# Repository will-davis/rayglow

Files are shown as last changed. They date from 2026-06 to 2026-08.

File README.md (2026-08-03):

# RayGLow

Audio-reactive GLSL visuals on a custom RGB LED wall. Music plays on a desktop; a small
daemon there reduces it to per-frame audio *features* and unicasts them over UDP to a
Raspberry Pi 5, which renders Shadertoy-dialect GLSL on its GPU, packs each frame, and
ships it over a **4-lane parallel bus** to an **RP2350b** microcontroller whose PIO+DMA
engine drives the HUB75 panels with zero-CPU, jitter-free timing. Write a shader, paste
it in, watch it move to the music.

https://github.com/user-attachments/assets/fb1bfaf4-e451-43c7-8cc3-830d7c186d91

```
desktop (optional)                 Raspberry Pi 5                         RP2350b PiZero + HAT
┌────────────────────────┐         ┌────────────────────────────┐         ┌───────────────────────┐
│ music ▶ sink monitor   │  UDP    │ feed.receiver (latest-win) │  4-lane │ phase6: PIO+DMA RX    │
│ sender.py: FFT ▶ bands │ ──────▶ │ render: GLSL ▶ pack        │   bus   │ zero-CPU scan-out     │
│ + flywheels/beat/key   │  :5005  │ (to_chains ▶ hub75.pack)   │ ──────▶ │ ▶ HUB75 ▶ 384×128 wall│
│ ▶ 2996-B v3 @ ~60 Hz   │ ~180KB/s│ headless EGL + GLES3       │ 192 KB  │ (2 chains × 12 panels)│
└────────────────────────┘         └────────────────────────────┘         └───────────────────────┘
        point $RAYGLOW_HOST ──────────────▶ your Pi
```

The three stages live in **one repo**. The desktop and Pi halves are Python: the desktop
runs `sender/`, the Pi runs the `rayglow` package installed editable (`pip install -e`)
from a copy of this repo — get it there however you like (`git pull`, or a continuous
file sync such as mutagen/sshfs for live shader editing). The RP2350b half is Rust
firmware (`firmware/`) flashed onto the board, plus a custom level-shifting HAT
(`hardware/`).
First-time setup is in [Deploy](#deploy); full credits and licensing are in
[ATTRIBUTION.md](ATTRIBUTION.md) (RayGLow is **MIT** — see [LICENSE](LICENSE)).

The desktop sender is **optional**: `rayglow.fake_sender` synthesizes the same packet
struct, so the Pi can drive the wall with no music source at all.

## Why features, not streamed audio

Streaming PCM means reconstructing a continuous signal on the far end: ring buffers,
clock-drift resampling, jitter buffers. Features are **stateless per frame** — a lost or
late packet just means the Pi renders with the previous values, and at 60 Hz one held
frame is invisible. The Pi does zero audio work, the wire carries ~0.25 MB/s, and UDP
gets used the way UDP wants to be used.

## Why offload scan-out to the RP2350b

Bit-banging HUB75 from a Linux SoC fights the scheduler — it needs a dedicated RT core
and still jitters (the Pi 5's RP1 southbridge made it worse). The RP2350b runs the refresh
loop entirely in **3 PIO state machines + 4 self-chaining DMA channels**, with the CPU
never touching the pixel path. The Pi renders at whatever rate it likes and ships 192 KB
frames over the link — already gamma-corrected on the Pi (the GPU resolve pass bakes
the firmware `lut.rs` CIE curve into each frame; `--readback legacy` instead applies
the packer's bit-exact LUT replica to a LINEAR readback); the RP2350b holds a
rock-steady, flicker-free refresh.

## Why a parallel bus, not SPI

The link was originally 1-lane SPI, and SPI still works as the proven fallback
(`--transport spi`). But a frame takes ~13 ms at 40 MHz SPI even at the v1 wall's 64 KB —
~39 ms at the v2 wall's 192 KB — long enough to sit squarely
on the critical path. A **4-lane source-synchronous parallel bus**, clocked out by the
Pi 5's RP1 PIO block, drops that to ~2 ms (clkdiv 3; ~1.3 ms at clkdiv 2). Only the wire
changes: the byte stream is identical to the SPI path (same `hub75.py` packer output,
same READY handshake), so the firmware and packer don't change. (4 lanes, not 8: the RP2350b scan-out engine owns
GP0–18, leaving GP19–27 for the link.) See
[`rayglow/render/piobridge/README.md`](rayglow/render/piobridge/README.md).

## Hardware

RayGLow custom HAT

A **Waveshare RP2350-PiZero** on a custom HAT that level-shifts (3.3 V → 5 V via
`SN74AHCT245`) and breaks out two HUB75 chains + the Pi↔RP2350b link. Design files, the
KiCad project, and fab Gerbers are in [`hardware/`](hardware/).

## Repo layout

| path | what |
|---|---|
| `sender/` | **desktop half** — the feature daemon (`sender.py`), its own uv project (numpy + sounddevice). [sender/README.md](sender/README.md) has the protocol + feature detail. |
| `rayglow/feed/` | the audio-feature feed: packet `receiver`, `FeatureState`, and the rig `config` (geometry/network/gamma). Shared, dependency-free. |
| `rayglow/render/` | **the live renderer** — headless EGL + GLES3, multipass pipeline, iChannel textures (`audio`, `milk`, noise, images), hot reload, a TCP **control plane** (`control.py`: push/switch shaders + media controls), the GPU resolve pass + zero-copy dma-heap readback (`output.py`, `dmabuf.py`), the frame packer (`hub75.py`) + link backends (`spi_out.py`, `pio_out.py` / `piobridge/`), and `presets/*.glsl`. |
| `rayglow/fake_sender.py` | music-free test harness; emits the same packet struct with synthesized features. |
| `rayglow/link.py` | **remote render wire contract** — frame fragments out, flip credits back (UDP, latest-wins, credit-paced; see [REMOTE-RENDER-PLAN.md](REMOTE-RENDER-PLAN.md)). Shared by `render/net_out.py` (`--output net`) and `framesink`. |
| `rayglow/framesink.py` | the Pi when rendering happens elsewhere: reassemble frames → `drm_out` page flip → credit per vblank. A socket and a memcpy — no GL stack. |
| `rayglow.example.toml` | per-machine CLI defaults (`rayglow/userconf.py`): pin each machine's flags (`output`, `net-host`, `window`, …) in `~/.config/rayglow/config.toml` so production launches are just `python -m rayglow.render <shader>` / `python -m rayglow.framesink`. CLI flags always override. |
| `rayglow/spi_test.py` | static test pattern (no GL) — isolates the link/firmware/cabling from the renderer. Per-panel ID markers confirm the serpentine fold; runs over either transport. |
| `firmware/` | **RP2350b Rust firmware** — zero-CPU PIO+DMA HUB75 scan-out, brought up in verifiable phases. [firmware/README.md](firmware/README.md). |
| `hardware/` | **custom HAT** — KiCad project, Gerbers, and the locked net/pinout spec. [hardware/README.md](hardware/README.md). |
| `tools/` | `verify.py` — proves the Python packer (`render/hub75.py`) is byte-identical to the firmware via a Rust golden frame. `fold_check.py` — proves the serpentine fold + the geometry/SRAM contract from the desk. `link_check.py` — locks the remote-render frame link (fragments/credits/pacing) over loopback. `dmabuf_probe.py` — the readback benchmark. |
| `ROADMAP.md` | queued workstreams — the living handoff doc between working sessions. |
| `docs/design-history/` | the original project record (MilkDrop reverse-engineering, the RP2350 plan, the build-history brain-dump). Superseded by the docs above where they disagree. |

## Quickstart

**Desktop (sender, optional):**
```fish
cd sender
set -x RAYGLOW_HOST 192.168.0.50   # your Pi's IP (or pass --host); see LOCAL-SETUP.example.md
uv run sender.py                   # capture default sink's monitor -> the Pi
uv run sender.py --list-sources    # enumerate pulse sources
uv run sender.py --debug           # + raw pre-normalization band energies
```

**Pi (renderer)** — see [Deploy](#deploy) for first-time setup:
```fish
# headless, no root, no hardware: render -> animated GIF (works on a desktop GPU too)
python -m rayglow.render rayglow/render/presets/milk-verbose.glsl --dry-run 120 --no-listen

# on the Pi, driving the panels (root for GPIO):
sudo ~/venv/bin/python -m rayglow.render rayglow/render/presets/milk-verbose.glsl
```
`milk-verbose.glsl` is the live-feed reference card — every audio feature drawn as a
labeled bar. Run the sender on the desktop at the same time to see it react.

## Deploy

**Renderer (Raspberry Pi 5).** The Pi runs the same git checkout, installed editable into
a uv venv:

```fish
# on the Pi, first time:
git clone <your-fork-url> ~/rayglow
cd ~/rayglow
uv venv ~/venv
uv pip install --python ~/venv/bin/python -e '.[pi]'   # core + Pi link deps
# thereafter: update the checkout (git pull, or let your file sync — e.g. a
# mutagen session pushing from the dev machine — keep it current)
```

`.[pi]` pulls the Pi-only deps (`spidev`, `gpiozero`, `lgpio`); EGL/GLES come from system
libraries, not pip. Editable install (not `PYTHONPATH`) because `sudo` scrubs the
environment but respects the installed package; hardware mode keeps root for GPIO and to
re-read shader files on hot reload, so the clone must live somewhere root can read (e.g.
under `~`).

- **Parallel link (default, `--transport pio`):** build `piobridge/libpioshim.so`
  against the RP1 `piolib` first — see
  [`rayglow/render/piobridge/README.md`](rayglow/render/piobridge/README.md).
- **SPI fallback (`--transport spi`):** enable SPI and make sure
  `/sys/module/spidev/parameters/bufsiz >= 196608` so the v2 wall's 192 KB frame goes in
  one transfer (the default 4096 is far too small; size it to `hub75.FRAME_BYTES`).

Per-machine addresses/paths: see [`LOCAL-SETUP.example.md`](LOCAL-SETUP.example.md).

**Firmware (RP2350b).** Flash the board once: `phase6-parallel --features two-chain`
for the 4-lane bus (production) or `phase5-spi` for the SPI fallback. Toolchain
bootstrap and `cargo run`/`probe-rs` instructions are in
[`firmware/README.md`](firmware/README.md).

## Status

Working end-to-end: the desktop sender feeds the renderer, which packs frames the
firmware accepts byte-for-byte (`tools/verify.py` is green). The renderer hot-reloads
`.glsl` files live (edit, save, watch the panel recompile); for the fast dev loop a TCP
control plane (`tools/rayglow_ctl.py push`, or the `tools/nvim-rayglow.lua` save-hook)
ships edits straight to the running renderer in <100ms — skipping the file-sync lag —
and adds media controls (next/prev/play/pause/loop) plus live per-shader supersample
scale (`// rayglow: scale=N` directive or `rayglow-ctl scale`). The Phase 6 4-lane parallel
bus is the production transport (hardware-verified on the custom HAT driving the 256×64 v1
wall; the 384×128 v2 wall is in bring-up — host + firmware ship, cabling/SI pending, see
ROADMAP §5); the Phase 5 SPI link remains the proven fallback. A microphone input path
exists (`sender/esp32-mic/` + `sender/espnow-dongle/`). Next: pulling config into a
user-editable yaml so the project runs on someone else's wall/network by editing one
file.

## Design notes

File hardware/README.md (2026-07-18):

# RayGLow hardware — RP2350-HUB75 HAT

The custom PCB that sits between the **Waveshare RP2350-PiZero** dev board and the
LED wall. It is deliberately minimal: it does **3.3 V → 5 V level-shifting** of all
HUB75 logic (via `SN74AHCT245` buffers), presents the **two HUB75 connectors**
(chains A & B = one 256×64 tile), breaks out the spare GPIO + power on J4 — which
now carries the Pi 5 ↔ RP2350 **4-lane parallel link** (DATA0–3/DCLK/READY, see
[`../rayglow/render/piobridge/README.md`](../rayglow/render/piobridge/README.md);
designed pre-fab as an SPI/sync breakout, same pins) — and carries a dedicated 5 V
rail for the buffers. It does **not**
power the panels (their 5 V goes straight to the panel lugs) and contains no MCU
support circuitry — the dev board owns crystal/flash/USB/core power.

See the repo-root [`README.md`](../README.md) for where this sits in the pipeline,
and [`../firmware/`](../firmware/) for the firmware that drives the panels through
this HAT.

## Doc map

| File | What |
|---|---|
| [`NET-SPEC.md`](NET-SPEC.md) | **The locked electrical spec** — component list, '245 mappings, HUB75 pinout, power/grounding rules. The input to schematic generation. Lock before editing the schematic. |
| [`POWER-AND-GROUNDING.md`](POWER-AND-GROUNDING.md) | **Bench-measured** power/ground findings (PicoScope): star-ground rules, ratiometric buffer-VCC, ground-bounce diagnosis, wire-gauge math, the 3-channel-PSU reality, HV-distribution v2. Refines NET-SPEC's buffer-rail note. |
| [`PIZERO-HEADER-PINOUT.md`](PIZERO-HEADER-PINOUT.md) | Physical header pin → **actual** RP2350 GPIO map, read off the board schematic. Critical: the Waveshare board is **not** standard Pi BCM (it transposes a few GPIO pairs). |
| [`NETLIST-REVIEW.md`](NETLIST-REVIEW.md) | QA notes on the generated netlist. |
| [`KICAD-AGENT-TOOLING.md`](KICAD-AGENT-TOOLING.md) | How the schematic was generated with SKiDL + which parts are human-in-the-loop (routing). |
| [`../docs/design-history/PROJECT-PLAN.md`](../docs/design-history/PROJECT-PLAN.md) | §6 (pin map) and §9 (HAT scope) — the original design intent. |

## Layout & fab

```
hardware/
├── NET-SPEC.md / PIZERO-HEADER-PINOUT.md / NETLIST-REVIEW.md   # design docs
├── POWER-AND-GROUNDING.md           # bench-measured power/ground findings
├── gen_hat.py / gen_hat_sklib.py    # SKiDL schematic generators (uv project)
├── pyproject.toml / uv.lock         # SKiDL + KiCad-symbol deps for the above
├── rp2350-hub75-hat.net             # generated netlist
├── rp2350-rgb-pcb/                  # the KiCad project (.kicad_pcb/.pro/.sch)
├── 3dprint/                         # enclosure STLs (base + cover)
└── fab/                             # plotted Gerbers + drill files (the fab deliverable)
```

The schematic is generated from `gen_hat.py` (run with `uv run gen_hat.py`); the
PCB layout (`rp2350-rgb-pcb/`) is hand-routed in KiCad. The `fab/` Gerbers are the
manufacturing output — send that folder (zipped) to a board house.

> Bench-gear note: the original plan's §14 instrumentation reality-check (e.g. the
> ≥100 MHz scope needed to validate 256-wide pixel-clock signal integrity) lives in
> [`../docs/design-history/PROJECT-PLAN.md`](../docs/design-history/PROJECT-PLAN.md).

## Wall v2 (in progress, ~80% assembled 2026-07-16)

This HAT drove the v1 256×64 wall (chains A & B, 4 panels each). The **v2 wall**
scales to **6 wide × 4 tall of P4-2121-64x32 tiles = 384×128 px** (1536×512 mm),
on a 2020 T-slot aluminium frame (2 horizontal + 4 vertical members) with
3D-printed panel connectors in [`3dprint/`](3dprint/) (`P4-*`, **WIP — not
committed until the PoC is built**; the tracked STLs there are the HAT enclosure).

**This same HAT and one RP2350b drive all 24 tiles** — no second board, no FPGA.
Each of the two HUB75 chains carries 12 panels serpentined across two panel rows
(J2 = the top half, J3 = the bottom half), which the Pi folds with
`render/hub75.to_chains`. The framebuffers land at 385 KB of the RP2350's 512 KB
SRAM (measured; 15 panels/chain is the ceiling), so the earlier "exceeds one
RP2350's envelope" concern was wrong — see [`../ROADMAP.md`](../ROADMAP.md) §5 for
the measurement and the refresh/brightness tradeoff. The open risk is **signal
integrity over a 12-deep chain** (only 4 was ever validated), settled on the bench.

Power moves to **2× 5 V/300 W/60 A** supplies split on the wall's horizontal
midline — the same boundary as the chain A/B split, so each rail's return current
stays inside its own chain's domain. See
[`POWER-AND-GROUNDING.md`](POWER-AND-GROUNDING.md) (§ "Wall v2").

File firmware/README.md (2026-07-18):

# RayGLow firmware (RP2350)

Zero-CPU HUB75 RGB-matrix scan-out engine for the **RP2350** (PIO + DMA),
driving 24× 64×32 panels (384×128) over two parallel chains of 12 — one chip for
the whole wall, at 385 KB of its 512 KB SRAM (the measured ceiling is 15
panels/chain = 30 panels; see [`../ROADMAP.md`](../ROADMAP.md) §5). This is the
downstream end of the RayGLow pipeline: the Pi 5 renders + packs frames and
ships them over the 4-lane parallel PIO bus (SPI as fallback — see the
repo-root [`README.md`](../README.md)); this firmware receives them and drives
the panels with deterministic, jitter-free timing. The crate (named
`rp2350-rgb-driver`, its original standalone-repo name) implements the design in
[`docs/design-history/PROJECT-PLAN.md`](../docs/design-history/PROJECT-PLAN.md)
one verifiable phase at a time.

## Status

| Phase | What | State | Bin |
|---|---|---|---|
| **0** | Bring-up: boot block, flash/boot path, blink + `defmt` RTT | ✅ hardware-verified | `phase0-blink` |
| **1** | Port kjagiello `hub75-pio-rs` to `rp235x-hal`, 1 chain × 1 panel | ✅ hardware-verified (RGB bars, gamma good) | `phase1-panel` |
| **3a** | Single-chain depth: 4 daisy-chained panels → 256×32 (SI test §11.7) | ✅ hardware-verified — SI clean at 37.5 MHz | `phase3-row` |
| **2** | Widen data path to 2 parallel chains (`out pins, 16`, `u16` cell) | engine done + init-verified — needs a 2nd panel on chain B | `phase2-dualchain` |
| **4** | Bulk frame repack + animation, double-buffered | ✅ hardware-verified — ~159 fps @ 64×64 (debug) | `phase4-anim` |
| 3 | Both chains × 4 deep → full 256×64 + coordinate mapper | superseded — the full wall runs via Phase 6 `--features two-chain` | — |
| **5** | Pi 5 → RP2350 SPI link (PIO SPI-slave RX + DMA into the inactive FB) | ✅ hardware-verified — now the **fallback** transport (`--transport spi`) | `phase5-spi` |
| **X** | **Single-chain** stop-gap: full 256×64 on ONE 8-panel serpentine chain via the spare Adafruit HAT (level-shifter only), SPI-fed. Uses the `u8` single-chain engine (`src/single.rs`, `Display1`) — 64 KB frames (not 128), `Display::flip` | retired with the custom HAT (kept for A/B rigs) | `phase-experimental` |
| **6** | **Pi 5 → RP2350 4-lane parallel link** (RP1-PIO TX → PIO1 RX + DMA into the inactive FB), single- or two-chain via the `two-chain` cargo feature | ✅ hardware-verified on the custom HAT — **the production transport** | `phase6-parallel` |
| QC | Custom-HAT board bring-up / pin-by-pin self-test | utility, not a milestone | `qc-test` |

> Note: `phase3-row` (single-chain 256×32) is run *before* the Phase 2 two-chain
> widening — a deliberate reorder to retire the signal-integrity risk early using
> the already-assembled panel row. The pixel clock is tunable via `DATA_CLK_DIV`
> in that binary.

> **Phase X (`phase-experimental`)** is a deliberate *deviation*, not a milestone:
> it lights the whole wall while the custom two-chain HAT is in fab, using the one
> Adafruit RGB Matrix HAT as a pure 3.3→5 V buffer and a single U-shaped chain of
> all eight panels (electrically 512×32, driven as **chain A only**; GP6–11 idle).
> It reuses the unchanged, verified engine at `W=512`. Cost: the `u16` cell makes
> the frame **128 KB** (half is the idle chain B) and refresh is ~½ the two-chain
> wall. The rpi5 must pack with the single-chain serpentine fold (bottom row
> 180°-rotated) — see the binary's header and `rayglow/render/hub75.py`.

## Layout

```
firmware/
├── Cargo.toml             # rp235x-hal 0.4, defmt, one [[bin]] per phase
├── rust-toolchain.toml    # pinned nightly + thumbv8m.main-none-eabihf target
├── memory.x               # RP2350 flash/RAM map + IMAGE_DEF boot-block sections
├── build.rs               # puts memory.x on the linker search path
├── .cargo/config.toml     # target, probe-rs runner, linker rustflags
├── src/
│   ├── lib.rs             # core HUB75 engine: DisplayMemory, PIO programs, DMA chain
│   ├── single.rs          # single-chain u8-cell engine (half-size frames)
│   ├── dma.rs             # low-level per-channel DMA register access (ported kjagiello)
│   └── lut.rs             # CIE/gamma LUT (ported kjagiello; matches render/hub75.py)
└── src/bin/
    ├── phase0_blink.rs    # bring-up: boot block + blink + RTT
    ├── phase1_panel.rs    # 1 chain × 1 panel (kjagiello port)
    ├── phase2_dualchain.rs# widen data path to 2 parallel chains
    ├── phase3_row.rs      # 1 chain × 4 panels = 256×32 (SI test)
    ├── phase4_anim.rs     # full 256×64 animated + bulk repack, double-buffered
    ├── phase5_spi.rs      # Pi 5 → RP2350 SPI link (fallback transport)
    ├── phase6_parallel.rs # Pi 5 → RP2350 4-lane parallel link (PRODUCTION; two-chain feature)
    ├── phase_experimental.rs # single-chain serpentine stop-gap (Adafruit-HAT era)
    └── qc_test.rs         # custom-HAT board bring-up self-test
```

## Toolchain bootstrap (one time)

If your system has Arch's pacman `rust` (stable, no `rustup`, no bare-metal
target), note that embedded RP2350 work needs `rustup` to manage a nightly
toolchain and the `thumbv8m.main-none-eabihf` (Cortex-M33) target.

```fish
# 1. Swap the system stable Rust for rustup (Arch-native; replaces `rust`).
sudo pacman -S rustup

# 2. rustup reads rust-toolchain.toml in this dir and installs the pinned
#    nightly + the thumbv8m target + components automatically on first cargo run.
#    (Force it now if you like:)
rustup show

# 3. probe-rs for flashing + RTT logging over the CMSIS-DAP debugprobe.
cargo install probe-rs-tools --locked

# Optional: UF2 / BOOTSEL path (no probe, no RTT logs)
# cargo install elf2uf2-rs --locked     # or build picotool from AUR
```

> Alternative if you'd rather not touch the pacman `rust` package: install
> rustup from <https://rustup.rs> (`rustup-init` into `~/.cargo`, no sudo). It
> shadows the system `rustc` via `~/.cargo/bin` on `PATH`. The pacman route is
> cleaner long-term (one toolchain manager, Arch-native).

## Build & flash

```fish
cd firmware

# Build only (host, no hardware needed):
cargo build --bin phase0-blink

# Flash + attach RTT logs (CMSIS-DAP debugprobe wired to the target's SWD):
cargo run --bin phase0-blink
```

`cargo run` invokes the configured runner `probe-rs run --chip RP235x`: it
flashes the ELF, resets, and streams `defmt` logs back to this terminal.

**Phase 0 is done when:** the LED blinks at 1 Hz and `blink N` lines stream over
RTT.

### Hardware notes

- **Board:** **Waveshare RP2350-PiZero (RP2350B, 16 MB flash)** — the project's
  main board. It has **no user-controllable LED** (only a hardwired power LED)
  and **no WS2812**. So Phase 0's heartbeat is the **`defmt` RTT counter**; for a
  *visible* blink, wire an external LED (+ ~330 Ω) from **GP25** to GND, or scope
  GP25. GP25 is free in the §6 pin map (HUB75 = GP0–18, chains C/D reserve
  GP19–21), so the wiring survives into later phases.
- **debugprobe:** a second Pico flashed with the CMSIS-DAP `debugprobe`
  firmware. Wire its SWD pins to the target's `SWCLK`/`SWDIO`/`GND`. probe-rs
  auto-detects it.
- **No probe?** Hold BOOTSEL, plug USB, and `picotool load -u -v -x -t elf
  target/thumbv8m.main-none-eabihf/debug/phase0-blink` (no RTT logs that way).

## RP2350-specific notes

- **Boot block, not boot2.** The RP2350 Boot ROM scans the first 4 KiB of flash
  for an `IMAGE_DEF` block (`#[link_section = ".start_block"]` in each binary,
  sections defined in `memory.x`). There is no RP2040-style `boot2`.
- **Target is `thumbv8m.main-none-eabihf`** (Cortex-M33), *not* the RP2040's
  `thumbv6m`.
- **GPIO erratum E9** (input pads latching high) is irrelevant to our outputs
  but will matter for the Phase 5 SPI link input pins — handle there.

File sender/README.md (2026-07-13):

# sender — RayGLow desktop feature daemon

The broadcast half of RayGLow. `sender.py` (one file) captures whatever the desktop is
playing, reduces it to a handful of per-frame audio features, and unicasts them over UDP
at ~60 Hz to the Pi, which renders them as GLSL and drives a 256×64 HUB75 wall (via an
RP2350 over a 4-lane parallel PIO bus). For the system-level picture and the renderer,
see the [top-level README](../README.md).

This is a standalone uv project: it shares no code with the `rayglow` package — only the
**packet contract** (mirrored in `rayglow/feed/receiver.py`). The daemon only ever
*runs* on the desktop, since it's capturing desktop audio.

Two hardware senders live alongside it, for feeding the wall from a room microphone
instead of the desktop's audio: [`esp32-mic/`](esp32-mic/) (ESP32 + I2S mic firmware
that computes the same features on-chip) and [`espnow-dongle/`](espnow-dongle/) (an
ESP-NOW → UDP bridge for the Pi). Each has its own README.

## Running

```fish
cd sender
uv run sender.py                  # monitor of default sink -> 192.168.0.50:5005
uv run sender.py --list-sources   # enumerate pulse sources
uv run sender.py --source NAME    # capture a specific source instead
uv run sender.py --debug          # adds raw pre-normalization band energies
uv run sender.py --host H --port N --fps N
```

Prints a 1 Hz status line (the 8 band values, vol, bpm/conf, bar phase, key, centroid,
pan; `--debug` adds the legacy bands and raw energies) and a startup banner with the
packet size + spectrum-axis constants (mirror those into `milk-spectrum.glsl` if the
axis ever changes). Python ≥3.13,
numpy + sounddevice; `pactl` must be on PATH. Capture mechanics: the ALSA "pulse"
PortAudio device is a PipeWire/Pulse client, and the `PULSE_SOURCE` environment variable
selects which source it records — which is why `sender.py` defers `import sounddevice`
until *after* setting it.

## The features

Everything rides on **AutoGain**, ported from MilkDrop (`plugin.cpp:8750`): each band is
divided by its own long-running average. So a band value of **1.0 means "typical for
this song right now"** — quiet passages dip toward ~0.5, hits spike to 2–4 — regardless
of genre, mastering level, or system volume. This is why one shader works for
everything. Each band also has an `_att` twin (temporally smoothed: slow swells instead
of per-frame punch).

### The v3 bands + flywheels (the primary feed)

8 log-spaced bands, `b0`–`b7`, edges **20 | 60 | 120 | 250 | 500 | 1000 | 2500 | 6000 |
16000 Hz** (`BAND_EDGES_V3`, one tunable table). The low four read the 4096-pt spectrum
FFT (11.7 Hz/bin — real low-end resolution; b0's floor is effectively ~23 Hz, its first
usable bin), the high four the snappy 576-window/1024-pt FFT (12 ms). **No equalize on
either** — the per-band AutoGain *is* the leveling. Per band:

| field | what it is |
|---|---|
| `band_imm[8]` | instant AutoGained level (clamped ≤ 16 against AGC blow-ups on quiet bands) |
| `band_env[8][3]` | the **flywheel envelopes** (`ENV_TIERS`): tier0 = symmetric ~125 ms lag (the classic env feel); tier1 = punchy, ~60 ms attack / ~500 ms decay; tier2 = heavy, ~150 ms attack / ~2 s decay. A kick slams a tier up and it sails down — "momentum" |
| `band_theta[8][3]` | "music time" phase accumulators, wrap at 200π: theta0 integrates imm, theta1 env1, theta2 env2 — iTime replacements whose rotation *accelerates* with the music instead of stepping |
| `band_onset[8]` | per-band half-wave-rectified flux, own AutoGain — one-sided attack spikes (the useful half of the retired d/dt) |
| `vol_imm, vol_env[3], vol_theta[3]` | the same treatment for overall level |

All envelope/theta integration happens **here**, on the sender's steady wall clock —
the Pi just uploads texels (pre-v3 it integrated against jittery packet arrival times).

### Legacy layer (unchanged MilkDrop port, still shipped)

| field | what it is |
|---|---|
| `bass`, `mid`, `treb` | MilkDrop's three bands: 576-sample window → Hann → 1024-pt FFT → 512 bins × log-equalize → three equal *linear* thirds of the bottom half ≈ 0–4 / 4–8 / 8–12 kHz at 48 kHz |
| `vol` | sum of the three, own AutoGain |
| `wave[512]` | mono waveform window, resampled 576 → 512, ±1.0 |
| `sub`, `sub_att` | **v1, not MilkDrop**: true sub-bass. MilkDrop's "bass" covers 0–4 kHz with a log-equalize that suppresses the lowest bins ~90× — a subwoofer is invisible in it. `sub` uses a separate 2048-sample FFT (23.4 Hz/bin), *no* equalize, bins 1–5 = 23–117 Hz, own AutoGain |

The MilkDrop chain is ported from the actual code, not its comments (`fft.cpp` comments
recommend octave bands; the code uses linear thirds — `sender.py` cites the source lines
inline). Deprecated-but-stable: these keep pre-v3 shaders exact via the milk texture's
legacy texel block.

### Spectrum / chroma / beat / stereo / key

From the same 4096-sample FFT (`SpectrumAnalyzer`, 11.7 Hz/bin, ~85 ms window):

| field | what it is |
|---|---|
| `spec[128]` | real spectrum, 30 Hz–16 kHz, dB-normalized 0..1 (v2 shipped 512 — the wall can't use that density). Hybrid **linear-then-log** axis: first 23 bins linear at one FFT bin each (→~300 Hz), the rest log to 16 kHz, so every bin carries real FFT data (no interpolated low-end holes). Axis constants printed in the startup banner. |
| `chroma[12]` | pitch-class energy C…B (fold FFT bins → 12 semitones, peak-normalized) — for color-by-key |
| `centroid, flux, flatness, rolloff, crest` | spectral descriptors: brightness, onset strength (auto-gained), tonal-vs-noisy, 85%-rolloff, peakiness |
| `bpm, beat_phase, bar_phase, beat_conf` | the **predictive beat tracker** (`beat.py` — clean-room DAFx-09, *not* MilkDrop): comb-filterbank tempo induction + cumulative-score alignment + a slew-limited PLL beat grid. `beat_phase` ramps 0→1 and hits 1.0 **on** the predicted beat (anticipatory, not reactive); `bar_phase` spans 4 beats. BEAT/DOWNBEAT pulses ride `flags`. Validate with `uv run beat.py` (offline click-track harness) |
| `width, pan` | stereo correlation (mono↔anti-phase) and L/R balance, time-domain from the right channel the band path ignores |
| `key_idx, key_conf` | musical key via Krumhansl-Schmuckler correlation on a ~3 s chroma EMA: 0–11 = C…B major, 12–23 = minor. A mood signal — gate on the confidence |

`flags` carries a 4-bit **source_domain** (0 = audio) plus the BEAT/DOWNBEAT bits, so
non-audio senders (SDR, telemetry) self-label.

## Packet — v3, little-endian, 2996 bytes

`PACKET_FMT = "<IHHIf7f2f8f24f24f8f7f512f128f12f5f4f2f2f"` in `sender.py`; mirrored
(with the size asserted) in `rayglow/feed/receiver.py` and `rayglow/fake_sender.py` —
`tools/feed_check.py` asserts all three stay identical and roundtrips every field.
**Any layout change must land on all ends and bump `version`.** The receiver dispatches
on `(version, exact byte length)` and accepts v0 (556 B), v1 (564 B, `sub = bass` for
v0), v2 (4236 B) and v3 — older senders report zeros/defaults for fields they don't
carry. At ~3 KB × 60 Hz ≈ 0.18 MB/s it's a single UDP datagram (well under the ~65 KB
datagram ceiling).

The header + legacy fields keep their v2 byte positions, so the receiver's common parse
path is version-agnostic; everything after `sub_att` is v3's own layout.

| offset | type | field |
|---|---|---|
| 0 | uint32 | magic = `0x4D494C4B` ("MILK") |
| 4 | uint16 | version = 3 |
| 6 | uint16 | flags — bits 0–3 source_domain, bit 4 BEAT, bit 5 DOWNBEAT |
| 8 | uint32 | seq — wraps at 2³²; receiver drops stale/reordered (RFC 1982-style compare) |
| 12 | float32 | t — sender monotonic seconds |
| 16 | float32[7] | bass, mid, treb, bass_att, mid_att, treb_att, vol (legacy) |
| 44 | float32[2] | sub, sub_att (legacy) |
| 52 | float32[8] | band_imm — b0…b7 |
| 84 | float32[24] | band_env — [band][tier], band-major |
| 180 | float32[24] | band_theta — [band][tier], band-major, mod 200π |
| 276 | float32[8] | band_onset |
| 308 | float32[7] | vol_imm, vol_env[3], vol_theta[3] |
| 336 | float32[512] | wave |
| 2384 | float32[128] | spec — hybrid lin/log spectrum, dB-norm 0..1 |
| 2896 | float32[12] | chroma — pitch classes C…B |
| 2944 | float32[5] | centroid, flux, flatness, rolloff, crest |
| 2964 | float32[4] | bpm, beat_phase, bar_phase, beat_conf |
| 2980 | float32[2] | width, pan |
| 2988 | float32[2] | key_idx, key_conf |
| **2996** | | **total** |

Receiver discipline (`rayglow/feed/receiver.py`): bind once, drain the socket
nonblocking every frame keeping only the highest seq, never block the render loop. No
packet for 0.5 s → `FeatureState` switches to a synthesized fallback (bands breathing
around 1.0, fake beat) so the panel never freezes or goes dark.

## How the features reach shaders

`rayglow.render` exposes the feed as `iChannel` textures, bound per-shader with comment
directives (`// iChannel0: milk`) or `--channelN` flags:

- **`milk`** — a 16×3 RGBA32F texture (float: the >1.0 spikes survive; read with
  `texelFetch`). **Row 0** cols 0–7 = b0…b7, col 8 = vol: `.x` imm, `.y/.z/.w` the three
  envelope tiers. **Row 1**, same cols: `.x/.y/.z` theta0/1/2, `.w` onset. **Row 2**
  globals: (0,2) tempo block, (1,2) beat/downbeat pulses + key, (2,2) descriptors,
  (3,2) crest + stereo, (4–6,2) chroma, (7,2) feed health (`pkt_age`/`live`/
  `source_domain`), and (9–11,2) the **legacy block** — the classic
  bass/mid/treb/vol/sub scalars, so pre-v3 shaders port 1:1. Full map:
  `rayglow/render/textures.py` (`MilkChannel`); reference cards that draw every float as
  a labeled bar — `milk-verbose.glsl` (bands/motion) and `milk-features.glsl` (globals).
- **`spectrum`** — a 128×1 RGBA32F texture: `.x` the real spectrum on the hybrid
  lin/log axis (30 Hz–16 kHz, full float range, no waveform round-trip); `.y`/`.z`
  smooth Catmull-Rom curves through the 8 band values (imm / env1) on the same axis —
  a ready-made "fit of the bands" for silky spectrum-shaped visuals. Sample like a 1-D
  LUT; reference card `milk-spectrum.glsl`. Zero on a v0/v1 sender.
- **`audio`** — the shadertoy.com-faithful 512×2 spectrum/waveform texture, so stock
  shaders work unmodified. The spectrum row is rebuilt Pi-side from `wave` (Web-Audio dB
  scaling, 0.8 smoothing) — faithful to the site, which means heavily compressed: bass
  pins near 1.0 whenever music plays. For dynamic band values use `milk`; for a real
  spectral shape use `spectrum`.

Division of labor: the **desktop** (this daemon) computes everything — FFTs, AutoGain,
envelopes, thetas, beat, key — on its steady clock; the **Pi** just packs texels.
(Pre-v3 the Pi derived d/dt/env/theta itself, inheriting packet-arrival jitter.)

### Porting pre-v3 shaders (old 13×1 texel → new 16×3)

| old | new |
|---|---|
| (0,0)/(1,0)/(2,0) bass/mid/treb `.x` imm | (9,2) `.x/.y/.z` (legacy, identical) — or bands (2,0)/(5,0)/(7,0) `.x` |
| (3,0) vol, (4,0) sub `.x` | (9,2)`.w`, (10,2)`.w` (legacy) |
| `.y` att (bass/mid/treb/sub) | (10,2)`.x/.y/.z`, (11,2)`.x` (legacy) |
| `.w` env (per band) | `.y` env0 of the nearest v3 band: b2/b5/b7/vol(8,0)/b0 |
| `.z` ddt | dropped — one-sided analog: row 1 `.w` onset of the nearest band |
| (5,0) thetas b/m/t/v, (6,0).x sub theta | (2,1)/(5,1)/(7,1)/(8,1)/(0,1) `.x` theta0 |
| (6,0) `.y` age `.z` live `.w` source | (7,2) `.x/.y/.z` |
| (7,0) descriptors | (2,2) |
| (8,0) crest/bpm/phase/conf | (3,2)`.x` + (0,2)`.x/.y/.w` |
| (9,0) beat/downbeat/width/pan | (1,2)`.x/.y` + (3,2)`.y/.z` |
| (10–12,0) chroma | (4–6,2) |

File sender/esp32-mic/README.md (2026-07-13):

# esp32-mic — microphone feature-sender

An ESP32 alternative to the desktop `../sender.py`. It listens through an INMP441
I2S MEMS microphone, runs a faithful C++ port of the MilkDrop band analysis, and
unicasts the **identical v1 UDP feature packet** (564 B) to the Pi renderer at
60 Hz. Because it's a standalone battery-/USB-powered box, the audio pickup can
live anywhere — decoupled from the Pi and the panel.

It shares **no code** with `sender.py` — only the packet contract
(`rayglow/feed/receiver.py`'s v1 layout), re-ported here.

> **Run one sender at a time per Pi.** This and `sender.py` share the same `seq`
> space; the receiver is latest-wins and they'd fight. The ESP *replaces* the
> desktop sender for a rig.

**Transports:** the send path is pluggable behind `src/transport.h`. The default
build (`s3zero`) uses WiFi/UDP (`net_udp.cpp`, keeps OTA). The production build
`s3zero-espnow` (`-D TRANSPORT_ESPNOW`, `net_espnow.cpp`) sends via **ESP-NOW** to
the `../espnow-dongle` receiver instead — lower jitter, no WiFi. Set `DONGLE_MAC`
+ `ESPNOW_CHANNEL` in `config.h`; flash over USB-C (no OTA in that build). See
`../espnow-dongle/README.md` for the full ESP-NOW link + Pi wiring.

## Hardware

**Board:** Waveshare ESP32-S3-Zero (ESP32-S3FH4R2, 4 MB flash / 2 MB PSRAM,
native USB-C). Also builds for an ESP32-WROOM-32 via the `esp32dev` env — the
I2S API is identical, only the pins differ. **Mic:** INMP441 I2S MEMS breakout.

INMP441 → S3-Zero wiring (pins set in `platformio.ini`, env `s3zero`):

| INMP441 | S3-Zero pad | notes |
|---|---|---|
| VDD | 3V3 | not 5V |
| GND | GND | |
| L/R | GND | selects the LEFT I2S slot |
| WS | IO6 | word select (LR clock) |
| SCK | IO5 | bit clock |
| SD | IO4 | serial data out → ESP `din` |

Pins IO4/5/6 are safe general GPIOs. Avoid **IO19/IO20** (native USB D−/D+),
**IO21** (onboard WS2812 RGB LED), and strapping pins **IO0/IO3/IO45/IO46**.

WROOM equivalents (env `esp32dev`): SD=IO32, SCK=IO14, WS=IO15.

## Toolchain

PlatformIO Core (CLI), installed via uv:

```fish
uv tool install platformio          # provides ~/.local/bin/pio
```

Serial access on Arch: install PlatformIO's udev rules once (sets the port to
mode 0666 and stops ModemManager grabbing it). Covers both the WROOM's CP210x
(`10c4:ea60` → `/dev/ttyUSB0`) and the S3-Zero's native USB-Serial/JTAG
(`303a:*` → `/dev/ttyACM0`):

```fish
sudo cp ~/.local/share/uv/tools/platformio/lib/python*/site-packages/platformio/assets/system/99-platformio-udev.rules /etc/udev/rules.d/
sudo udevadm control --reload-rules && sudo udevadm trigger --subsystem-match=tty --action=add
```

## Configure

```fish
cp src/config.example.h src/config.h   # already present with placeholders
$EDITOR src/config.h                    # set WIFI_SSID/PASS, RAYGLOW_HOST (Pi IP)
```

`config.h` is gitignored (creds stay local, mirroring the repo's LOCAL-SETUP
convention).

## Build & flash

```fish
cd sender/esp32-mic
pio run                                 # build the default s3zero env
pio run -e s3zero -t upload -t monitor  # USB flash + open serial (115200)
```

**First flash over native USB:** the S3-Zero has no UART bridge — flashing and
the serial console both ride the S3's built-in USB (it enumerates as
`/dev/ttyACM0`). PlatformIO auto-resets into the bootloader, but if the first
upload can't connect, enter download mode by hand: **hold BOOT (IO0), tap RESET,
release BOOT**, then re-run upload. After that first flash, `ARDUINO_USB_CDC_ON_BOOT`
keeps `Serial` on the USB-C cable so `-t monitor` works normally.

You should see a 1 Hz status line once WiFi is up:

```
bass 1.03 mid 0.98 treb 1.12 sub 0.87 vol 1.01 | raw b/m/t 0.0142/0.0091/0.0033 sub 0.0007
```

### OTA (after the first USB flash)

```fish
set -x RAYGLOW_MIC_IP <device-ip>
set -x RAYGLOW_MIC_OTA_PASS rayglow-ota   # must match OTA_PASSWORD in config.h
pio run -e s3zero-ota -t upload
```

### The ESP32-WROOM-32 (interim dev board)

```fish
pio run -e esp32dev -t upload   # same source, different board + pins
```

## Verify the wire contract

Point `RAYGLOW_HOST` at your desktop and run this to confirm the receiver would
accept the packets (correct length, magic, version, advancing seq):

```fish
python - <<'PY'
import socket, struct
s = socket.socket(socket.AF_INET, socket.SOCK_DGRAM); s.bind(("0.0.0.0", 5005))
for _ in range(5):
    d, a = s.recvfrom(2048)
    magic, ver, flags, seq = struct.unpack_from("<IHHI", d, 0)
    print(f"from {a[0]} len={len(d)} magic={magic:#010x} v{ver} flags={flags} seq={seq}")
    assert len(d) == 564 and magic == 0x4D494C4B and ver == 1
print("OK: valid v1 packets")
PY
```

Then, on the panel (desktop sender stopped):

```fish
sudo ~/venv/bin/python -m rayglow.render rayglow/render/presets/milk-verbose.glsl
```

The reference card should react to whatever the mic hears. Band placement check:
play 110 Hz / 6 kHz / 10 kHz tones near the mic → bass / mid / treb light up.

## Design notes

- **Calibration parity:** `SAMPLE_RATE`, `WINDOW`, `NFREQ`, the `EQUALIZE` table,
  `BAND_EDGES`, the 2048-pt sub window, and `AutoGain` all mirror `sender.py`
  exactly, so the Pi's texel calibration needs no change. The mic's acoustic
  response differs from line level, but AutoGain self-normalizes ("1.0 =
  typical"), so absolute scale doesn't matter.
- **Pacing:** the loop is paced by the I2S clock — a blocking read of `CHUNK`
  (800) samples takes exactly 1/60 s, so the audio hardware *is* the 60 Hz
  timebase. No separate wall-clock timer.
- **FFT seam:** `fft.{h,cpp}` has two backends behind one `fft_mag()`. The S3
  env (`-D USE_ESP_DSP`) links the precompiled `libespressif__esp-dsp.a` that
  ships inside `framework-arduinoespressif32-libs` (no lib_deps needed - just the
  include dirs + `-l` in `platformio.ini`) and calls `dsps_fft2r_fc32`, which
  dispatches to the S3's SIMD (`aes3`) path. The WROOM env keeps the portable
  scalar radix-2. Measured: DSP 5.2 ms scalar -> 2.5 ms SIMD.
- **Latency tuning:** `CHUNK` (in `dsp.h`) trades latency vs real-time margin -
  the loop period is `max(compute, CHUNK/48000)`, so `CHUNK` must exceed
  `compute*48000` or the DMA backlogs. With SIMD compute ~3 ms, `CHUNK=256`
  (5.33 ms, 187 Hz) is the current pick. The 1 Hz serial line reports per-stage
  `wait/dsp/send` ms so you can retune empirically. Remaining latency is now
  dominated by WiFi jitter (measure with `ping` from the Pi) and the inherent
  ~21 ms group delay of the 2048-pt sub window (shrink `SUB_WINDOW` to trade
  sub-bass resolution for snap).
- **Scope:** emits v1 (bands + true sub). v2 (spectrum/chroma/beat) is a future
  add via the same FFT seam; stereo stays zero (mono mic).

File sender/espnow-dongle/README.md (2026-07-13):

# espnow-dongle — ESP-NOW → UART receiver for the Pi

A **Seeed XIAO ESP32-C3** that lives inside the Pi case, receives v1 feature
packets over **ESP-NOW** from the `../esp32-mic` sender, and relays them verbatim
to the Pi over **UART**. A small Pi-side bridge (`pi_bridge.py`) forwards them to
the renderer's UDP port — so `rayglow/feed/receiver.py` is **unchanged** and the
desktop `sender.py` can still override on the same port (latest-wins).

Why: ESP-NOW is connectionless (no AP, no association, no IP stack), which removes
the WiFi/UDP failure modes — AP-buffering jitter and lwIP TX-pool `ENOMEM` — that
the congested 2.4 GHz band was causing. Verified: `tx == rx == fwd`, `fail 0`.

```
S3 mic (pure ESP-NOW, ch 1) ──unicast v1 564B──▶ XIAO C3 dongle
    ──UART (D6/GPIO21 TX → Pi RX, 921600 8N1)──▶ pi_bridge.py ──UDP──▶ 127.0.0.1:5005 ──▶ receiver.py
```

## Wiring — XIAO C3 → Raspberry Pi 5

Only three wires (data is one-way, dongle → Pi). All 3.3 V logic — **no level
shifter**. The **U.FL antenna must be attached** (mount it outside the case).

| XIAO C3 pad | → | Pi 5 header | Notes |
|---|---|---|---|
| **5V**  | → | pin **2** (5V) | powers the C3 via its onboard LDO |
| **GND** | → | pin **6** (GND) | common ground |
| **D6 / GPIO21 (TX)** | → | Pi **GPIO9 / pin 21** (uart3 RXD3) | data: dongle → Pi |

**Off-limits Pi pins** (used by the default PIO panel transport — `render/pio_out.py`):
BCM **12,13,14,15** (DATA0-3), **20** (DCLK), **21** (CS), **25** (READY). That's
why we can't use the primary UART on pins 8/10 (BCM14/15). GPIO8/9 (SPI0, unused
in PIO mode) are free, and that's where `uart3` lives on the Pi 5.

## Enable the spare Pi UART

**Pi-5 gotcha:** `dtoverlay=uart3` is documented as GPIOs 4-7 but that's *BCM2711
(Pi 4) only*. On the **Pi 5**, uart3 maps to **GPIO8 (TXD3) / GPIO9 (RXD3)** — so
the dongle's TX wires to **GPIO9 = physical pin 21**. Use the Pi-5 overlay name:

```
dtoverlay=uart3-pi5      # GPIO8/9; plain `uart3` also resolves here on Pi 5
```

Reboot, then confirm the node + pin mapping (this is the authoritative check —
don't trust the overlay's advertised pins):

```fish
ls -l /dev/serial* /dev/ttyAMA*        # the new UART, e.g. /dev/ttyAMA3
pinctrl get | rg 'RX|TX'               # expect: 9: ... GPIO9 = RXD3
```

Wire the dongle TX to whichever GPIO shows as `RXDn`, at its physical pin.

## ESP-NOW channel + dongle MAC

Both ends are pinned to **channel 1** (`ESPNOW_CHANNEL` in `src/main.cpp` and the
mic's `config.h` — they must match). The dongle prints its MAC on boot; that value
goes into the mic's `config.h` as `DONGLE_MAC`. This dongle's MAC:
`98:3D:AE:AC:A6:60` → `#define DONGLE_MAC {0x98,0x3D,0xAE,0xAC,0xA6,0x60}`.

## Build & flash the dongle (over USB, before sealing the case)

```fish
cd sender/espnow-dongle
pio run -e xiao_c3 -t upload -t monitor    # native USB -> /dev/ttyACM*
```

Boot print shows the MAC + a 1 Hz `rx / fwd / bad` counter. Flash it **before**
mounting — its relay firmware is stable, so no OTA is needed inside the case.

## Run the Pi bridge

The Pi venv gets `pyserial` from the `.[pi]` extra:

```fish
uv pip install --python ~/venv/bin/python -e '.[pi]'
```

Run it (point `--port` at the UART from above):

```fish
~/venv/bin/python sender/espnow-dongle/pi_bridge.py --port /dev/ttyAMA3 --baud 921600 --debug
```

Or install the service (`rayglow-mic-bridge.service` — edit paths/port/user first):

```fish
sudo cp rayglow-mic-bridge.service /etc/systemd/system/
sudo systemctl daemon-reload && sudo systemctl enable --now rayglow-mic-bridge
journalctl -u rayglow-mic-bridge -f
```

## Verify end-to-end

1. **Dongle** (`pio ... -t monitor`): `rx N  fwd N  bad 0` climbing when the mic runs.
2. **Mic** (`esp32-mic`, flashed with `-e s3zero-espnow`): `ESP-NOW ... tx N fail 0`.
3. **Bridge** (`--debug`): `fwd N/s`. Confirm the renderer's socket sees it:
   ```fish
   python3 -c "import socket,struct; s=socket.socket(2,2); s.bind(('0.0.0.0',5005))
   [print(a[0],len(d),'seq',struct.unpack_from('<I',d,8)[0]) for d,a in (s.recvfrom(2048) for _ in range(5))]"
   ```
   → `127.0.0.1 564 seq …` climbing.
4. **Panel:** bridge running, `sender.py` stopped → the wall reacts to the mic.

## Override with the pure desktop feed

The bridge is a drop-in UDP source. To hand control to the ambient-free pipewire
feed: `sudo systemctl stop rayglow-mic-bridge` and run `sender.py` on the desktop.
Restart the bridge to return to the mic. (Shared `seq` space = one active source
at a time.)

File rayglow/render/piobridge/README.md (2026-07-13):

# piobridge — 4-lane parallel Pi 5 → RP2350 link (Workstream 3)

Replaces the 1-lane SPI transport with a **4-lane source-synchronous parallel
bus** driven by the Pi 5's RP1 PIO block, lifting the link off the critical path
(the 64 KB frame goes from ~13 ms at 40 MHz SPI to ~2 ms at clkdiv 3 / ~1.3 ms
at clkdiv 2). This is the **default transport** (`--transport pio`).

(4 lanes, not 8: the RP2350 board exposes GP0–27 and the scan-out engine owns
GP0–18, leaving only GP19–27 for the link — see `phase6_parallel.rs`.)

The stream is **byte-identical** to the SPI path — same `hub75.py` packer output,
same CS-framing + READY handshake — so only the wire changes, not the protocol.

## Pieces
- `pio_shim.c` → `libpioshim.so` — flat C ABI over RP1 `piolib` (whose API is
  `static inline`, so ctypes can't call it directly). Drives `out pins, 4` + a
  sideset data clock, DMA-fed.
- `rayglow/render/pio_out.py` — `PioOut`, the `SpiOut`-compatible transport that
  loads the shim and frames each burst with CS (gpiozero) + READY.
- Firmware: `firmware/src/bin/phase6_parallel.rs` (`cargo run --bin phase6-parallel`).

## Pin map — the custom HAT's J4 breakout (BCM ↔ J4 pin ↔ RP2350 GP)
| signal | rpi5 BCM | J4 pin | RP2350b GP | notes |
|---|---|:---:|---|---|
| DATA0..3 | GPIO12..15 | 1–4 | GP19..GP22 | 4 contiguous lanes, `out pins,4` base = GPIO12 |
| DCLK | GPIO20 | 5 | GP26 | Pi-driven data clock (sideset) |
| READY | GPIO25 (in)  | 6 | GP27 (out) | RP2350 → Pi: armed-and-waiting |
| 3V3 / GND | — | 7 / 8  | — | reference + a return beside the lane bundle; keep short |
| CS (reserve)| GPIO21 | — | GP25 | OFF by default. See below. |

**CS is dropped by default** — J4 only has 6 GPIO and 4-data+DCLK+CS+READY needs 7.
The frame is delimited by READY + the fixed frame size; the firmware's `sm.restart()`
+ RX_STALL watchdog re-sync any corrupt frame. To re-enable CS (noisy setups): GP25
is unrouted on the HAT but reaches the **protruding J1 header pin 22**, so jumper a Pi
GPIO (default GPIO21) onto it, build the firmware with `USE_CS = true`, and pass
`--pio-cs`. Both ends must agree.

Confirm none of GPIO12–15/20/21/25 are reserved on your Pi (PWM/I2S/PCM can claim
some) before wiring.

## Build & run (on the Pi)
1. Build piolib as a library (once):
   ```fish
   cd .reference/rpi5/utils/piolib
   cmake -DBUILD_SHARED_LIBS=1 . ; and make
   ```
   Ensure `/dev/pio0` exists and is group-accessible (piolib README: udev rule +
   `gpio` group) so it runs without root if desired.
2. Build the shim:
   ```fish
   cd rayglow/render/piobridge ; and make
   ```
   (`make PIOLIB=/path/to/piolib` if it lives elsewhere.) Produces `libpioshim.so`
   here; `pio_out.py` loads it from this directory.
3. Flash the firmware: `cd firmware ; and cargo run --bin phase6-parallel`.
4. Run the renderer with the parallel transport:
   ```fish
   cd /tmp   # local CWD — keeps lgpio's runtime FIFO out of the synced repo tree
   sudo ~/venv/bin/python -m rayglow.render <shader> --pio-clkdiv 4   # pio is the default transport
   ```

## Bring-up order (don't skip)
1. **Logic-analyzer first.** At a high `--pio-clkdiv` (slow), send a known ramp and
   confirm the bytes land correctly on the RP2350 side (a debug `info!` of the
   first framebuffer cells, or picotool). Two things to confirm:
   - **Nibble order** — each byte goes out as two nibbles (low then high under the
     default swap). If every byte's nibbles come out swapped, run with
     `--pio-no-nibble-swap` (no reflash needed).
   - **Lane↔bit** — within a nibble, lane i = bit i (DATA0 = bit 0). If mirrored,
     reverse the physical lane wiring (DATA0↔DATA3, DATA1↔DATA2).
2. **Then on-panel**, compare a static test pattern against the SPI path — they
   must be pixel-identical (same bytes). Then lower `--pio-clkdiv` toward 1 and
   watch `rx fps` / drops; the READY handshake self-paces exactly as SPI did.

`--transport spi` stays the proven fallback throughout.

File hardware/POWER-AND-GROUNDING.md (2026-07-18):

# RayGLow power & grounding — bench findings

Derived empirically on **2026-06-28/29** with a PicoScope 2204A while characterizing
whether the Pi 5 + RP2350 could share the panel 5 V rail. The short version: the
"PSU sag" was mostly **ground bounce in the measurement** + **wire IR drop**, not the
supply collapsing — and the level-shifter logic must be powered **ratiometrically**
from the panel rail, not from a clean rail.

## TL;DR rules (do these)

1. **Single-point star ground at the PSU (−) terminal.** Every return — each panel
   channel's GND and the logic/SBC GND — lands as its *own* conductor on the *same*
   lug. Never daisy-chain logic ground off panel ground. The only other GND bridge is
   the HAT plane ↔ panel via the HUB75 ribbon, which must carry **signal return only**.
2. **Power the '245 buffer VCC from the *panel* 5 V (ratiometric), not a clean rail.**
   The panels compare incoming HIGH against *their own* sagging VCC/GND. If the buffers
   sit at 5.0 V while the panel rail is at 4.1 V, the data lines are ~0.9 V above panel
   VCC → input protection diodes conduct (clamp/latch-up risk). Tracking the panel rail
   keeps HIGH ≤ panel VCC and the logic margin ratiometric. **⚠️ Reconcile with
   [`NET-SPEC.md`](NET-SPEC.md)** — its "dedicated 5 V rail for the buffers" is only
   correct if that rail is sourced from the **panel-side** 5 V at the panel reference.
3. **Heavy copper for the high-current path; no CCA.** Beyond resistance, aluminum
   oxidizes at crimp/screw terminations (Al₂O₃ is insulating) → connection resistance
   grows into hot spots.
4. **Local bulk decoupling** at the HAT/buffer 5 V node knocks down the fast component.
5. **Cap global brightness** — cheapest single lever; cuts peak current → less drop,
   less heat, less bounce, all at once.

## What was measured

Scope on the 5 V entering the control box, ground clip on the chassis (logic GND).
Stimulus = full-white shader flashing, sweeping 0.1 → 100 → 0.1 Hz, ~50 k samples.

| Capture | Result |
|---|---|
| DC-coupled, full sweep | V_min **4.715 V**, V_max **5.249 V**; Pk-Pk max 0.356 / avg 0.161 V |
| AC-coupled (DC blocked) | swing −0.219 … +0.214 V (smaller than DC — AC coupling's ~1 Hz HPF filtered the slow 0.1 Hz droops; **trust DC for absolutes**) |
| Row-population test | ~**5 mV/row** drop on average V, ~**14.5 mV/row** on the minimum → full white ≈ 4.7 V avg, **4.1 V min** |

The 4.1 V min hard-browned-out the Pi 5 (it rebooted). Bumping the PSU setpoint +200 mV
just slid the whole window up — the *swing* (load regulation) is unchanged, and over-
trimming pushes the light-load V + release overshoot toward the RP2350's 5.5 V ceiling.

## The key insight: it was ground bounce, not rail sag

**Smoking gun:** moving the SBCs to a genuinely independent 150 W 5 V supply produced
**almost the identical droop**. That's physically impossible for a real rail sag — an
independent supply can't be loaded by the other's current. The only way both
measurements show the same droop is if the droop lives in the **shared GND reference**.

Mechanism — **common-impedance coupling**:
- On a HUB75 panel, logic and LEDs share **one ground** (not isolated). Tens of amps of
  LED return current flow through the ground network.
- Voltage is a *difference*. The scope (−) sat on a GND node carrying that LED return
  current, so it measured `I_LED · R_ground` (ground heaving), not the 5 V rail moving.
- Root cause: the "star" had a **shared GND segment** between LED return and the logic
  reference. LED current's IR drop landed in the logic GND.

LED return current is supposed to flow through the panel **power lugs** (fat), not the
**ribbon GND** (signal reference, mA). If it's bouncing logic, the heavy return is
inadequate/too thin/not landed at the star, so current diverts through ribbon → HAT →
logic GND. Fix = give the amps a fat, dedicated road to the star; the ribbon GND then
stays quiet. You can't *isolate* the node (the panels need the common reference;
isolation would need digital isolators on every line) — you *redirect the current*.

## Wire gauge math (current path)

`V = I · R_loop`, and R_loop counts **both** conductors (current makes a round trip).
CCA ≈ **1.6×** the resistance of same-gauge copper (≈61–64 % IACS), so the current
**14 AWG CCA panel feed behaves like ~16 AWG solid copper**. Gauge (14→22 = 6.4× area)
dominates; material is the supporting actor.

| Feed | Wire | Loop R | Drop |
|---|---|---|---|
| Panel (per 20 A channel) | 14 AWG CCA, 4 ft pair | ~32 mΩ | 20 A → **0.65 V**; 40 A → 1.3 V; 60 A → 1.9 V |
| SBC | 22 AWG Cu, 6 ft pair | ~194 mΩ | 3 A → **0.58 V**; 5 A (Pi 5 peak) → **0.97 V** |

> ⚠️ 14 AWG (CCA worse) is rated ~15 A for power wiring. 20 A/channel through it runs
> **hot** — a real thermal concern, not just lossy. Upsize to heavy copper (10 AWG+) or
> add more injection points. The 22 AWG SBC feed is an *independent* brownout source —
> a Pi 5 at peak drops ~1 V in the wire alone; go 18–16 AWG Cu or shorten.

Re-measure at the PSU terminals vs. the panel end to see how much "sag" is just wire.

## The PSU's 3 channels are NOT independent

The 5 V / 300 W brick exposes **3 × 20 A** output channels: ch1 → 4 panels, ch2 → 4
panels, ch3 → SBCs, all GND-starred at the PSU. But those channels are the **same
internal rail** brought out to three terminal pairs (paralleled, rated 20 A for the
*connector*), **not** three regulators. So:
- They isolate **wiring** (dedicated conductor pairs = good, effectively star) ...
- ... but **not source voltage** — load-regulation sag is common to all three. The SBCs
  on ch3 still ride whatever the internal rail does under the panels' load.
- This is why a *genuinely separate* supply (or HV-distribution, below) is the only way
  to isolate the SBCs from rail regulation, vs. just from IR coupling.

Current topology (3 channels starred at PSU(−), HAT ribbon GND the only other bridge) is
**textbook-correct single-supply grounding**. Remaining lever = fatten the copper.

## Wall v2: two 300 W supplies for 384×128 (24 panels)

The v2 wall (ROADMAP §5) is 6×4 = **24** P4-2121-64x32 tiles, so one 60 A brick
no longer covers it: at the wire-gauge section's ~7.5 A/panel worst case that's
~180 A (~900 W) of all-white headroom. v2 runs **2× 5 V / 300 W / 60 A**
transformers (2nd arrives 2026-07-17) — 600 W / 120 A total, which comfortably
carries audio-reactive content (rarely near full white) but **not** a sustained
all-white 24-panel frame, so brightness capping / content limits (ROADMAP §1)
matter more at this size. Two supplies = two rails; extend the single-supply
star-ground rules above:
- **Bond both PSU (−) terminals at ONE star point** (a single heavy strap) so
  the two halves and the HAT/SBC logic GND share one reference. Don't let panel
  return current find a second path through the logic ground.
- **Split the wall by supply on the horizontal midline** — 12 panels each, top
  half on one rail, bottom half on the other. That is deliberately the *same*
  boundary as the HUB75 chain A / chain B split (chain A = the top two panel
  rows, chain B = the bottom two — see `config.serpentine`), so a chain's data
  and its panels' return current share one supply's reference. A split that cut
  across the chains would put a chain's HUB75 signals and their ground return on
  two different rails, referencing the data to a ground that moves independently
  of it — exactly the bounce failure diagnosed above, reintroduced by wiring.
  Keep each rail's fat +5 V and return copper to its own panels. Do **not**
  cross-feed +5 V between the two rails — parallel supplies fight on load-share.
- The SBC/HAT logic rail rides **one** supply's (−) reference (or a small
  dedicated supply), never floating between the two.

If the wall grows past this, or the runs get long, the HV-distribution idea
below (buck 12/24 V → 5 V at each cluster) is the next step.

## Measuring correctly (Kelvin / differential)

Reference the scope (−) at the *exact node of interest* — panel logic GND at the panel
input when checking logic, SBC GND at the board when checking the SBC rail. A
"convenient" chassis/Ethernet-shell ground that carries return current **lies**. Or go
differential: **Ch A on +5 V, Ch B on local GND, display A − B** — rejects ground motion
entirely. To quantify the bounce directly: **Ch A = HAT GND, Ch B = panel power-lug GND,
A − B** *is* the ground bounce; watch it shrink as the heavy return is beefed up.

## v2 idea: distribute 12/24 V, buck to 5 V at each panel

Distributing at higher voltage is sound EE (PoE / 48 V datacenter logic): for fixed
power, higher V → lower I → **I²R loss falls with current²**, and a 1 V drop is 20 % of
5 V but 4 % of 24 V. Point-of-load conversion shrinks the high-current loop to inches and
the long haul carries ~1/5 the current → ~1/5 the ground bounce. Catches:
- **Size bucks to panel *peak*** (~7.5 A/panel here → a 5 V/5 A buck browns out on white;
  use ~10 A modules, or one beefy buck per 4-panel cluster).
- **12 V vs 24 V:** 24 V = less current/thinner wire but a harsher step-down ratio (lower
  efficiency, more heat); 12 V is the gentler sweet spot for these distances.
- Switching noise needs output filtering; transient response needs local bulk caps; buck
  output GNDs still common through the (now-quieter) HV return.

Verdict: elegant and scalable — earns its keep when the wall **expands**. For the working
8-panel wall, **fat copper + the star/ratiometric rules above are the 80/20**.

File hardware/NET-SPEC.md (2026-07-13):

# RP2350-HUB75-HAT — Net Specification (v1)

> The locked electrical intent for the level-shifting HAT, derived from
> `PROJECT-PLAN.md` §6 (pin map) and §9 (HAT scope), as amended by the
> scale-out decision (see memory `scale-out-and-hat-scope`). This is the input
> to schematic generation — schematic + layout must match it. **Lock before
> editing the schematic.**

## 1. Scope (what the HAT does / does not do)

- **Does:** 3.3 V→5 V level-shift all HUB75 logic via `SN74AHCT245`; present **2**
  HUB75 connectors (chains A & B = one 256×64 tile); break out spare GPIO + power
  for the Phase 5 SPI link and multi-board sync; carry a 5 V rail for the '245s
  with a common ground reference.
- **Does NOT:** power the panels (their 5 V goes direct to panel lugs, never
  through the HAT or the HUB75 ribbon — §9.3); contain any MCU support circuitry
  (the dev board owns crystal/flash/USB/core power).

## 2. Components

| Ref | Part | Symbol / Footprint | Notes |
|-----|---|---|---|
| J1 | Pi 40-pin header | `Connector_Generic:Conn_02x20_Odd_Even` / `PinSocket_2x20_P2.54mm_Vertical` | Female socket, plugs onto the RP2350-PiZero |
| J2 | HUB75 chain A | `Connector_Generic:Conn_02x08_Odd_Even` / `Connector_IDC:IDC-Header_2x08_P2.54mm_Vertical` | Box header to panel-1 IN |
| J3 | HUB75 chain B | same as J2 | Box header to panel-1 IN |
| J4 | SPI/sync breakout | `Connector_Generic:Conn_01x08` / `PinHeader_1x08_P2.54mm_Vertical` | spare GPIO + power |
| J5 | 5 V rail input | `Connector_Generic:Conn_01x02` / screw terminal 5.08 mm | from the panel 5 V supply (GND commoned) |
| U1, U3 | `SN74AHCT245DWR` | `74xx:74HC245` / `Package_SO:SOIC-20W_7.5x12.8mm_P1.27mm` | data + CLK/LAT buffer (chain A=U1, B=U3) |
| U2, U4 | `SN74AHCT245DWR` | same | OE + address buffer (chain A=U2, B=U4) |
| C1–C4 | 100 nF | `Capacitor_SMD:C_0805_2012Metric` | one per '245, at VCC |
| C5 | 100 µF | bulk electrolytic / `CP_*` | 5 V rail bulk near J5 |
| R1, R2 | 22 Ω | `Resistor_SMD:R_0805_2012Metric` | series term on CLK (R1=chain A, R2=chain B) |

> Symbol note: KiCad's `74xx` lib has no AHCT symbol; the `74HC245` symbol is
> pin-identical, so use it with **Value = `SN74AHCT245DWR`**.

## 3. '245 buffer mapping (DIR=VCC → A→B; /OE=GND → always enabled)

Each '245: pin 1 = DIR (→ 5V), pin 19 = /OE (→ GND), pin 20 = VCC (5V), pin 10 =
GND. A-side (pins 2–9) = 3.3 V inputs from the RP2350; B-side (pins 18–11) = 5 V
outputs to the HUB75 connector.

### U1 — chain A data + clk/lat  → J2
| '245 ch | A in (from GP) | B out → J2 pin (signal) |
|---|---|---|
| 1 | GP0  (A.R1) | 1 (R1) |
| 2 | GP1  (A.G1) | 2 (G1) |
| 3 | GP2  (A.B1) | 3 (B1) |
| 4 | GP3  (A.R2) | 5 (R2) |
| 5 | GP4  (A.G2) | 6 (G2) |
| 6 | GP5  (A.B2) | 7 (B2) |
| 7 | GP16 (CLK)  | → **R1 (22 Ω)** → 13 (CLK) |
| 8 | GP17 (LAT)  | 14 (LAT/STB) |

### U2 — chain A oe + address  → J2
| '245 ch | A in | B out → J2 pin |
|---|---|---|
| 1 | GP18 (OE) | 15 (/OE) |
| 2 | GP12 (A)  | 9  (A) |
| 3 | GP13 (B)  | 10 (B) |
| 4 | GP14 (C)  | 11 (C) |
| 5 | GP15 (D)  | 12 (D) |
| 6,7,8 | **GND** (unused inputs tied low) | — (B6–B8 unconnected) |

### U3 — chain B data + clk/lat  → J3   (mirror of U1)
GP6→R1, GP7→G1, GP8→B1, GP9→R2, GP10→G2, GP11→B2, GP16(CLK)→**R2 (22 Ω)**→J3.13,
GP17(LAT)→J3.14.

### U4 — chain B oe + address  → J3   (mirror of U2)
GP18(OE)→J3.15, GP12→J3.9(A), GP13→J3.10(B), GP14→J3.11(C), GP15→J3.12(D); ch6–8
inputs tied to GND.

> Per-connector control fan-out (§9): GP12–18 each drive **two** '245 inputs (one
> in the A group, one in the B group) so each connector gets its own buffered
> CLK/LAT/OE/ADDR copy — light load on the RP2350, clean edges to each panel.

## 4. HUB75 connector pinout (J2, J3) — plain HUB75, 1/16 scan

| pin | net | pin | net |
|---|---|---|---|
| 1 | R1 | 2 | G1 |
| 3 | B1 | 4 | GND |
| 5 | R2 | 6 | G2 |
| 7 | B2 | 8 | GND |
| 9 | A  | 10 | B |
| 11 | C | 12 | D |
| 13 | CLK | 14 | LAT |
| 15 | /OE | 16 | GND |

## 5. Pi header (J1) — ACTUAL RP2350-PiZero positions (see PIZERO-HEADER-PINOUT.md)

> ⚠️ NOT standard Pi BCM. The board transposes GPIO4↔14, GPIO5↔15, GPIO9↔12,
> GPIO10↔11 vs a real Pi (PROJECT-PLAN §6's "standard BCM" assumption was wrong —
> it only checked pin 12 = GPIO18, which happens to coincide). Read off the
> schematic's `40Pin OUT` block.

- **GPIO → net** (the '245 A-side sources): GP0=pin27, GP1=28, GP2=3, GP3=5,
  **GP4=8**, **GP5=10**, GP6=31, GP7=26, GP8=24, **GP9=32**, **GP10=23**,
  **GP11=19**, **GP12=21**, GP13=33, **GP14=7**, **GP15=29**, GP16=36, GP17=11,
  GP18=12. *(bold = transposed vs standard Pi)*
- **Breakout GPIOs** (→ J4): GP19=pin35, GP20=38, GP21=40, GP22=15, GP26=37,
  GP27=13. *(these sit at standard positions)*
- **3V3**: pins 1, 17 → net 3V3 (breakout reference). **GND**: pins
  6,9,14,20,25,30,34,39 → net GND.
- **Pi 5V (pins 2,4): NOT CONNECTED** — the HAT does not draw from or backfeed
  the dev board's 5 V. The '245 rail is the panel-supply 5 V via J5.

## 6. Link breakout (J4, 1×8)

| pin | net | intended Phase-5 use (design intent) | as deployed (Phase-6 parallel link) |
|---|---|---|---|
| 1 | GP19 | SPI (e.g. SCK via PIO) | DATA0 ← Pi GPIO12 |
| 2 | GP20 | SPI (MOSI ← Pi 5) | DATA1 ← Pi GPIO13 |
| 3 | GP21 | SPI (CS) | DATA2 ← Pi GPIO14 |
| 4 | GP22 | SPI (MISO / spare) | DATA3 ← Pi GPIO15 |
| 5 | GP26 | frame-commit sync (shared across boards) | DCLK ← Pi GPIO20 |
| 6 | GP27 | spare | READY → Pi GPIO25 |
| 7 | 3V3 | logic reference | (unchanged) |
| 8 | GND | return | (unchanged) |

> The nets are as fabbed; the roles column on the right is what actually runs on
> them — the Phase-6 **4-lane parallel bus** (see
> `../rayglow/render/piobridge/README.md` and `../firmware/src/bin/phase6_parallel.rs`).
> CS (reserve) is GP25 via a jumper to the J1 header, not J4. The HAT just passes
> the GPIO + power through, so no board change was needed.

## 7. Power & grounding (§9.3)

- **5V rail**: J5 pin1 → U1–U4 VCC (pin 20) + each '245 DIR (pin 1) + C1–C4 +
  C5 bulk.
- **GND (single common net)**: J5 pin2 ↔ J1 GND pins ↔ U1–U4 GND (pin 10) +
  /OE (pin 19) + C1–C5 + HUB75 GND pins (4/8/16 on J2,J3) + J4 GND + U2/U4 unused
  inputs. This common ground ties panel-supply GND, dev-board GND, and the '245
  rail GND together (required for the level shift to reference correctly).
- **Panel 5 V** is **off-board** (panel lugs) — not represented here.

## 8. ERC notes

- `PWR_FLAG` on **5V** (driven by J5, a passive connector), **GND**, and **3V3**
  (J1 passive pin) so ERC doesn't flag undriven power inputs.
- Tie U2/U4 unused A-inputs to GND (no floating CMOS inputs).
- Net-name list (for parity check against this spec): `GND`, `+5V`, `+3V3`,
  `GP0..GP18` (data/ctrl), `GP19..GP22,GP26,GP27` (breakout),
  `J2_R1..`, HUB75 nets, and `CLK_A_T`/`CLK_B_T` (post-series-R CLK to J2/J3).

## 9. Deliberately deferred to v2 / layout

- **Series termination on data lines** (only CLK is terminated in v1): the 3.3 V
  unbuffered SI was already clean over 4 chained panels (§11.7 retired), so data
  termination is unnecessary insurance for v1. Easy to add a resistor field later
  if a buffered-edge ringing shows up.
- Board outline / mounting holes / connector orientation → decided at layout
  (human-in-the-loop, GUI).

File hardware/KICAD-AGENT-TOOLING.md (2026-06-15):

# KiCad Agent Tooling & Capacity

> Brief for the orchestrator agent on **what KiCad automation exists on this machine, what an agent can and cannot do with it, and how to divide the custom-HAT PCB work (PROJECT-PLAN §9) between agent and human.** The author wants to do **as much of the KiCad design with agent help as is realistically sound** — but values transparent, understood design over autopilot. Set expectations from the capability matrix below; do not promise autonomous "design me a PCB."

---

## 0. TL;DR for the orchestrator

- **Schematic capture is highly agent-amenable** for this board — it's four identical `SN74AHCT245` buffer blocks + connectors + power, i.e. textbook parametric repetition. Generate it as **circuit-as-code** (SKiDL) or by emitting/patching the `.kicad_sch` (kicad-sch-api), then verify with headless **ERC**.
- **PCB layout/routing is human-in-the-loop.** Agents can *place* footprints, run **DRC** in a loop, and **render the board to PNG** for visual review — but producing a *good* 2-layer routed HAT (controlled CLK length-matching, the scattered-BCM-header fan-out from §6) is a guided GUI job, not autonomous. Treat the agent as a co-pilot that scripts placement, checks rules, and renders for review.
- **Two of the agent's tools need the KiCad GUI open** (live IPC); the rest are **headless** (`kicad-cli`, file parsing) and run with no GUI.
- Everything here is **installed and proven** as of 2026-06-10 (KiCad 10.0.3).

---

## 1. Environment (verified present)

| Component | Version / location | Notes |
|---|---|---|
| KiCad | **10.0.3** | `/usr/bin/kicad`, GUI app |
| `kicad-cli` | **10.0.3** | `/usr/bin/kicad-cli`, headless — no GUI needed |
| Stock libraries | `kicad-library` + `kicad-library-3d` | **222 symbol libs, 155 footprint sets, 105 3D-model packs** at `/usr/share/kicad/{symbols,footprints,3dmodels}` |
| Host OS | CachyOS (Arch) on desktop | `pacman`; **fish** shell (no `<<` heredocs); **uv** for all Python |
| Python | via `uv` only | No pip/venv/conda — author preference, enforce it |

**Library gotcha (already resolved, noted for reproducibility):** on Arch the `kicad` package ships *only* the editors; the libraries are separate packages. They're installed now and the global library tables are populated. A fresh checkout on another machine needs `sudo pacman -S kicad-library kicad-library-3d`.

---

## 2. The `kicad-mcp` server (the agent's live interface)

A proof-of-concept **MCP server** wrapping KiCad for agent control. Read-only by design (POC).

- **Location:** `~/Projects/kicad-mcp/` (uv project; `server.py`, `connect_test.py`, `README.md`).
- **Stack:** `kicad-python` (`kipy`) 0.7.1 for the live IPC half; `kicad-cli` subprocess for the headless half; `mcp` 1.27 (FastMCP, stdio transport).
- **Registered in Claude Code** (local config, scoped to the kicad-mcp project dir). To make the `kicad` tools available from *any* directory, re-add with user scope:
  `claude mcp add kicad -s user -- uv --directory ~/Projects/kicad-mcp run python server.py`

### Tools exposed
| Tool | Half | Needs GUI? | Returns |
|---|---|---|---|
| `kicad_status` | live (kipy) | **yes** | connection up?, KiCad version, board open? |
| `list_footprints` | live | **yes** | per-footprint ref, value, X/Y mm, layer |
| `list_nets` | live | **yes** | net code + name |
| `board_summary` | live | **yes** | counts: footprints/pads/nets/tracks/vias/zones/layers |
| `run_drc` | headless (cli) | no | DRC violations on a `.kicad_pcb` (JSON-parsed) |
| `export_gerbers` | headless (cli) | no | plots Gerbers to a dir |

**Live tools require:** KiCad GUI running + **Preferences → Plugins → Enable IPC API server** + a board open in the PCB editor. The IPC API in KiCad 9/10 is **PCB-first and GUI-only**; headless IPC arrives in KiCad 11.

**Build-out path** (when ready to go beyond read-only): `kipy` write-commits — `board.begin_commit()` / `board.create_items()` / `board.push_commit()` — let an agent place and move footprints, draw the board outline, etc. The schematic side has *no* mature IPC; use the file/code surfaces in §3 instead.

---

## 3. The three automation surfaces (pick per task)

**A. Live IPC (`kipy`)** — talk to a running GUI. Good for *inspecting* the board an operator has open, and (with write-commits) scripted placement. PCB only. GUI must be up.

**B. Headless `kicad-cli`** — the robust, version-stable workhorse. No GUI. Full surface verified on this machine:
- `sch erc` — Electrical Rules Check (JSON or report).
- `sch export {netlist, bom, python-bom, pdf, svg}` — **`netlist` lets an agent verify connectivity programmatically**; `pdf`/`svg` for visual diff.
- `pcb drc` — Design Rules Check (JSON/report; supports `--schematic-parity`).
- `pcb export {gerbers, drill, pos, step, glb, svg, pdf, ipc2581, ipcd356, ...}` — full fab output.
- **`pcb render`** — board → **PNG/JPEG**. A vision-capable agent can render its own layout and critique placement/routing visually, headless.

**C. File-level / circuit-as-code** — `.kicad_sch` and `.kicad_pcb` are S-expression text.
- **SKiDL** (`uv add skidl`) — describe the circuit in Python, emit a netlist. **Best fit for this board's 4× repetition** — a loop, not four hand-placed copies.
- **kicad-sch-api** / **kiutils** — parse/generate/patch schematic files directly. Use when you need to produce or edit an actual `.kicad_sch`.
- Trade-off: you own correctness; there's no live connectivity engine — so **always gate file-level output through `kicad-cli sch erc`**.

---

## 4. Capability matrix — what the agent CAN / CANNOT do

**CAN (high confidence):**
- Generate the schematic from a pin/net spec (SKiDL or kicad-sch-api) — especially the regular '245 + connector + power structure.
- Run **ERC/DRC** headless and iterate until clean (great inner loop).
- Extract/diff the **netlist** to prove the board matches the intended §6 pin map.
- Export **Gerbers/drill/pos/STEP/BOM** for fab once the layout exists.
- **Render the board/schematic to image** for visual review by a vision model.
- Inspect a live board the operator has open (footprint positions, nets, counts).
- Script **footprint placement** via `kipy` write-commits (rough placement, arrays).

**CANNOT (today) / needs a human:**
- **Quality interactive routing** — especially the §6 reality that BCM numbering makes the 19 signals electrically contiguous but **physically scattered** across the header, plus §9 CLK length-matching and series-termination placement. This is a guided-GUI job.
- **Autonomous "good" 2-layer layout.** Agent placement + DRC ≠ a clean board. Human judgment on stack-up, copper pours, panel-power copper width (the 5 V rail feeds only the '245s here, but grounds are commoned — §9.3).
- **Drive the GUI** (menus, interactive tools). No GUI automation surface; live API is data-level only.
- **Schematic via IPC** — not supported; must go through file/code (§3C).
- Anything while a file is **open in the GUI** — external edits get clobbered on save (see §6).

---

## 5. Recommended division of labor for THIS HAT (PROJECT-PLAN §9)

The HAT is logically simple, physically fiddly. Suggested flow:

1. **Lock the net spec first.** The §6 GPIO map + §9 rules (per-connector buffered CLK/LAT/OE/ADDR fan-out, DIR tied, OE→GND, 100 nF per '245, ~22–33 Ω series on CLK/data, 4× HUB75 2×8 IDC, **panel 5 V NOT on the ribbon**, grounds commoned). This spec is the agent's input — without it, schematic gen is blocked (same blocker that left the `bit-hat-bang` exploratory sketch unwired).
2. **Agent: generate schematic** (SKiDL/kicad-sch-api) from that spec → `kicad-cli sch erc` until clean → `sch export pdf` for the author to eyeball. Remember **PWR_FLAG** on the 5 V and GND nets or ERC will complain about undriven power inputs.
3. **Human + agent: footprint assignment** — agent proposes (it knows the §1 footprints: `SOIC-20W` for the DWR '245s, `Connector_IDC:IDC-Header_2x08` keyed box headers for HUB75, `PinSocket_2x20` for the Pi header), human confirms.
4. **Human-led layout** in the GUI; agent assists by scripting initial placement (`kipy` commits), running `pcb drc` in a loop, and `pcb render` for visual review between passes.
5. **Agent: fab outputs** — Gerbers/drill/pos/BOM/STEP once DRC is clean.

**Realistic expectation to set with the author:** steps 1–3, 5 are largely agent-driven; step 4 is collaborative with the human holding the routing pen. That still offloads the majority of the tedium.

---

## 6. Hard constraints & gotchas (read before touching files)

- **GUI lock files.** A project open in KiCad writes `~*.lck` / `.kicad_prl`. **Never edit a `.kicad_sch`/`.kicad_pcb` on disk while it's open** — the GUI overwrites on save. Either close the GUI for file-level work, or use live IPC (which is GUI-safe).
- **Footprint cache vs library.** Boards embed a *copy* of each footprint (self-containment). `lib_footprint_mismatch` DRC warnings just mean the cached copy drifted from the library master → `Tools → Update Footprints from Library`. Benign.
- **PWR_FLAG.** KiCad ERC wants every power-*input* pin driven by a power-*output*; real sources (headers, jacks) aren't typed that way. Drop a `power:PWR_FLAG` on the 5 V and GND nets to assert "power enters here."
- **Format-version coupling.** `kicad-cli` and the file format are tied to the installed KiCad (10.0.3). Hand-written `.kicad_pcb`/`.kicad_sch` must match the format version or the CLI rejects them — prefer library-emitting tools (SKiDL/kicad-sch-api) over raw S-expr authoring.
- **`kipy` is young/fast-moving.** Pinned at 0.7.1. If it's bumped, re-introspect the API (footprint ref is `fp.reference_field.text.value`; `position` is a `Vector2` in **nm**, ÷1e6 → mm; `Net.name`/`.code`).

---

## 7. Pointers

- MCP server + verified API notes: `~/Projects/kicad-mcp/` (`README.md`, `server.py`).
- Exploratory scratch schematic (4× 74HCT245, 40-pin J1, 4× 16-pin J2–J5, **unwired** — fine to discard or reuse as a symbol-placement starting point): `~/Projects/bit-hat-bang/bit-hat-bang/`.
- Prior-art KiCad MCP servers worth reading before building out write-ops:
  `Seeed-Studio/kicad-mcp-server` (pin-level tracing), `circuit-synth/mcp-kicad-sch-api` (schematic gen), `oaslananka/kicad-mcp-pro` (validation gates/DFM/export), `lamaalrajih/kicad-mcp` (broad reference).
- This board's electrical intent: **PROJECT-PLAN.md §6 (pin map) and §9 (HAT scope)** — the schematic-gen agent's source of truth.

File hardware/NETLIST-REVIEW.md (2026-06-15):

# HAT netlist — review (generated from rp2350-hub75-hat.net)

56 nets, 0 ERC errors. J1 uses ACTUAL RP2350-PiZero pin positions
(see PIZERO-HEADER-PINOUT.md — NOT standard Pi BCM).

## Power

- **+5V** — `C1.1`, `C2.1`, `C3.1`, `C4.1`, `C5.1`, `J5.1`, `U1.1`, `U1.20`, `U2.1`, `U2.20`, `U3.1`, `U3.20`, `U4.1`, `U4.20`
- **+3V3** — `J1.1`, `J1.17`, `J4.7`
- **GND** — `C1.2`, `C2.2`, `C3.2`, `C4.2`, `C5.2`, `J1.14`, `J1.20`, `J1.25`, `J1.30`, `J1.34`, `J1.39`, `J1.6`, `J1.9`, `J2.16`, `J2.4`, `J2.8`, `J3.16`, `J3.4`, `J3.8`, `J4.8`, `J5.2`, `U1.10`, `U1.19`, `U2.10`, `U2.19`, `U2.7`, `U2.8`, `U2.9`, `U3.10`, `U3.19`, `U4.10`, `U4.19`, `U4.7`, `U4.8`, `U4.9`

## Chain A RGB in (GP0-5)

- **GP0** — `J1.27`, `U1.2`
- **GP1** — `J1.28`, `U1.3`
- **GP2** — `J1.3`, `U1.4`
- **GP3** — `J1.5`, `U1.5`
- **GP4** — `J1.8`, `U1.6`
- **GP5** — `J1.10`, `U1.7`

## Chain B RGB in (GP6-11)

- **GP6** — `J1.31`, `U3.2`
- **GP7** — `J1.26`, `U3.3`
- **GP8** — `J1.24`, `U3.4`
- **GP9** — `J1.32`, `U3.5`
- **GP10** — `J1.23`, `U3.6`
- **GP11** — `J1.19`, `U3.7`

## Shared control in (GP12-18 -> both chains' buffers)

- **GP12** — `J1.21`, `U2.3`, `U4.3`
- **GP13** — `J1.33`, `U2.4`, `U4.4`
- **GP14** — `J1.7`, `U2.5`, `U4.5`
- **GP15** — `J1.29`, `U2.6`, `U4.6`
- **GP16** — `J1.36`, `U1.8`, `U3.8`
- **GP17** — `J1.11`, `U1.9`, `U3.9`
- **GP18** — `J1.12`, `U2.2`, `U4.2`

## Breakout (-> J4)

- **GP19** — `J1.35`, `J4.1`
- **GP20** — `J1.38`, `J4.2`
- **GP21** — `J1.40`, `J4.3`
- **GP22** — `J1.15`, `J4.4`
- **GP26** — `J1.37`, `J4.5`
- **GP27** — `J1.13`, `J4.6`

## Buffered outputs -> HUB75 pins + CLK series-R (28)

- **N$1** — `J2.1`, `U1.18`
- **N$10** — `J2.15`, `U2.18`
- **N$11** — `J2.9`, `U2.17`
- **N$12** — `J2.10`, `U2.16`
- **N$13** — `J2.11`, `U2.15`
- **N$14** — `J2.12`, `U2.14`
- **N$15** — `J3.1`, `U3.18`
- **N$16** — `J3.2`, `U3.17`
- **N$17** — `J3.3`, `U3.16`
- **N$18** — `J3.5`, `U3.15`
- **N$19** — `J3.6`, `U3.14`
- **N$2** — `J2.2`, `U1.17`
- **N$20** — `J3.7`, `U3.13`
- **N$21** — `R2.1`, `U3.12`
- **N$22** — `J3.13`, `R2.2`
- **N$23** — `J3.14`, `U3.11`
- **N$24** — `J3.15`, `U4.18`
- **N$25** — `J3.9`, `U4.17`
- **N$26** — `J3.10`, `U4.16`
- **N$27** — `J3.11`, `U4.15`
- **N$28** — `J3.12`, `U4.14`
- **N$3** — `J2.3`, `U1.16`
- **N$4** — `J2.5`, `U1.15`
- **N$5** — `J2.6`, `U1.14`
- **N$6** — `J2.7`, `U1.13`
- **N$7** — `R1.1`, `U1.12`
- **N$8** — `J2.13`, `R1.2`
- **N$9** — `J2.14`, `U1.11`

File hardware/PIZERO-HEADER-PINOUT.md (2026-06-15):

# RP2350-PiZero — 40-pin header (J5) actual pinout

> Read directly off the board schematic's `40Pin OUT` block (`RP2350-PiZero.pdf`),
> confirmed 2026-06-12. **The labels below are the *actual RP2350 GPIO* net at
> each physical pin** — i.e. what the firmware's `pins.gpioN` reaches, and what
> the board silkscreen shows. Compare against the silkscreen to verify.
>
> ⚠️ These are **NOT** standard Raspberry Pi BCM positions. The schematic's
> separate "BCM" column is only the Pi-compat reference number for each physical
> slot; Waveshare wired different RP2350 GPIOs there. PROJECT-PLAN §6's "standard
> Pi BCM numbering" assumption is WRONG for several pins (see swap list below).

Physical layout (pin 1 = the corner nearest the SD/USB end, per the board):

| Left signal | Pin | Pin | Right signal |
|---|:--:|:--:|---|
| **3V3** | 1 | 2 | **5V** (VBUS) |
| GPIO2 (SDA) | 3 | 4 | **5V** (VBUS) |
| GPIO3 (SCL) | 5 | 6 | **GND** |
| **GPIO14** | 7 | 8 | **GPIO4** (TX) |
| **GND** | 9 | 10 | **GPIO5** (RX) |
| GPIO17 | 11 | 12 | GPIO18 |
| GPIO27 | 13 | 14 | **GND** |
| GPIO22 | 15 | 16 | GPIO23 |
| **3V3** | 17 | 18 | GPIO24 |
| **GPIO11** (SPI MOSI) | 19 | 20 | **GND** |
| **GPIO12** (SPI MISO) | 21 | 22 | GPIO25 |
| **GPIO10** (SPI SCLK) | 23 | 24 | GPIO8 (CE0) |
| **GND** | 25 | 26 | GPIO7 (CE1) |
| GPIO0 (ID_SDA) | 27 | 28 | GPIO1 (ID_SCL) |
| **GPIO15** | 29 | 30 | **GND** |
| GPIO6 | 31 | 32 | **GPIO9** |
| GPIO13 | 33 | 34 | **GND** |
| GPIO19 | 35 | 36 | GPIO16 |
| GPIO26 | 37 | 38 | GPIO20 |
| **GND** | 39 | 40 | GPIO21 |

## Swaps vs. a standard Raspberry Pi (the gotcha)

Four GPIO **pairs** are transposed relative to a real Pi's BCM positions — every
one of them a pin the HAT uses:

| Pair | This board | Standard Pi |
|---|---|---|
| GPIO4 ↔ GPIO14 | GPIO4=pin8, GPIO14=pin7 | GPIO4=pin7, GPIO14=pin8 |
| GPIO5 ↔ GPIO15 | GPIO5=pin10, GPIO15=pin29 | GPIO5=pin29, GPIO15=pin10 |
| GPIO9 ↔ GPIO12 | GPIO9=pin32, GPIO12=pin21 | GPIO9=pin21, GPIO12=pin32 |
| GPIO10 ↔ GPIO11 | GPIO10=pin23, GPIO11=pin19 | GPIO10=pin19, GPIO11=pin23 |

GND and 3V3 positions, and GPIO16–27, are at standard positions. Pin 12 = GPIO18
happens to match standard (which is what mislead §6 into assuming the whole map
was standard — it verified the one pin that coincides).

## Consequences

- **Firmware: unaffected.** It addresses RP2350 GPIO *numbers* (`pins.gpio4`,
  etc.); the silicon GPIO4 is GPIO4 wherever it lands on the header. Your manual
  panel wiring worked because you used the silkscreen (= actual GPIO labels).
- **HAT PCB: affected.** The J1 (Pi-socket) → '245 routing must connect each
  physical pin to its *actual* GPIO net. The first netlist used standard-Pi
  positions and was wrong for the 8 swapped pins — corrected from this table.

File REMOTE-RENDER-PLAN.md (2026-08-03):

# REMOTE-RENDER-PLAN

> **Status: PRODUCTION — deployed and accepted on the wall 2026-08-03.** Written
> 2026-08-02 as a handoff; implemented the same day (Phase 0 EGL device platform +
> the Phase 2 frame link, locked by `tools/link_check.py`); deployed and accepted
> the next — see the ✔ block in §11.4 for the numbers. Per-machine launch defaults
> live in `~/.config/rayglow/config.toml` (`rayglow.example.toml`), so production
> is `python -m rayglow.render <shader>` on the render host and
> `python -m rayglow.framesink` on the Pi. The gateware got zero changes (§3);
> INTERFACE-CONTRACT is v0.3 (host-agnostic, ratified after the fact).
>
> **Updated 2026-08-02 (same day, later):** the 120 Hz DPI upgrade this plan warned
> against in §5.3 shipped independently and is confirmed clean on the wall (contract
> v0.2, skip-gated double buffer, 122.14 Hz production). §5.3 is rewritten from "don't"
> to "target it, pinned to SW5=6"; all rates, the latency budget, and the credit numbers
> are updated to the 122 Hz baseline. Also corrected: the Pi sink is `drm_out` (dumb
> buffers + page flip), not `/dev/fb0` — fbdev emulation was retired 2026-07-29.

Move GLSL rendering off the Pi 5 and onto `ubuntu-server`'s RTX 4080, keeping the Pi as a
vblank-paced DPI framebuffer and leaving the ECP5 translation layer completely untouched.

## 1. Why

The Pi 5's VideoCore VII is **51.2 GFLOPS FP32**. At 384×128 with `scale=2` (768×256 =
196,608 px) at 60 Hz that is ~4,340 FLOP/px of theoretical peak, and realistically
~1,300 FLOP/px sustained — and the 2026-08-02 move to a 122.14 Hz source *halves* those
budgets again (~650 FLOP/px sustained). A moderate Shadertoy raymarcher — 64–128 march
steps, 4–6 extra SDF evals for normals, a soft-shadow march — costs **5,000–50,000
FLOP/px**. The wall is short by roughly 8–80× on exactly the shaders worth showing.

The RTX 4080 is **~48 TFLOPS FP32, ~950×** the Pi. Frigate uses ~20%, leaving ~38 TFLOPS
against a workload needing ~0.02. The GPU is not the constraint after this change; nothing
is.

**The counter-intuitive result (§5): this architecture is *lower* latency than today**,
because the render stage currently dominates the budget and collapses from 25–50 ms to
~1 ms, while the added network hop costs ~1.7 ms.

## 2. Target architecture

```
will-desktop (192.168.1.105, VLAN 10)          ubuntu-server (192.168.1.101, VLAN 10)
┌────────────────────────────────┐             ┌──────────────────────────────────────┐
│ music ▶ PipeWire sink monitor  │   UDP:5005  │ feed.receiver (latest-win)           │
│ sender.py: FFT ▶ bands         │ ──────────▶ │ render: GLSL ▶ EGL device platform   │
│ + flywheels/beat/key @ ~60 Hz  │  ~180 KB/s  │ RTX 4080, headless, no X             │
└────────────────────────────────┘             └──────────────────┬───────────────────┘
                                                                  │ UDP, 147 KB/frame
                                                                  │ ~17 jumbo datagrams
                                          credit token (1 dgram)  │ ≈144 Mbit/s @ 122 Hz
                                          ◀───────────────────────┤
                                                                  ▼
                                               rpi5 (moving to VLAN 10 — see §7)
                                               ┌──────────────────────────────────────┐
                                               │ framesink: reassemble ▶ page-flip    │
                                               │ ▶ drm_out dumb bufs (NO GL, NO EGL)  │
                                               └──────────────────┬───────────────────┘
                                                                  │ DPI, 25 MHz, 122.14 Hz
                                                                  ▼
                                               ECP5-EVN — UNCHANGED (INTERFACE-CONTRACT v0.2)
                                               ▶ 4 chains ▶ 384×128 @ 171.2 Hz refresh (SW5=6)
```

Roles: **desktop = audio**, **ubuntu-server = pixels**, **Pi = timing**, **FPGA = panels**.

## 3. What changes, and what emphatically does not

| Component | Change |
|---|---|
| `rayglow-fpga` gateware | **None.** Not one line. |
| DPI signalling / modeline | **None.** As-built v0.2: 25 MHz, 122.14 Hz, same 384×480 clamp, same crop. |
| INTERFACE-CONTRACT.md | Doc-only clarification (§4) — the contract is host-agnostic. |
| `sender/sender.py` | **None.** One env var: `RAYGLOW_HOST` → `192.168.1.101`. |
| `rayglow/render/egl.py` | **Add** an NVIDIA device-platform path alongside the Mesa one. |
| `rayglow/render/` output | **Add** a network frame sink. `--output kms` stays as fallback. |
| Pi software | **New**, small: a receiver + `KmsOut`. Drops the GL stack entirely. |

That the gateware is untouched is not a happy accident — it is the interface boundary
doing its job. The FPGA was specified as *a monitor*, and a monitor does not care which
machine is driving it. This is the strongest available evidence the boundary was drawn in
the right place.

**The Pi gets simpler, not more complex.** It no longer needs Mesa, EGL, GLES, or the
shader pipeline — just a socket and a memcpy. `drm_out` already takes a plain
`(H, W, 3) uint8` array and owns everything hard (dumb-buffer allocation, hardware
page flip, event pacing, XRGB8888 swizzle, stride, clipping), so the receiver is ~150
lines against an already-proven sink. (Not `/dev/fb0`/`KmsOut` — fbdev emulation was
retired 2026-07-29 for tearing through cached shadow copies.)

## 4. Git strategy

**No forks. One feature branch, in `rayglow` only.**

A fork solves a *permissions* problem — you don't have one, you own both repos. What a
fork would buy you is a second remote to keep in sync forever, in exchange for nothing.
Forking *both* repos would be worse still: it doubles the sync burden and manufactures a
cross-repo version-matching problem, which is precisely what INTERFACE-CONTRACT.md exists
to prevent. And since `rayglow-fpga` receives zero code changes, a fork of it would be
pure liability.

The change is **additive and flag-guarded**, which is the pattern this project already
prescribes and has already executed once: `--output kms` was added alongside `--output
wall` without disturbing the RP2350 path, and `--transport spi` survives as the proven
fallback. Do the same thing again.

```
rayglow:      feat/remote-render     # all work happens here
rayglow-fpga: (no branch)            # doc-only, direct small commit when proven
```

**Branch plan**
- Small commits at checkpoints; each phase in §6 is a natural commit boundary.
- Merge to `main` only once the wall runs on it *and* `--output kms` still works —
  the local-render path is the fallback and must not rot.
- `rayglow-fpga`: when proven, one commit — a ROADMAP status line plus an
  INTERFACE-CONTRACT bump to **v0.3** (v0.2 was taken 2026-08-02 by the 120 Hz
  ratification) stating explicitly that the contract specifies DPI signals and timing
  and says nothing about which machine generates them. Small, correct, and it
  formalizes why no gateware work was needed.

**Deployment.** The repo already handles multi-machine roles (`sender/` is its own uv
project; `rayglow/` installs editable on the Pi). A third role is a *deployment* concern,
not a repo-structure one. Add a third mutagen session:

| Session | Alpha (desktop) | Beta |
|---|---|---|
| `rayglow-code` | `~/Projects/rayglow` | `rpi5:/home/will/rayglow` *(existing)* |
| `rayglow-shaders` | `~/Projects/rayglow-shaders` | `rpi5:/home/will/presets` *(existing)* |
| **`rayglow-render`** | `~/Projects/rayglow` | `ubuntu-server:/home/will/rayglow` *(new)* |
| **`rayglow-shaders-render`** | `~/Projects/rayglow-shaders` | `ubuntu-server:/home/will/presets` *(new)* |

The desktop stays the single source of truth — "edits here ARE the deploy" still holds,
now fanning out to two targets. Hot-reload keeps working; the watcher just runs on
ubuntu-server.

## 5. Latency analysis

The concern is legitimate and worth the arithmetic. The conclusion is that **the new
network hop is ~3% of the budget, and the change is a net latency *win*.**

### 5.1 Budget, 122.14 Hz DPI / SW5=6 (recommended config — see §5.3)

**Audio front-end — unchanged by this project, and it dominates:**

| Stage | Latency | Note |
|---|---|---|
| PipeWire capture | ~5–11 ms | `blocksize=256, latency="low"` = 5.3 ms/quantum |
| FFT window group delay | **6 / 21 / 43 ms** | Hann centroid = window/2 (see 5.2) |
| Sender frame quantization (~60 Hz) | 0–17 ms, avg 8 | |
| **Subtotal** | **~19–36 ms typical** | up to ~60 ms if driven by `spec[]` |

**Transport + render — what this project changes:**

| Stage | Latency | Note |
|---|---|---|
| Feature UDP, desktop→ubuntu-server | ~0.2 ms | ~3 KB, one datagram, same VLAN, switched |
| **Render (RTX 4080)** | **~0.5–2 ms** | well inside the 8.19 ms/frame cadence budget |
| Frame serialize + UDP TX, 147 KB @ 1 GbE | ~1.4 ms | 1.18 ms wire + switch + stack |
| Pi reassemble | ~0.3 ms | ~17 jumbo datagrams |
| **Subtotal (this is the "new" cost)** | **~2.4–4 ms** | |

**Display pipeline — halved by the 120 Hz upgrade:**

| Stage | Latency | Note |
|---|---|---|
| Pi flip wait | 0–8.2, avg 4.1 ms | pacing; unavoidable at 122.14 Hz |
| Blit into dumb buffer | ~0.15 ms | 196 KB memcpy |
| DPI frame + FPGA capture/adopt | ~8.2 ms | one source frame (capture done 2.1 ms in) |
| HUB75 BCM refresh @ 171.2 Hz | 0–5.8, avg 2.9 ms | SW5=6 |
| **Subtotal** | **~15 ms avg** | was ~29 ms at 60 Hz DPI |

**Total ≈ 37–55 ms typical.**

### 5.2 The dominant term is the FFT, and you can choose it per shader

A Hann-windowed FFT's group delay is the window centroid — half the window:

| Window | Duration | Group delay | Feeds |
|---|---|---|---|
| 576 (→1024-pt) | 12.0 ms | **6.0 ms** | `bass`/`mid`/`treb`, bands **b4–b7** |
| 2048 | 42.7 ms | **21.3 ms** | `sub`, `sub_att` |
| 4096 | 85.3 ms | **42.7 ms** | `spec[128]`, `chroma[12]`, bands **b0–b3** |

This is time-frequency uncertainty, not an engineering defect: you cannot resolve 11.7 Hz
bins without observing 85 ms of signal. But it is *selectable*, and that is free latency:

> **Shader-authoring guideline: drive fast motion from b4–b7 / `bass`/`mid`/`treb`
> (6 ms), and reserve `spec[]`, `chroma[]`, and b0–b3 (43 ms) for slow or ambient
> parameters — color washes, background drift.** A shader whose transients ride the
> 576-window bands is ~37 ms tighter than one riding `spec[]`, for zero cost.

One 122 Hz note: the sender still emits features at ~60 Hz while frames render at
122.14 fps — the flywheels/interpolation already smooth this, so it is *not* a blocker.
An optional later bump of the sender loop to ~120 Hz (same schema, just rate — Will has
okayed schema changes if ever needed) tightens transient quantization by up to ~8 ms.

### 5.3 ✔ RESOLVED 2026-08-02: 120 Hz shipped first and holds — target it, pinned to SW5=6

This section originally argued against bundling the 120 Hz upgrade (cadence-ratio
regression, a belief that ≥240 Hz refresh was prerequisite, RP1 clock-instability
reports near 25 MHz). **The upgrade shipped the same day as an independent experiment
and is confirmed clean end to end on the wall** (contract v0.2, `exp/120hz-dpi` merged).
For the record, why the original analysis was wrong:

- The 1-vs-2-dwell unevenness is real arithmetic but perceptually subordinate: doubling
  the source rate **halves the per-frame motion displacement**, which shrinks the
  straddle/interleave artifact — the very artifact the cadence fear was about — by the
  same factor. Measured by eye on the wall: markedly better motion, no judder. The ≥2×
  cadence rule of thumb did not survive contact with a 122 Hz source.
- The failure mode this section *didn't* know about — the double-buffer handoff budget
  (`scan_frame < DPI_period − capture_time`, violated at 122 Hz) — was fixed
  structurally, not raced: the writer now **skips** a source frame rather than write
  into a buffer the reader still displays (skip-gated CDC, gateware v0.2). Tearing is
  impossible at any timing ratio; an overloaded scan degrades to dropped frames,
  visible on EVN LED **D8**.
- The RP1 25–27 MHz instability did not bite on the wall's kernel: production runs
  `clock-frequency=25000000` with the capture-integrity latches (D10/D11) dark.

**Config to pin for remote render:**

| Setting | Value | Why |
|---|---|---|
| DPI mode | 25 MHz / 122.14 Hz (as-built) | production since 2026-08-02; nothing to change |
| SW5 | **6** (positions 2+3 ON) → 171.2 Hz scan | above the 165.1 Hz zero-drop threshold: **every rendered frame displays**; 91 % brightness (accepted trade) |
| Render pace | credit-paced ⇒ 122.14 fps | the Pi's flip event is the master clock; no separate cap needed |

At SW5=8 (full brightness, 140.4 Hz) the FPGA skip-gate drops ~15 % of source frames —
visually harmless, but with remote render it wastes 15 % of GPU + network work on frames
nobody sees and reintroduces cadence unevenness. No reason to pay that. If full
brightness ever becomes mandatory, the zero-drop route is a ~100 Hz modeline
(`clock-frequency=20500000`) at SW5=8 — not SW5=8 at 122 Hz. Preference order:
**u=6 @ 122.14 > u=8 @ 100 > u=8 @ 122**. Full table: `hardware/SWITCHES-AND-LEDS.md`.

### 5.4 Comparison with today

| | Today (heavy shader, 122 Hz DPI, Pi render) | Proposed |
|---|---|---|
| Audio front-end | 19–36 ms | 19–36 ms |
| Render | **25–50 ms** (heavy shaders can't hold 122 fps at all) | **0.5–2 ms** |
| Network (frames) | — | 1.7 ms |
| Display pipeline | 15 ms | 15 ms |
| **Total** | **~59–101 ms** | **~37–55 ms** |

**Net: 20–45 ms faster** — and, more importantly, heavy shaders become *possible* at
the full 122 fps cadence, which the Pi cannot do at any latency. Even for a trivial
shader that already hits the cap on the Pi, the new path is no worse — the extra
1.7 ms of wire disappears into the flip wait that was already being spent.

### 5.5 ⚠ The real risk is queueing, not transit

Transit time is fine. **Unbounded buffering is the trap that will actually bite.** A naive
`while True: render(); send(frame)` on a 4080 will produce 500+ fps into a link consuming
60, socket buffers fill, and end-to-end latency grows without bound — classic bufferbloat.
It will look like "the visuals drift further behind the music the longer it runs."

**Mitigation — credit-based flow control, mirroring the RP2350 READY handshake already
built for the PIO link:**

- The Pi's blit loop is already paced by `drm_out`'s page-flip completion event. After
  each flip it emits a one-datagram credit.
- The render host holds N credits and blocks when out.
- **The Pi's flip event becomes the master clock for the entire pipeline.** At most N
  frames in flight; latency bounded at N × 8.2 ms.
- Start at **N=2** (one frame of slack absorbs network jitter), try N=1 once stable.

This also stops the renderer free-running at 500 fps, which would burn GPU and heat the
box running Frigate for frames nobody sees. Credit pacing at 122.14 Hz also means the
renderer naturally produces exactly the rate the wall consumes — with SW5=6 (§5.3)
every one of those frames reaches the panels.

**Transport: UDP, not TCP.** A single lost packet under TCP stalls the whole stream for a
retransmit timeout (Linux RTO min ~200 ms) — catastrophic for a visualizer. Under UDP a
lost packet costs one frame; the Pi re-displays the last good one and it is invisible at
122 Hz. This is the same reasoning already documented for the audio feed: *"a lost or late
packet just means the Pi renders with the previous values."* Use a per-frame sequence
number + fragment index, drop incomplete frames, latest-wins.

**Enable jumbo frames** (MTU 9000 on the Pi, the VM vNIC, and the 3850): 147 KB becomes
~17 datagrams instead of ~100, cutting per-packet overhead and interrupt load on the Pi.

### 5.6 Four independent clocks

Desktop audio (48 kHz DAC), ubuntu-server render pacing, Pi DPI vblank (RP1 PLL), and
FPGA refresh (its own PLL off the 12 MHz FTDI reference) are **four free-running clocks**.
They will drift. Every stage must be latest-wins or credit-paced so drift produces a
repeated or dropped frame, never a growing queue. The FPGA's skip-gated handoff
(gateware v0.2) now makes the DPI↔scan boundary drop-safe *by construction* — the same
philosophy this section demands of every other stage. Don't chase this as a bug when it
shows up as an occasional duplicated frame; LED D8 tells you when the FPGA is the one
dropping (it should stay dark at SW5=6).

### 5.7 The compensation you already have

`beat.py` is a **predictive** tracker — `beat_phase` is described as an *"anticipatory
0→1 ramp hitting 1.0 ON the predicted beat."* That is a latency-compensation mechanism
already in the codebase. Adding a signed constant offset lets beat-locked content render
*ahead* of the audio by the measured pipeline depth, driving effective sync toward zero
regardless of the ~60 ms transport budget.

**But measure the net offset, don't minimize the visual path blindly.** The audio you
*hear* is also delayed — if monitoring through the Denon AVR (192.168.2.130), AV receivers
commonly add 30–90 ms of DSP latency, which can exceed the entire visual pipeline. In that
case the visuals are already running *ahead* and want delaying, not advancing.

> **Expose a signed `--latency-comp <ms>` knob, tune it by eye against the actual
> listening setup, and record per-output-path values.** This is worth more than any
> further micro-optimization of the transport.

## 6. Work breakdown

Each phase is independently testable and a natural commit boundary.

### Phase 0 — Headless EGL on NVIDIA *(blocker; do first, it de-risks everything)*
`rayglow/render/egl.py:304` hardcodes `EGL_PLATFORM_SURFACELESS_MESA` (0x31DD), a
Mesa-only platform NVIDIA's proprietary driver does not implement. Add an
`EGL_PLATFORM_DEVICE_EXT` (0x313F) path via `eglQueryDevicesEXT` +
`eglGetPlatformDisplayEXT`, selected at runtime with the Mesa path as fallback.

- Keep **GLES3, not desktop GL 4.6** — costs nothing on NVIDIA and preserves Mesa/Pi
  dry-runs, which is worth more than any GL 4.x feature here.
- Needs `libEGL.so.1` + `libGLESv2.so.2` on the ubuntu-server *host* (libglvnd + driver);
  Frigate's Docker/NVIDIA-container-toolkit setup does not put them there by itself.
- **Accept:** `python -m rayglow.render <shader> --dry-run 120 --no-listen` produces a
  correct GIF on ubuntu-server with no X/Wayland running, and `GL_RENDERER` reports the
  4080.

### Phase 1 — Audio feed retarget
Set `RAYGLOW_HOST=192.168.1.101` on the desktop. No code change.
- **Accept:** `milk-verbose.glsl` dry-run on ubuntu-server reacts to music playing on the
  desktop; all feature bars move.

### Phase 2 — Frame transport
New network sink on the render host; new `rayglow.framesink` module on the Pi (socket +
`drm_out`, no GL). UDP, jumbo frames, seq + fragment index, drop incomplete, latest-wins.
Credit-based flow control with N=2.
- **Accept:** wall renders a known shader from ubuntu-server at 122.14 fps. `--output
  kms` still works on the Pi. Sustained run shows **no latency growth over 30 min** (the
  bufferbloat test — log observed frame age, it must be flat, not climbing) **and EVN
  LED D8 stays dark throughout** (SW5=6 — proof the FPGA consumed every frame too).

### Phase 3 — Measurement and tuning
Instrument a stats line matching the existing convention (`fps render net wait`). Measure
real end-to-end latency (phone slow-mo of a percussive hit vs. the wall is sufficient and
honest). Tune `--latency-comp`.
- **Accept:** measured end-to-end within ~2× of the §5.1 budget; if not, the budget is
  wrong and gets revised here.

### Phase 4 — Reclaim the headroom
With ~950× the GPU, revisit what was previously unaffordable: `scale` back up, heavier
multipass, shaders that were shelved as too slow.
- **Accept:** at least one previously-unrunnable shader running at the full 122.14 fps
  credit cadence.

### Phase 5 — PoE consolidation *(independent; can happen any time)*
See §7.

## 7. Infrastructure notes

**VLAN — resolved.** The Pi currently sits on `192.168.2.113` (IoT VLAN 20) only because
VLAN 10 was reserved for wired devices. Moving it to the unused wired port in the display
room puts it on VLAN 10 alongside ubuntu-server, so the ~144 Mbit/s frame stream (the
122.14 Hz production rate) stays L2
on the 3850's switch fabric and never hairpins through the OPNsense VM. **This must happen
before Phase 2** — do not benchmark the transport across the VLAN boundary and draw
conclusions from it. (Will 2026-08-02: confirmed — all devices will be wired on VLAN 10.)

**PoE.** The room's second port can carry both power and data. The switch is not the
limit: WS-C3850-24XU-S is **60 W/port UPOE, 580 W system budget**; nine Reolinks at ~6 W
leave ~500 W spare. Load is ~30 W (headless Pi 5 ~8–12 W, ECP5-EVN at 12 V ~1–1.5 A).

- **A PoE HAT is impossible** — the 40-pin header is fully occupied by the DPI ribbon to
  JP8, mechanically before electrically. Power must arrive by USB-C.
- Topology: one UPOE run → 12 V splitter at the wall → 12 V direct to the EVN barrel, plus
  a 12 V→5 V **synchronous** buck → USB-C to the Pi.
- **Do not use the LM2596 stock for the Pi** — non-synchronous, 3 A ceiling, ~75%
  efficient, poor transient response, against a load with sharp current steps.
- Cisco UPOE is pre-802.3bt 4-pair 60 W; a generic 802.3bt Type 3 splitter may negotiate
  down to 25.5 W if LLDP doesn't line up, which is tight against 30 W. Either measure what
  a bt splitter actually delivers, or use two guaranteed 802.3at splitters (12 V for the
  FPGA, 5 V USB-C for the Pi) at the cost of a second drop.
- **On the historical undervolt:** fatter all-copper cable fixes IR drop, which was
  probably not the root cause. The Pi was on the same 5 V rail as a 24-panel HUB75 wall —
  a violently pulsed load (BCM switching at 140 Hz, tens of amps at fast edges) that dips
  the rail and moves the shared ground reference. No amount of copper fixes sharing a rail
  with that. PoE fixes it correctly because PoE is **transformer-isolated (1500 Vrms per
  spec)**: the Pi gets an independent supply and its own ground reference, and grounds bond
  at exactly one controlled point — which is what the star scheme in
  `rayglow/hardware/POWER-AND-GROUNDING.md` already does.

## 8. Risks

| Risk | Severity | Mitigation |
|---|---|---|
| Unbounded queueing → drifting latency | **High** | Credit-based flow control (§5.5); test explicitly in Phase 2 |
| NVIDIA EGL device platform doesn't come up headless | Medium | Phase 0 is first precisely so this fails cheap |
| Pathological shader hangs the GPU → driver reset kills Frigate's TensorRT context | Medium | Bound every march loop with a constant iteration cap. Compute sharing is safe; *fault* sharing is not. This is the one honest argument for a dedicated render box instead of the camera server. |
| SW5 left at 8 → FPGA drops ~15 % of frames (wasted GPU + network, uneven cadence) | Low | Pin SW5=6 (§5.3); D8 lit is the tell-tale |
| Wall now depends on ubuntu-server being up | Low | `--output kms` local render stays as fallback — keep it working |
| Jumbo frames misconfigured on one hop → silent fragmentation | Low | Verify with `ping -M do -s 8972` end to end |

## 9. Open questions

1. Where should the frame protocol live — extend `rayglow/feed/` (which already owns
   packet framing and latest-wins semantics), or a new `rayglow/link/`? The feed module's
   philosophy transfers cleanly; the payload size does not.
2. Should the Pi's `framesink` be a separate console entry point, or `--output kms
   --source net` on the existing module? The Pi no longer needs the GL stack at all, which
   argues for a separate, dependency-light module.
3. Does the control plane (TCP :5006 — shader switch/push, media controls) move to
   ubuntu-server with the renderer? Almost certainly yes, since it controls rendering. Confirm
   nothing on the Pi side depends on it.
4. Is `scale=2` still the right default with ~950× the GPU, or is the LED wall's real
   limit elsewhere (panel pitch, BCM depth)? Phase 4 should answer empirically rather than
   assuming more supersampling is better.

## 10. Prior art in this project

Three patterns here already exist and should be reused rather than reinvented:

- **Credit/READY flow control** — the RP2350 PIO link self-paces off a READY line.
  Same idea, different wire.
- **Latest-wins packet semantics** — the audio feed already drops late packets rather than
  queueing them. Same idea, bigger payload.
- **Additive flag-guarded transports** — `--transport spi` survived the PIO bus and
  `--output wall` survived `--output kms`. Same idea, third instance.

## 11. As-built (2026-08-02, `feat/remote-render`) + bring-up runbook

### 11.1 What was built, and where it deviates from the plan above

| Piece | File(s) | Notes |
|---|---|---|
| Phase 0: NVIDIA headless EGL | `render/egl.py`, `--egl` / `$RAYGLOW_EGL` | `device` = EGL_EXT_platform_device (CUDA-capable > DRM node > rest; `$RAYGLOW_EGL_DEVICE` pins an index). `auto` keeps surfaceless first, so Pi/desktop behavior is untouched. |
| Phase 2: wire contract | `rayglow/link.py` | 24 B fragment header with explicit byte offsets (MTU 1500/9000 senders interop), 32 B credits, RFC1982 seqs. |
| Phase 2: render-host sink | `render/net_out.py`, `--output net --net-host <pi>` | Gamma/orientation exactly as `--output kms` (FPGA owns gamma). `--fps` defaults to uncapped here — credits are the clock. |
| Phase 2: Pi sink | `rayglow/framesink.py` (`python -m rayglow.framesink`) | Reassemble → `drm_out` page flip → one credit per vblank. No GL on the import path. |
| Contract lock | `tools/link_check.py` | Layout pins, lossy/shuffled/wrapping reassembly, pacing (the §5.5 trap, asserted), restart resyncs — loopback only. |

Three findings that amend the plan:

1. **§6 Phase 0's premise softened**: NVIDIA ≥435 implements
   `EGL_MESA_platform_surfaceless` too (verified on the desktop's RTX PRO 6000,
   driver 610), so `auto` may land on the GPU without help. `--egl device` stays the
   pinned route for ubuntu-server: deterministic vendor + GPU selection regardless of
   glvnd vendor order or a stray Mesa/llvmpipe install.
2. **§5.5's "hold N credits" needed one refinement.** Settling credits by
   highest-seq alone lets a fast renderer settle into a stable render-two-show-one
   pattern (the skip settles both slots at once — 2× GPU/network for nothing, the
   SW5=8 waste reinvented). As built, credits replenish send-tokens per page FLIP
   (absolute counters, loss-healing), skips deliberately eat a token, reported drops
   replenish. Loopback-measured: converges to exactly one send per flip after a
   1-frame startup skip; `age` flat at one flip period.
3. **Jumbo frames are opt-in** (`--net-mtu 9000`), default 1500 — ~102 datagrams/frame
   works fine on loopback and same-switch GbE; flip to 9000 only after
   `ping -M do -s 8972 <pi>` passes end to end (§8's silent-fragmentation risk).

### 11.2 ubuntu-server one-time setup

```
# GL userspace: glvnd dispatch + NVIDIA's GL/GLES ICD (the driver metapackage may
# already provide libnvidia-gl; headless/compute-only installs do not)
sudo apt install libegl1 libgles2 libnvidia-gl-<driver-version>

# clone lands via mutagen (11.5); editable install into the venv, same as the Pi:
uv venv ~/venv && uv pip install --python ~/venv/bin/python -e ~/rayglow

# Phase 0 accept — GL_RENDERER must say RTX 4080, "EGL device":
cd ~/rayglow && RAYGLOW_EGL=device ~/venv/bin/python -m rayglow.render \
    rayglow/render/presets/milk-verbose.glsl --dry-run 120 --no-listen
```

Ports in: UDP 5005 (feature feed), TCP 5006 (control plane). Out: UDP → Pi 5007.

### 11.3 Pi framesink

```
sudo ~/venv/bin/python -m rayglow.framesink            # DRM master on the DPI CRTC
# if the printed rcvbuf says "kernel clamped": sudo sysctl -w net.core.rmem_max=4194304
```

### 11.4 Run it (Phase 1+2 accept)

```
# desktop:        RAYGLOW_HOST=<ubuntu-server> sender/uv run sender.py
# ubuntu-server:  RAYGLOW_EGL=device ~/venv/bin/python -m rayglow.render \
#                     rayglow/render/presets/milk-verbose.glsl \
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

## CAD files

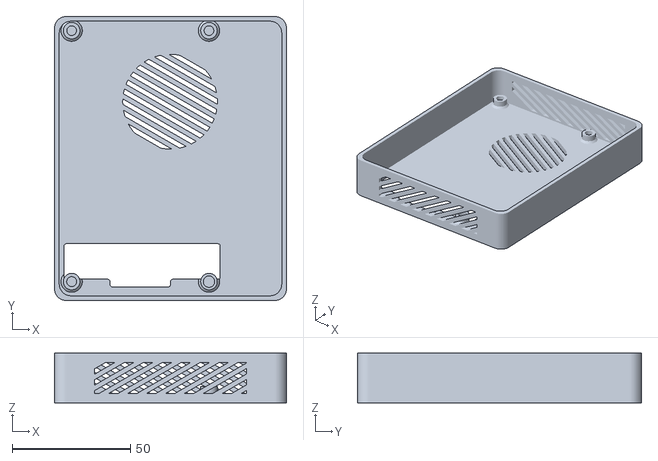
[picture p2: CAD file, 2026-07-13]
hardware/3dprint/rayclose-cover-v2.stl
98.0 x 120.0 x 21.0

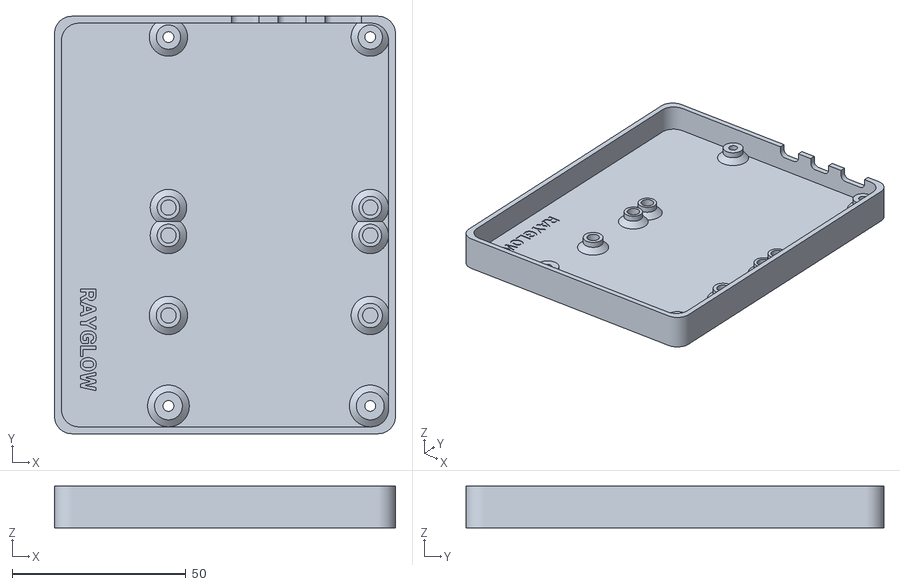
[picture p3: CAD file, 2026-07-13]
hardware/3dprint/rayglow-base-v2.stl.stl
98.0 x 120.0 x 12.0

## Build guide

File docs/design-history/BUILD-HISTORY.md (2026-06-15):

> **Archived as written, 2026-06-07.** A knowledge-export brain-dump from the Pi-side
> build agent, captured just before this repo restructure — so its paths and package
> names refer to the **pre-RayGLow** layout: `rpi-custom/` is now this repo,
> `milk/` → `rayglow/feed` + `rayglow/legacy`, `shadertoy/` → `rayglow/render`,
> `MilkDrop3/project-milk-pi.md` → `docs/design-history/project-milk-pi.md`. The
> *facts* (hardware tuning, EGL quirks, calibration constants, load-bearing oddities)
> are the point and remain accurate; mentally remap the paths. Items marked
> **(uncertain)** are reconstructed from summarized context — verify exact figures.

# BUILD-HISTORY.md

Knowledge export for `rpi-custom/` — the undocumented "why" behind the code.
Captures decisions, dead ends, empirical quirks, calibration, and load-bearing
oddities that are NOT already in code docstrings, the repo `CLAUDE.md`, or
`MilkDrop3/project-milk-pi.md`. Facts and history only.

Things marked **(uncertain)** are reconstructed from summarized memory rather than
direct recall — verify before trusting the exact figure. The *shape* of these claims
is reliable; specific decimal values may have drifted across context compaction.

Scope note: three subsystems live here — the standalone numpy visualizers
(flocking, plasma, navier-stokes, etc.), the **milk** MilkDrop-style renderer, and
the **shadertoy** GPU pipeline. The milk renderer's own architecture is documented
in `MilkDrop3/project-milk-pi.md`; this file deliberately does not repeat it.

---

## 1. Decision log — non-obvious decisions and why

### Hardware

- **`gpio_slowdown=5`, not 4.** With hardware OE pulsing active, slowdown 4 produced
  rare end-of-line data corruption on panel 1 (the first panel, which is both first in
  the data chain and the only one referenced across the Pi↔panel ground boundary).
  Slowdown 5 buys sampling margin at the cost of some refresh duty. This was an
  experimental finding from the `tuner.py` sweep, not a guess.
- **The ground strap is what actually fixed the artifact**, not slowdown alone. A wire
  from a Pi header GND to panel-1's power-GND lug, routed along the ribbon, stiffened
  the voltage reference. Slowdown 5 + ground strap together reduced the artifact to
  "only visible if you go hunting for it." The ribbon's own ground wires were too weak
  a tie on their own.
- **`adafruit-hat-pwm` requires a physical solder mod** (GPIO4↔GPIO18 jumper). Setting
  `disable_hardware_pulsing=0` on plain `adafruit-hat` silently did nothing: OE was on
  GPIO4, and `HardwarePinPulser::CanHandle` only accepts GPIO18/12, so it fell back to
  the software TimerBasedPinPulser with no error. The mod moves OE onto GPIO18 where the
  hardware pulser engages.
- **Panel physically flipped instead of a `Rotate:180` pixel mapper.** The earlier
  `Rotate:180` mapper was retired once the panel was mounted the right way around —
  no mapper is now configured. (uncertain: whether any script still references the old
  mapper.)
- **`pwm_lsb_nanoseconds=130`** is the library default and was deliberately *kept* after
  testing — raising lsb made the panel-1 artifact **worse**, not better (it lengthens
  the lit window during which in-flight bits get corrupted).
- **`pwm_bits=10`, not 11.** (uncertain on the exact reasoning) — 10 was the settled
  value in the tuned config; 11 bits costs refresh rate for a bottom-end gradient
  improvement that wasn't worth it on these panels.

### Software architecture

- **`milk/config.py` is the single source of truth for geometry**, and the shadertoy
  pipeline imports it (`from milk import config`) rather than duplicating the 256×32
  numbers. `CHAIN=4` is the one knob if the removed 5th panel returns.
- **`drop_privileges = 0` for the shadertoy runner** (we keep root). Hot reload re-reads
  the `.glsl` from `` after `RGBMatrix()` is constructed, and `` is
  mode 0700 — the `daemon` user the library drops to cannot traverse it. Since these
  tools already run under `sudo`, staying root is the path of least resistance. See §3
  and §5.
- **Render thread pinned to core 0** (`RENDER_CORE=0` in config), because the hzeller
  GPIO update thread owns core 3. CPU pinning is per-thread on Linux, so this does not
  disturb the matrix thread.
- **Protocol v1 was designed additively, not as a replacement.** When the true sub-bass
  band was added, the receiver was made to accept *both* v0 (556 B) and v1 (564 B); a
  v0 packet reports `sub = bass`. This means the Pi and the desktop sender can be
  upgraded in either order without breaking. The MilkDrop band split (bass/mid/treb)
  was left completely untouched because the `.milk` presets depend on its exact edges.
- **The `milk` iChannel texture was introduced specifically to escape the audio
  texture's dynamic-range clamp.** Shadertoy's audio-texture spectrum is Web-Audio
  dB-mapped and everything above roughly −30 dB clamps to 1.0, so bass reads pinned high
  whenever music played (the user observed this as "binary" behavior; shadertoy.com
  behaves identically). The `milk` texture exposes the sender's auto-gained scalars
  instead, where values above 1.0 survive.
- **Derived signals (d/dt, envelope, integrated phase) were cooked into the `milk`
  texture rather than left to per-shader buffer files**, so most audio-reactive shaders
  need no `.bufA.glsl` at all. The shaped-velocity case (a `BASE_RATE + BOOST` integrator
  like `will-helix.bufA.glsl`) still needs a buffer file because those are artistic knobs
  the pipeline can't guess.
- **GLSL `#version 300 es`** chosen for the preamble: Shadertoy targets WebGL2 = GLSL ES
  3.00, which is the closest dialect match. The Pi's driver is actually ES 3.10 / GLSL ES
  3.10 and compiles the 3.00 source fine.
- **`#define HW_PERFORMANCE 0`** added to the preamble after a user-reported error:
  shaders that did `#if HW_PERFORMANCE == 0` failed to compile because Shadertoy injects
  that macro server-side and it wasn't present locally. 0 = the mobile/low-power branch.

### Tuning sessions

- **The amplitude/theta "always maxed" problem** was traced to the audio-texture dB
  clamp described above, not to the user's smoothstep ranges. The fix was upstream
  (expose auto-gained scalars), not a threshold tweak.
- **The subwoofer-invisibility investigation** (user held a hand to the sub and saw no
  correlation): MilkDrop's "bass" band is linear FFT bins 0–85 ≈ 0–4 kHz, and the
  log-equalize table suppresses the lowest bins heavily. So "bass" tracks low-mids, and
  an actual subwoofer (~25–117 Hz, the lowest ~2 bins) is nearly absent from it. This is
  faithful MilkDrop behavior, not a bug — hence the additive sub band rather than a
  re-tune of the existing split.

---

## 2. Dead ends — tried and abandoned

- **`disable_hardware_pulsing=0` on plain `adafruit-hat`** — appeared to enable hardware
  PWM but silently fell back to software pulsing (OE on the wrong GPIO). Abandoned for
  the solder mod + `adafruit-hat-pwm`. (See §1.)
- **Raising `pwm_lsb_nanoseconds`** to fight the panel-1 artifact — made it worse.
  Reverted to 130.
- **Bulk capacitance as the artifact fix** — a 2200 µF cap was added at panel 1's power
  input during debugging; it made no difference to the artifact (left installed anyway,
  harmless). The artifact was a *signal-integrity / ground-reference* problem, not a
  power-sag problem. Twisting the jumper wire into a tight pair to kill EMI also did
  nothing — ruled EMI out.
- **`Rotate:180` pixel mapper** — worked, but retired in favor of physically flipping
  the panel.
- **BLE as the desktop→Pi transport** — evaluated and rejected (documented in
  `project-milk-pi.md §7`: throughput, latency floor, MTU fragmentation, and the Pi 4's
  shared WiFi/BT antenna). Noted here only so it isn't re-explored.
- **`np.percentile` / lazy numpy imports inside the render loop** — worked headless,
  crashed on hardware. `numpy.ma` is imported lazily on the first `np.percentile()` call;
  if that first call happens after the privilege drop, it dies with
  `ModuleNotFoundError: No module named 'numpy.ma'` because site-packages is under
  `~/venv` which `daemon` can't reach. Hit in `gray-scott.py`. The fix (warm up the
  full path before `RGBMatrix()`) is now standard, but the naive version is a real dead
  end that passes every headless test.
- **Audio-texture spectrum as a dynamic control signal** — worked but rejected: the
  −30 dB clamp makes it binary. Superseded by the `milk` texture. The audio texture is
  still present and useful for *waveform* display and for shaders that genuinely want the
  Shadertoy-shape texture.
- **`will-helix.glsl` reading `texelFetch(..., ivec2(4,0), ...)` against the bufA
  channel** — a partial failure that looked right. The `ivec2(4,0)` sub-texel index
  belongs to the *milk* channel; bufA only ever writes texel (0,0), so against bufA that
  fetch reads black and theta/amp come out zero. (uncertain whether the user has since
  corrected the file.)

---

## 3. Hardware & environment quirks (empirical)

### Panels & power

- **P6-3528 64×32 panels**, 4 daisy-chained in one row = **256×32**. Originally 5; one
  removed and may return — check `CHAIN`/`chain_length` before assuming width.
- **One panel has scattered color-specific dead sub-pixels** (~3 with no green, ~5 with
  no red) — a hardware fault from storage, not software. Don't chase it in code.
- **FM6126A panel-type init is NOT needed** — the default init sequence drives these
  panels correctly.
- **Power: 5V 30A supply → thick copper bus** (one +5V run, one GND run touching every
  panel), entering at panel 1 (also first in the data chain). The Pi is powered
  separately over USB. The bus is *stiffest* at panel 1, which is why positional rail
  sag was ruled out as the artifact cause.
- **`snd_bcm2835` must be blacklisted.** The library hard-exits on `adafruit-hat-pwm` if
  the onboard sound module is loaded (PWM hardware conflict). This is a prerequisite for
  the whole PWM path, not optional.

### The panel-1 artifact (root cause, for posterity)

Random flashing in the last ~8–12 px of mirrored scan rows r / r+16, panel 1 only.
Root cause (uncertain on the exact `framebuffer.cc` line, ~985): `DumpToMatrix` clocks
the next bit-plane's data out *while the previous OE pulse is still lit* (by design);
the OE turn-off transient corrupts the in-flight bits at panel 1's inputs — those being
the last-clocked bits, and panel 1 being the only one straddling the Pi↔panel ground
boundary. Fixed by slowdown 5 (sampling margin) + the ground strap (stiffer reference).
`tuner.py` is the sweep harness built to chase this (stress pattern; flags
`--slowdown --lsb --pwm-bits --dither --brightness --show-refresh --animate`).

### Pi & environment

- **Raspberry Pi 4B (4 GB)** is also the dev box — everything builds and runs on the Pi
  itself, including the agent sessions.
- **Pi IP 192.168.0.50**, IoT VLAN, WiFi, DHCP. Desktop→Pi UDP 5005 crosses VLANs with
  no OPNsense rule needed (verified via ICMP-unreachable probe).
- **The Pi filesystem is mounted on the desktop** at `~/pi-mount/`; the user
  edits/copies files across that mount. The desktop sender lives at
  `desktop:~/Projects/milk-pi/sender.py`; `rpi-custom/sender.py` is the
  reference copy the user pushes back to the desktop and restarts there.
- **Ollama server at 192.168.0.20:11434** (gemma3:latest default) for the `ollama.py`
  LLM-shell experiment.

### EGL / GL driver behavior (Pi 4B, V3D)

- **Headless GL works with no X and no GBM**: ctypes `libEGL.so.1` + `libGLESv2.so.2`,
  surfaceless platform `EGL_PLATFORM_SURFACELESS_MESA = 0x31DD`, via `/dev/dri/renderD128`.
- **`eglChooseConfig` returns 0 configs on the surfaceless platform** — this is expected,
  not an error. The no-config-context path (`EGL_KHR_no_config_context`, pass
  `EGL_NO_CONFIG`) works: create context with `{EGL_CONTEXT_CLIENT_VERSION, 3}`, make
  current with `EGL_NO_SURFACE` for both draw and read, render into an FBO.
- **Driver is V3D 4.2, Mesa 25, OpenGL ES 3.1 / GLSL ES 3.10.**
- **V3D supports `EXT_color_buffer_float` AND float-linear filtering**, so RGBA32F render
  targets can use `GL_LINEAR`. This is why the multipass buffers are RGBA32F (values >1
  survive; needed for the integrator state and Game-of-Life age coloring). The `milk`
  texture is RGBA32F NEAREST for the same survives-above-1.0 reason.
- **GPU rendering and GPIO bit-banging coexist fine** — GPU work on core 0, hzeller
  thread on core 3, no measured interference.
- **ctypes binding hazard**: every EGL/GLES function needs explicit `.argtypes`/`.restype`
  or wrong-width args segfault rather than raise. Error-checking (`eglGetError`/
  `glGetError`) is done at init only, not per-frame.

### The venv

- **`~/venv`** holds numpy, PIL, and the `rgbmatrix` Python binding. Run as root via
  `sudo ~/venv/bin/python ...`.
- **Environments are managed with `uv`** (user preference, 2026-06-01): `uv venv`,
  `uv pip install --python /venv/bin/python <pkg>`.
- **How `rgbmatrix` got installed**: the repo became pip-installable in the Feb 2026
  Python overhaul (`pip install .` from the repo root, scikit-build-core + Cython). The
  binding in the venv comes from that. (uncertain whether `venv` was built with
  `--system-site-packages` or the deps were installed directly.)

---

## 4. Magic numbers & calibration

| Constant | Value | Where | Meaning / what changes if altered |
|---|---|---|---|
| `gpio_slowdown` | 5 | config.py | 4 → rare panel-1 end-of-line corruption; higher → dimmer (less duty). |
| `pwm_lsb_nanoseconds` | 130 | config.py | library default; raising it made the artifact worse. |
| `pwm_bits` | 10 | config.py | 11 costs refresh for marginal low-end gradient. |
| `brightness` | 100 | config.py | full. |
| `GAMMA` | 1.2 | config.py | composite exponent; <1 lifts faint trails, >1 deepens blacks. Repo convention is a direct exponent. |
| `WAVE_FIT` | 1.0 | config.py | `.milk` custom-wave vertical map; 1.0 squashes the ~square preset canvas onto 8:1 (all visible, compressed); 0.0 = MilkDrop-faithful (only center 1/8 shows). |
| `FALLBACK_AFTER` | 0.5 s | config.py | silence before synth fallback engages. |
| `RENDER_CORE` | 0 | config.py | core 3 belongs to the GPIO thread. |
| `--scale` (shadertoy) | 4 default | __main__.py | supersample factor; 1 = pixel-exact. Heavy shaders: ~17 fps @4, ~58 @2, ~257 @1 (raymarchers want 2). example.glsl: 582/132/74/24 fps at scale 1/2/4/8. |
| spectrum dB window | −100..−30 dB → 0..1 | textures.py AudioChannel | Web-Audio range; >−30 dB clamps to 1.0 (the binary-bass cause). |
| analyser smoothing | 0.8 | textures.py | Web-Audio default magnitude smoothing. |
| `DDT_LAG` | 25 /s (~40 ms) | textures.py MilkChannel | derivative slew; faster aliases the packet-vs-frame beat, slower blurs onsets. |
| `ENV_LAG` | 8 /s (~125 ms) | textures.py MilkChannel | envelope chase; mirrors will-helix `AMP_LAG` feel. |
| `THETA_WRAP` | 200π ≈ 628.3185 | textures.py MilkChannel | phase wrap; `sin(theta*k)` is seamless only for `k` a multiple of 0.01. |
| will-helix theta wrap | 20π ≈ 62.8319 | will-helix.bufA.glsl | seamless only for line speeds that are multiples of 0.1 (the image pass uses multiples of 0.1). |
| `BASE_RATE` | 0.4 | will-helix.bufA.glsl | idle helix speed when quiet. |
| `BOOST` | 1.6 | will-helix.bufA.glsl | extra speed at strong bass. |
| `LAG` | 3.0 /s | will-helix.bufA.glsl | how fast v chases target (low = flywheel, high = twitchy). |
| `AMP_QUIET / AMP_LOUD` | 0.38 / 1.0 | will-helix.bufA.glsl | wave amplitude range. |
| `AMP_LAG` | 8.0 /s | will-helix.bufA.glsl | amplitude chase (snappier than v so hits swell without strobing). |

### Sender-side audio analysis (constants in `sender.py`, ported from vis_milk2)

- **`WINDOW = 576`** sample analysis window, left channel, Hann envelope, zero-padded to
  **`NFREQ = 1024`**-pt FFT → 512 magnitude bins. This is MilkDrop-exact (`plugin.h:61`,
  `fft.cpp`).
- **`EQUALIZE = -0.02 * ln((512 - i)/512)`** — the log table that suppresses low bins.
- **Band edges `512*i//6` for i=0..3 → bins 0, 85, 170, 256** (`plugin.cpp:8739`). So
  "bass" = bins 0–85 ≈ 0–4 kHz. This is why a subwoofer is invisible in "bass."
- **AutoGain**: `long_avg` retention 0.9 for the first 50 frames (fast converge) then
  0.992; `avg` attack 0.2 rising / 0.5 falling; `imm_rel = imm/long_avg` (1.0 = typical,
  hits spike 2–4). Ported from `plugin.cpp:8750`.
- **Sub band (v1)**: `SUB_WINDOW = 2048` (42.7 ms @ 48 k → 23.4 Hz/bin), Hann envelope,
  **no equalize**, `SUB_BINS = slice(1, 6)` = bins 1–5 = **23–117 Hz** (bin 0 = DC,
  skipped), its own AutoGain. `SAMPLE_RATE = 48000`.
- **Measured proof of the band problem** (uncertain on exact decimals): a 3 kHz tone
  reads roughly 55× stronger in the "bass" band than a 40 Hz tone; the new sub band reads
  ~1015 at 40 Hz and essentially 0.0 at 1 kHz. Low bins are suppressed ~90× by equalize.

### Packet sizes

- **v0 = 556 bytes**, `<IHHIf7f128f` (magic, ver, flags, seq, t, 6 bands + vol, wave[128]).
- **v1 = 564 bytes**, `<IHHIf7f128f2f` (appends sub, sub_att).
- **Magic = 0x4D494C4B ("MILK")**, UDP port 5005, ~60 Hz, ~33 KB/s at v0.

---

## 5. Load-bearing oddities — looks wrong/redundant, breaks if "fixed"

This is the most important section. Each item looks like cruft or a mistake and is not.

- **`drop_privileges = 0` in the shadertoy runner is intentional, not a security
  oversight.** Reverting it to the default breaks hot reload: the `daemon` user can't
  traverse `` (mode 0700) to re-read the `.glsl`. Everything here runs under
  sudo by necessity (GPIO), so staying root is deliberate.
- **All imports and file loads happen BEFORE `RGBMatrix()` everywhere.** This is not
  stylistic ordering — it's the privilege-drop guard. A lazy import (`numpy.ma` via
  `np.percentile`, PIL plugin loading, any `from . import x` inside a draw path) that
  first fires *after* construction crashes on hardware while passing every headless test.
  The shadertoy runner even does a throwaway `feed.update()` + `toy.render()` + a PIL
  `Image.fromarray()` before constructing the matrix purely to warm those paths. Do not
  "clean up" the warm-up call.
- **`pwm_lsb_nanoseconds=130` is set explicitly to the library default.** It looks
  redundant (it equals the default) but it documents that the value was tested and that
  raising it regresses the panel-1 artifact. (uncertain whether removing it would change
  behavior — it shouldn't, but the comment carries the calibration history.)
- **The 2200 µF cap at panel 1 does nothing for the artifact** and is left installed
  anyway. Don't remove it expecting a change; don't add more caps expecting a fix — the
  artifact was ground-reference, not power.
- **The MilkDrop band split (0/85/170/256) is deliberately "wrong" for sub-bass and must
  stay that way.** The `.milk` presets are tuned against those exact edges; "fixing" the
  bass band to include sub frequencies would change how every preset reacts. The sub band
  was added *alongside* it for this reason.
- **`milk` texture is 8×1 but only 7 texels are used; texel 7 is zero.** Reserved
  headroom, not a bug. Texels 5–6 hold derived signals (phase, packet age, live flag),
  not band scalars — indexing them as if they were a 6th/7th band reads nonsense.
- **`vol` writes the same value to `.x` and `.y`** in the milk texture (imm and att are
  identical for volume). Looks like a copy-paste error; it's intentional so shaders can
  treat every band uniformly (`.x`/`.y` always valid).
- **`milk` texture derived signals start `_env` at 1.0 and skip derivatives on the first
  frame** (`dt == 0`). Seeding env at 0 would make every visual fade up from black on
  start; the first-frame derivative skip avoids a divide-by-zero spike.
- **`will-helix.bufA.glsl` reads bass from `texelFetch(iChannel1, ivec2(4,0), 0).x`
  (the *sub* texel) but amplitude from `ivec2(0,0).y` (bass_att).** Mixing sub for rate
  and bass for amplitude is deliberate tuning, not an inconsistency — see the in-file
  comment about position-like vs size-like signals.
- **The shadertoy preamble defines `main()` itself and forbids the user shader from
  defining one** (regex-detected → clear error). A shader that defines `main` isn't
  broken Shadertoy code; the wrapper just owns `main` and calls the user's `mainImage`.
- **`eglChooseConfig` returning 0 is not checked as an error.** On surfaceless V3D that's
  the normal result; the no-config-context path is taken on purpose. A "fix" that bails on
  0 configs would break all headless rendering.
- **GLSL error line numbers are remapped** by subtracting the preamble line count. If the
  preamble grows (e.g. the `HW_PERFORMANCE` define was added), `PREAMBLE_LINES` must track
  it or every reported error line is off. This coupling is invisible until it's wrong.
- **`milk-verbose.glsl` / `milkfeed.glsl` convert `gl_FragCoord` to panel pixels via
  `floor(I / iResolution.xy * PANEL)`.** A naive 1-px bar at `--scale 4` would render at
  quarter brightness (it'd cover 1 of 4 supersamples). The conversion is required for any
  pixel-exact UI element, not decoration.
- **Channel directives live in `.glsl` comments** (`// iChannelN: spec`), not just CLI
  flags, *because Shadertoy stores bindings in site metadata, not the shader source.*
  Porting a multipass shader without them silently binds the wrong/black textures.
- **The receiver keeps only the highest-`seq` packet per frame and never blocks.** During
  testing, a hand-crafted test packet "lost" to the live desktop stream — that was the
  latest-wins logic working correctly, not a bug. Don't add blocking reads to "fix"
  dropped test packets.
- **`fake_sender.py` is kept even though the real desktop sender supersedes it.** It's the
  music-free local test harness AND an executable spec of the packet format — it was
  updated to v1 in lockstep so it doubles as the protocol reference.

---

## 6. Unfinished threads

- **The desktop sender must be redeployed for v1 to take effect live.** Until
  `rpi-custom/sender.py` is copied to `desktop:~/Projects/milk-pi/sender.py`
  and restarted, the live stream is v0 and `sub` falls back to `bass`. The Pi side already
  accepts both, so order is safe. (uncertain: whether the user has now done this — they
  reported "reconfiguring of the sender.py ran without issue," which suggests yes.)
- **`will-helix.glsl` image-pass channel index** may still read `ivec2(4,0)` against bufA
  (always black). Suspected the `ivec2(4,0)` edit landed in both the image and buffer
  files when it belonged only in the buffer file. (uncertain if corrected.)
- **`milk` texture texel 7 is reserved and unused** — left open for a future signal
  (CPU temp/usage was discussed as a candidate and explicitly NOT added, since nothing
  consumes it yet and `/sys` temp / `/proc/stat` are second-scale reads, not 60 Hz).
- **Optional flicker-reduction steps never taken** (rig is "good enough"): `isolcpus=3`
  core isolation via cmdline.txt (`isolcpus=domain,managed_irq,3 nohz_full=3 rcu_nocbs=3
  irqaffinity=0,1,2`), the repo's `optimized-kernel/` prebuilt kernel, and re-testing
  `slowdown=4` now that the ground strap exists (`tuner.py` makes it a 1-minute test).
- **Per-line phases for will-helix** (10 independent state texels so each helix line has
  its own phase) — suggested, not built.
- **64-bar per-bin FFT variant of milkfeed** — suggested, not built.
- **Latency hardening shelved** — WiFi power-save off, or a point-to-point Ethernet link
  to the desktop's idle X540 NIC (full recipe in `project-milk-pi.md §7`).

---

## 7. Timeline sketch (approximate; uncertain on exact dates)

- **~2026-02 (Feb):** repo Python overhaul — whole repo becomes pip-installable
  (scikit-build-core + Cython). `rgbmatrix` ends up in `~/venv` from this.
- **~2026-06-01:** user adopts `uv` for venv management.
- **Early June 2026:** hardware artifact hunt — PWM solder mod, `snd_bcm2835` blacklist,
  `tuner.py` sweeps, the elimination chain (EMI / bulk cap / rail sag all ruled out),
  ground strap installed, settled on slowdown 5 + lsb 130. Rig declared stable.
  Standalone numpy visualizers built across this period (flocking, plasma,
  navier-stokes/LBM, phase-flow, fields, gray-scott, ollama shell, etc.).
- **June 2026 — Milk-Pi:** MilkDrop reverse-engineered on the desktop (Wine), packet
  protocol v0 defined, Pi renderer + fake_sender built and verified headless, then the
  `.milk` dotmilk subpackage (parser/eel/runtime/waves/custom/triage), 311 presets
  parsed, ~142 keepers, run on hardware with the live desktop sender — "working pretty
  much flawlessly." Project considered shipped.
- **June 2026 — shadertoy pipeline:** v1 single-pass + hot reload (hardware-verified
  side-by-side vs browser, "high fidelity"); v2 iChannel textures + audio (the
  `HW_PERFORMANCE` fix landed here after a user report); v3 multipass Buffer A–D
  (Game-of-Life and A→B chain ordering verified headless). User curates a ~40-shader
  `presets/` collection.
- **June 2026 — audio dynamic-range work:** diagnosed binary bass (dB clamp) → added the
  `milk` channel; built `will-helix` forward-Euler integrator (bufA) as a teaching
  example of velocity-vs-position; diagnosed subwoofer invisibility (band edges +
  equalize) → protocol v1 with a true 23–117 Hz sub band across sender/receiver/features/
  fake_sender/textures; built `milkfeed.glsl` (5-bar live diagnostic) and `milk-verbose.glsl`
  (every-float reference card); extended the `milk` texture with d/dt, envelope, integrated
  phase, packet age, and live flag.
- **2026-06-07:** this knowledge export written, ahead of a planned repo restructure.
```

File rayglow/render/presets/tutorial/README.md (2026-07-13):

# Shader tutorial — from a pixel to a raymarched scene

A hands-on path for building GLSL intuition on the RayGLow panel. Each file is a
complete, runnable shader whose **comments are the lesson** — open the `.glsl`
and read top-to-bottom, then run it and tweak the numbers. Audio is left out on
purpose; this is about *seeing a thing in your head and knowing the function
that draws it*.

Read them in order — each introduces exactly one new idea and reuses everything
before it.

| # | file | the one new idea |
|---|---|---|
| 00 | `00-hello-pixel.glsl` | a shader is a **pure function from pixel position to color**; the coordinate systems; this panel's 8:1 shape |
| 01 | `01-distance-and-shapes.glsl` | distance → brightness; `step` vs `smoothstep` (anti-aliasing); disc and ring |
| 02 | `02-the-line.glsl` | "drawing a line" = thresholding distance-to-a-line; the segment SDF |
| 03 | `03-sdf-2d-and-ops.glsl` | **signed** distance + the sign convention; *seeing the field*; union/intersection/subtract; `smin` |
| 04 | `04-transforms-repeat-color.glsl` | transform the coordinates not the shape; infinite repetition; the IQ cosine palette + motion |
| 05 | `05-raymarch-intro.glsl` | the leap to 3D: rays, sphere-tracing, the march loop |
| 06 | `06-raymarch-lighting.glsl` | SDF-gradient normals + diffuse light + a real camera — the 3D payoff |

## Running them

Headless (no panel, no root) — renders a GIF you can open:

```fish
~/venv/bin/python -m rayglow.render \
    rayglow/render/presets/tutorial/00-hello-pixel.glsl --dry-run 120 --no-listen
# -> writes /tmp/shadertoy_out.gif  (override with --out)
```

On the panel — and the best way to learn is to **leave it running and edit**:
the renderer hot-reloads on save, so change a constant, save, watch the LEDs
recompile.

```fish
sudo ~/venv/bin/python -m rayglow.render \
    rayglow/render/presets/tutorial/03-sdf-2d-and-ops.glsl
```

## The single most important habit

When a shader doesn't look the way you pictured, **stop drawing the shape and
draw the field** — assign `d` to a color everywhere instead of thresholding it
(file 03 is built entirely around this). Being able to *see* your distance
function is what turns SDF work from guess-and-check into something you reason
about.

## Designing for *this* panel

256×64 is a strong letterbox. With the centered coords used throughout
(`p = (fragCoord - 0.5*iResolution.xy)/iResolution.y`), the visible world is
about **4 units wide and 1 unit tall** (`p.x ∈ [-2,2]`, `p.y ∈ [-0.5,0.5]`).
Consequences worth internalizing:

- **Big shapes, low spatial frequency.** Anything finer than a few of the 64
  rows disappears. Contour/stripe frequencies that look great at 1080p alias to
  mush here — keep them low (see the `cos(d * 80.0)` note in file 03).
- **Use the long axis.** Scrolling waves (02), tiled rows (04), and orbiting
  cameras (06) all play to the width.
- **Anti-alias everything.** Prefer `smoothstep` over `step`; hard edges land
  between LEDs and stair-step. The renderer supersamples (`--scale 2` by
  default) which helps, but soft edges in the shader help more.

## Where to go next

- **Steal from the corpus.** The `presets/` folder one level up is dozens of
  real Shadertoy shaders. With files 00–06 under your belt, open any of them
  and you'll recognize the moves: `length()-r`, `smoothstep` edges, palette
  cosines, a `map()` + march loop.
- **The canonical references** (these files lean on his results):
  Inigo Quilez's [2D distance functions](https://iquilezles.org/articles/distfunctions2d/),
  [3D distance functions](https://iquilezles.org/articles/distfunctions/), and
  [smooth minimum](https://iquilezles.org/articles/smin/). The
  [Ray Marching chapter](https://www.shadertoy.com/view/4dSfRc) and "The Book of
  Shaders" are gentle companions.
- **Extend file 06.** It's a minimal but real raymarcher. Add shapes to `map()`
  (combine with `min`/`smin`), add a second light, try soft shadows or ambient
  occlusion, swap the base color for a palette driven by the hit position.

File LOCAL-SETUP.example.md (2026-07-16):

# Local setup (template)

RayGLow ships with **generic placeholder** addresses/paths so the repo is clean to
publish. Your real rig values live in `LOCAL-SETUP.md` (this file's gitignored twin —
copy this file to it and fill in the blanks). Nothing in the tracked code reads
`LOCAL-SETUP.md`; it's a human record + a place to keep the two env vars the sender
honours.

## Runtime overrides (the only values code actually reads)

The sender resolves the Pi's address as `--host` → `$RAYGLOW_HOST` → built-in
placeholder. Set the env vars once (e.g. in `local.env`, also gitignored, or your
shell profile):

```fish
set -x RAYGLOW_HOST 192.168.0.50      # your Pi's IP (sender + rayglow-ctl share this)
set -x RAYGLOW_PORT 5005              # UDP feature port (default 5005)
# RAYGLOW_CONTROL_PORT 5006           # renderer control plane; only if you moved it
```

`tools/rayglow_ctl.py` (control plane) reuses `$RAYGLOW_HOST` but has its **own**
port (`--port` → `$RAYGLOW_CONTROL_PORT` → 5006) — do not point it at
`$RAYGLOW_PORT`, that's the UDP feed. On the desktop, drive it with a fish
abbr, e.g. `abbr -a rgc 'python3 ~/Projects/rayglow/tools/rayglow_ctl.py'`.

Everything else below is just edited directly in the files noted, or recorded here so
you remember what the placeholders stand for on your network.

## Value map (placeholder → your value)

| Thing | Placeholder in the repo | Your value | Where it appears |
|---|---|---|---|
| Pi IP (feature receiver / render host) | `192.168.0.50` | `__________` | `$RAYGLOW_HOST`, sender docs |
| Desktop IP (sender host) | `192.168.0.10` | `__________` | design-history diagrams only |
| Pi venv path | `~/venv` | `__________` | README/CLAUDE deploy, run examples |
| Pi repo copy | `~/rayglow` | `__________` | `git clone` target, or the receiving end of a file sync (e.g. a mutagen session pushing from the dev machine) |
| Extra shader library sync (optional) | — | `__________` | a second sync session for out-of-repo presets (e.g. `~/Projects/rayglow-shaders` → Pi `~/presets`) |
| UDP feature port | `5005` | `__________` | `config.UDP_PORT`, `$RAYGLOW_PORT` |
| Renderer control port (TCP) | `5006` | `__________` | `config.CONTROL_PORT`, `--control-port`, `rayglow-ctl --port` |

## Rig-specific hardware notes (edit in `rayglow/feed/config.py`)

- `FLIP_H` / `FLIP_V` — panel-wall orientation. Verify yours with
  `python -m rayglow.spi_test --fliph --flipv` and set to match.
- Panel geometry (`ROWS`/`COLS`/`CHAIN`/`PARALLEL_CHAINS`) — change if your tile count differs.
- If the feed crosses VLANs/subnets, add a firewall rule for the UDP port (and
  the TCP control port 5006 if you drive `rayglow-ctl` from the desktop). The
  control plane binds all interfaces by default (`config.CONTROL_HOST`); set it
  to `127.0.0.1` and use an ssh tunnel if the LAN is untrusted.

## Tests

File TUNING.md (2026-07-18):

# Tuning Guide — rayglow over the RP2350 link

This is the knob reference for the split rig: **rpi5 renders + packs**, ships packed
bit-plane frames to the **rp2350b** (4-lane parallel PIO bus by default, SPI as the
fallback), which drives the 384×128 HUB75 wall with a zero-CPU PIO+DMA engine.

## Mental model: two sides, one link

| | **rpi5** (`rayglow` package) | **rp2350b** (`firmware/`) |
|---|---|---|
| Owns | **Content** — pixels, gamma, orientation, resolution, fps | **Timing** — HUB75 pixel clock, BCM/OE brightness, refresh |
| Change via | `config.py` + CLI flags | editing a `.rs` const |
| Takes effect | next run (no reflash) | **only after `cargo run` reflash** |

The link carries *only frame content* (a 192 KB packed bit-plane buffer — identical
bytes over PIO or SPI). So anything about *how the panels are lit* (brightness, clock,
refresh) is firmware and needs a reflash; anything about *what is drawn* is rpi5-side
and is live.

---

## Reading the stats line (what is clamping my FPS?)

The renderer prints a 5-second rolling line:

```
  fps  render  pack  send  wait   (PIO floor 2.0ms @ clkdiv 3)
```

- **`render`** — GLSL execution + resolve pass + readback (main thread). The readback
  is a zero-copy dma-heap mmap by default (`--readback auto`); gamma + orientation
  ride along in the resolve pass, so there is no CPU postprocess.
- **`pack`** — numpy bit-plane packing (main thread).
- **`send`** — the worker thread's actual wire time (overlapped with the next render).
- **`wait`** — how long the main thread blocked on the *previous* transfer. This is
  the only part of the link that leaks into the critical path.
- **floor** — the theoretical minimum wire time for the frame at the current clock.

Diagnosis:

| Symptom | Limiter | Lever |
|---|---|---|
| `wait` ≈ 0, `render` dominates | **GPU / shader** | drop `--scale`, simplify the shader, fewer buffer passes |
| `wait` ≈ `send` | **the link** | lower `--pio-clkdiv` (faster clock), or `--transport spi` → raise `--spi-hz` |
| `pack` creeping up | **CPU packing** | scales with pixel count; vectorized already — big walls want GPU-side packing |
| fps pinned at the cap, all columns low | **`--fps` cap** | raise `--fps` (the READY handshake still self-paces) |
| Pi-side fine but wall stutters | **firmware** | check the RTT log's `rx fps (drops N)` — drops = corrupt/short frames |

The firmware telemetry (`cargo run --bin phase6-parallel` with the probe attached)
prints `rx fps` once a second — a live confirmation of what the rp2350b actually
receives and flips in.

---

## rpi5 / rayglow knobs — no reflash

### CLI flags (`python -m rayglow.render <shader> [flags]`)

| Flag | Default | What it does / when to reach for it |
|---|---|---|
| `--transport` | `pio` | `pio` = 4-lane RP1-PIO parallel bus (needs `phase6-parallel` firmware + `piobridge/libpioshim.so`). `spi` = 1-lane fallback (needs `phase5-spi`). |
| `--pio-clkdiv` | 3 | RP1-PIO clock divisor; per-lane rate ≈ 200 MHz/(2·div), so the 192 KB v2 frame floor ≈ 12 ms at div 3 (≈83 fps ceiling — above the 60 target, and the render∥send overlap hides it), 8 ms at div 2. **Lower = faster, more SI risk.** |
| `--spi-hz` | 24 MHz | SPI clock (fallback path only). Higher = more throughput, more wiring SI risk. |
| `--scale` | 2 | GPU supersample factor (1–16). 2 is the sweet spot for LED walls; 4 costs ~4× the GPU + readback for no visible gain on physical LEDs. Drop to 1 if a heavy shader still chugs. |
| `--fps` | 120 | Frame-rate cap. The link self-paces off the rp2350b's READY line; this just stops rendering frames nobody asked for. |
| `--gamma` | 1.0 | Dry-run preview gamma only. Wall runs ignore it — they bake `PACK_GAMMA` into the GPU resolve pass (or, with `--readback legacy`, into the packer's LUT). |
| `--readback` | `auto` | GPU→CPU frame path. `auto` = zero-copy dma-heap readback (falls back to `glReadPixels` off-Pi). `dmabuf-pipe` = ping-pong two buffers, reads frame N−1 while N renders — fastest, but +1 frame latency. `legacy` = the original full-size `glReadPixels` + numpy postprocess, for A/B or regression hunting. |
| `--width` / `--height` | 384 / 128 | Render size (defaults to the full wall from `config.py`). Only touch for experiments. |
| `--duration` | 0 (forever) | Stop after N seconds. |
| `--loop SECONDS` | — | Cycle every standalone `.glsl` in the shader's folder. |
| `--channel0..3`, `--no-listen` | — | Bind iChannels (audio / milk / spectrum / noise / image); `--no-listen` = synth audio only. |

### `config.py` (`rayglow/feed/config.py`) — the structural settings

| Constant | Now | Meaning |
|---|---|---|
| `PANEL_COLS` / `PANEL_ROWS` | 6 / 4 | **The geometry knobs** — the physical panel grid (24 tiles = 384×128). Everything else derives. Set `PANEL_ROWS=2` for the staged 6×2 bring-up. `PANEL_ROWS` must divide by `PARALLEL_CHAINS`. |
| `ROWS`,`COLS` | 32,64 | One panel's pixels. |
| `PARALLEL_CHAINS` | 2 | HUB75 chains — **fixed by the HAT + the u16 engine** (12 RGB bits on GP0–11). Not a knob. |
| *derived:* `CHAIN` / `CHAIN_WIDTH` | 12 / 768 | Panels **per chain** and one chain's electrical strip width. `CHAIN` **must equal firmware `PANELS_IN_CHAIN`**; `CHAIN_WIDTH` is the firmware's `W`. A chain spanning 2 panel rows serpentines, so these are *not* the wall's width — see `hub75.to_chains`. |
| `CHAIN_ORDER` / `ROW_ROTATE_180` | derived | Which panel sits where in each chain's strip, + which panel rows are mounted 180°-rotated. Generated by `config.serpentine()`; override by hand if you cable something asymmetric. Confirm on the wall with `rayglow.spi_test` (per-panel ID dots). |
| `PACK_GAMMA` | 2.1 | The CIE gamma the wall gets — baked into the **GPU resolve pass** by default (packer LUT in `--readback legacy`). Lower = brighter mids / less contrast, higher = deeper blacks. **Must stay equal to the firmware `lut.rs` gamma** so the look matches firmware-rendered demos and the byte-match golden (`tools/verify.py`). |
| `FLIP_H` / `FLIP_V` | False / False | Orientation. Flip these if you re-mount or re-cable; confirm with `rayglow.spi_test`. |
| `BITDEPTH` | 8 | BCM planes. **Must equal firmware `B`.** |
| `SINGLE_CHAIN` | False | Single-chain fallback rig (Adafruit-HAT era) — drives every panel on ONE chain via the u8 engine. Leave False on the two-chain HAT. |

> Gamma note: on the streaming path the firmware does NOT gamma-correct — it DMAs the
> pre-packed bit-planes straight to the panels. Gamma is applied entirely on the rpi5:
> by the GPU resolve pass (default — quantizes to 8 bits once, from float, so dark
> gradients come out smoother than the old 8-bit→LUT path), or by the packer's
> bit-exact `lut.rs` replica in `--readback legacy`. The firmware's own LUT only
> matters for firmware-rendered demos like `phase4-anim`.

---

## rp2350b / firmware knobs — require a reflash

Edit `firmware/src/bin/phase6_parallel.rs`, then from the `firmware/` dir:

```fish
cargo run --release --bin phase6-parallel --features two-chain   # full wall
```

| Const | Now | Meaning / tradeoff |
|---|---|---|
| `OE_GAIN` | 192 | **The brightness knob.** Scales the BCM output-enable (lit) intervals; brightness climbs ~linearly until the top plane's on-time approaches the shift time, then it starts eating refresh. 192 on the 768-wide wall = the same 72% duty (so same brightness *and* average LED current) the 256-wide wall had at 64 — see the width/brightness note below. |
| `DATA_CLK_DIV` | `(3,0)` = 25 MHz | **HUB75 pixel clock** = sysclk / (2·div). Faster = brighter + higher refresh, more SI risk down the chain. `(2,0)` = 37.5 MHz was validated clean — but only over a **4**-panel chain; the v2 wall runs 12 deep. If it glitches, *raise* the divisor: `(4,0)` = 18.8 MHz still refreshes ~153 Hz at gain 128. |
| `PANELS_IN_CHAIN` | 12 | Panels per chain; `W = 64 ×` this. **Must equal the Pi's `config.CHAIN`** (below). Also sets RAM: 32 KB per panel-per-chain double-buffered; 15 is the linkable ceiling (16 overflows 512 KB by 96 B). |
| `RX_STALL_US` | 50 ms | Ingest watchdog — a started-then-stalled frame is aborted and dropped instead of wedging the link. |
| `USE_CS` | false | CS framing reserve (needs the GP25 jumper + `--pio-cs`). READY + fixed frame size delimit frames without it. |

### Chain width vs brightness vs refresh (why `OE_GAIN` moved 64 → 192)

Per bit-plane the row SM waits on **both** the data shift (`irq 4`) and the OE lit
interval (`irq 7`), and they overlap — so a plane costs `max(shift, lit)`. Widening the
chain lengthens `shift` only, which *dilutes duty cycle*: the panel spends more of each
plane dark. Tripling 256 → 768 px drops duty 72% → 39% at a fixed gain (visibly dimmer).
Raising `OE_GAIN` buys it back by lengthening `lit`, paid for in refresh:

| Wall | `PANELS_IN_CHAIN` | `OE_GAIN` | Refresh | Duty (∝ brightness) |
|---|---|---|---|---|
| v1 256×64 | 4 | 64 | ~430 Hz | 72% |
| v2 384×128 | 12 | 64 | ~232 Hz | 39% — too dim |
| **v2 384×128** | **12** | **192** | **~143 Hz** | **72% — v1 parity** |

143 Hz is well above flicker perception (it shows up in phone video sooner than to the
eye). Same duty = same average LED current, so no thermal change. Colour is unaffected —
gain scales all planes, so the binary weighting (and thus ratios) holds.

## Geometry changes: the Pi and firmware must move together

Both sides derive the frame byte-count from the geometry, and the RX DMA waits for
**exactly** that many bytes — a mismatch desyncs the link **silently**. So a geometry
change is always a *pair* of changes. `uv run --with numpy tools/fold_check.py` prints
the `PANELS_IN_CHAIN` the Pi currently expects.

| Rig | Firmware (reflash) | Pi (`config.py`, live) | Frame |
|---|---|---|---|
| **v2 wall 6×4, two chains (production)** | `--features two-chain`, `PANELS_IN_CHAIN=12` | `PANEL_COLS=6`, `PANEL_ROWS=4` | 192 KB |
| v2 staged 6×2 (chain-length SI test) | `--features two-chain`, `PANELS_IN_CHAIN=6` | `PANEL_COLS=6`, `PANEL_ROWS=2` | 96 KB |
| v1 wall 4×2, two chains (retired) | `--features two-chain`, `PANELS_IN_CHAIN=4` | `PANEL_COLS=4`, `PANEL_ROWS=2` | 64 KB |
| Single chain, u8 engine (Adafruit-HAT era) | default features, `PANELS_IN_CHAIN=` panel count | `SINGLE_CHAIN=True` | ½ the above |

The Pi side needs no reflash — the packer sizes the payload from the frame it's handed
(`pack()` infers width; `to_chains` does the serpentine fold), and the PIO shim sizes its
DMA buffer from the first payload. The firmware side is compile-time (`W`/`H` are const
generics), hence the reflash.

---

## Quick recipes

- **Too dim** → raise `OE_GAIN` (firmware, reflash), or lower `DATA_CLK_DIV` for a
  faster, brighter clock (SI permitting).
- **Flicker / low refresh** → lower `DATA_CLK_DIV` div (faster pixel clock).
- **SI artifacts** (down-chain vertical bars, scan-half noise) → raise
  `DATA_CLK_DIV` div (slower clock); check grounding (`hardware/POWER-AND-GROUNDING.md`).
- **Heavy shader chugs** → drop `--scale` (2→1); check `render` in the stats line.
- **Want more fps** → read the stats line first (see above), then attack the actual
  limiter: `--scale` for render, `--pio-clkdiv` for the link. If `render` still
  dominates, `--readback dmabuf-pipe` hides the GPU behind the pack stage for one
  frame of added latency.
- **Colors look off** → confirm `PACK_GAMMA` matches the firmware LUT
  (`tools/verify.py` proves it); A/B against `--readback legacy` to rule the resolve
  pass in or out (expect ≤1 LSB of difference).
- **Image flipped / mirrored** → `FLIP_H` / `FLIP_V` in `config.py`.
- **Link drops / desync** (`drops` climbing in the RTT log) → raise `--pio-clkdiv`
  (slower), check the J4 lane bundle's ground return, or fall back to `--transport spi`
  to isolate.

---

## Diagnostics

- Renderer stats line — the per-stage breakdown (see "Reading the stats line").
- `python -m rayglow.spi_test [--flipv --fliph --spi-hz N]` — static test pattern
  straight through `pack → SPI → wall`, no GL (SPI fallback path; flash `phase5-spi`).
  Corner colors (white TL, red TR, green BL, blue BR) verify orientation.
- `tools/pio_ramp.py` — a known byte ramp over the parallel bus, for nibble/lane-order
  checks against the firmware's `RX_DEBUG_BYTES` dump.
- `python -m rayglow.render <shader> --dry-run` — render to a GIF headlessly, no
  hardware, to preview geometry/shader.
- Firmware RTT log (`cargo run --bin phase6-parallel ...`) prints `rx fps (drops N)` —
  live confirmation the link is locked.

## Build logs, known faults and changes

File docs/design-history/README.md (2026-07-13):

# docs/design-history/

Superseded design documents, kept for provenance. These reflect what was true when they
were written — where they disagree with the top-level README or the package docs, the
current docs win.

- **`project-milk-pi.md`** — the original handoff brief from when RayGLow was a
  from-scratch MilkDrop port. Still the best reference for the MilkDrop
  reverse-engineering and the "why from scratch" rationale; its packet spec is the v0
  ancestor of today's v1.
- **`BUILD-HISTORY.md`** — a knowledge-export brain-dump from the Pi-side build agent:
  decision log, dead ends, hardware/environment quirks (the panel-1 artifact hunt, the
  PWM solder mod, V3D/EGL behavior), calibration constants, load-bearing oddities, and a
  rough timeline. Captures what lived only in a long agent context, so it isn't lost when
  that context is. Written against the pre-restructure layout — see its header banner for
  the path remap.
- **`PROJECT-PLAN.md`** — the master plan for the RP2350 firmware + custom HAT (the
  downstream half, folded in from the former `rp2350-rgb-driver` repo): locked
  architecture decisions, the phased bring-up, GPIO pin map, and a bench-gear reality
  check. The durable design intent behind `firmware/` and `hardware/`; the code and their
  READMEs win where they've moved on.
- **`2026-07-13-optimization-paths.md`** — the render-pipeline bottleneck analysis
  (was root `optimization-paths.md`). Items 2/3/4/8 + uniform skip shipped as the GPU
  resolve pass + dma-heap zero-copy readback; measured numbers in its Status section.
  Still-open items carried into the root `ROADMAP.md`.
- **`2026-07-13-audio-feed-v3.md`** — the feed-v3 design record: Will's brief
  (verbatim), the decisions (8 flywheel bands, predictive beat tracker, 128-bin
  spectrum, key detection), and the superseded v2 packet + 13×1 texel map.

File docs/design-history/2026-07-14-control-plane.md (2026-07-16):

# Renderer control plane — the dev loop + media controls (shipped 2026-07-14)

The design record for the renderer control plane: why it exists, the decisions
taken, and what it supersedes. Current truth lives in `rayglow/render/control.py`
(server + protocol + `PlayerState`), `rayglow/render/__main__.py` (the render-thread
command drain: `switch_to` / `_advance` / `drain_commands` / `_run_command`),
`tools/rayglow_ctl.py` (the client), and `tools/control_check.py` (the wire test).

## The problem

Two overlapping pains in the shader-dev workflow:

1. **Save→wall latency was 5–20s.** The renderer already re-`stat`s the shader
   every frame (`reload.GlslWatcher`), so render-side detection is ~one frame —
   the latency was entirely **mutagen** propagating the file desktop→Pi. Tuning a
   color constant (nudge, wait, look, repeat) was miserable.
2. **No structured control** over what's playing beyond launch args and editing
   the file. Will wanted media controls (play/pause/next/prev/loop/repeat), a way
   to *force* a reload, and ideally a direct push.

This is the escalation path the old ROADMAP §2 named ("a tiny UDP/OSC control
socket … the natural HA integration point later"). §2's baseline — copy a file
over `now-playing.glsl` and let hot-reload catch it — was rejected because it
still rides mutagen and so wouldn't fix the latency.

Mental model: **mpd/mpv with an IPC socket.** Long-running renderer daemon +
control socket + a `mpc`-style client. nvim's save hook, an ssh one-liner, and any
future web/HA UI are all just clients of one protocol.

## Decisions (Will)

- **LAN TCP**, not UDP or localhost-only. Mirrors the feed's reach (the Pi listens
  on the network, desktop pushes straight to it). TCP because control is low-rate
  and reliability-sensitive — a dropped "next" or a truncated shader push is a
  bug, the opposite of the feed's lossy latest-wins stream. Lock down via firewall
  or `CONTROL_HOST=127.0.0.1` + ssh tunnel if the LAN is ever untrusted.
- **Pause = freeze the shader clock** (iTime/iFrame). The audio feed keeps running
  (decoupled clock), so a resume picks up live. A paused wall also stops
  auto-advancing. (loop = auto-advance the folder; repeat = hold current; so pause
  is free to mean "freeze the visual".)
- **Push = restart from t=0.** Every content change (push/load/next/prev/reload) is
  a uniform *full rebuild* (`build_shader`), resetting iTime/iFrame and clearing
  multipass buffers. This made all switches one code path and — as a free
  bonus — fixed §2's noted multipass gotcha (buffer siblings are rediscovered on
  every build, so a push can add/remove passes; the in-place mtime reload can't).

## The design

- **Transport / protocol** (`control.py`): a background `ControlServer` (daemon
  accept loop, per-connection handler threads) bound to `config.CONTROL_PORT`
  (5006). Framing is a 4-byte big-endian length prefix + UTF-8 JSON
  (`send_msg`/`recv_msg`) — length-prefixed so partial TCP reads reassemble, JSON
  because it's the control plane (not the frame plane): `socat`-debuggable and
  extensible (a future `brightness` cmd, per-shader settings). GLSL is text, so a
  shader rides in a JSON string field.
- **GL thread-affinity is the load-bearing constraint.** The GL context belongs to
  the render thread, so socket threads must never touch it. Every request becomes a
  `Command` on a `queue.Queue`; the render thread drains and executes it (the sole
  reader/writer of `PlayerState`, so no locks), fills the reply, and signals the
  waiting handler thread — which returns the reply (incl. compile errors) to the
  client. Latency ≤ one frame (~8ms). A bad command can never kill the loop.
- **Compile errors flow back to the client.** `build_shader(fatal=False)` now
  returns its error message; a failed `push`/`load` keeps the last good shader on
  the wall and replies `{"ok": false, "error": ...}`. The nvim hook surfaces that
  in the editor — GLSL errors no longer vanish into the Pi's stderr.
- **Live slot** (`config.LIVE_DIR`, `~/.cache/rayglow/live/`): `push` writes the
  bundle there (image + `.bufX.glsl` siblings + base64 image assets) and rebuilds
  from it — kept out of the mutagen tree so a push never fights the sync. This is
  the "tmp file that holds what's running" from Will's brief.
- **Playback state** (`PlayerState`): the folder playlist (always built, so
  next/prev/loop work without `--loop`; `--loop N` just seeds the interval), index,
  loop/repeat/pause, and the pausable shader clock. `switch_to` does the full
  rebuild + clock reset; `_advance` walks the playlist to the next compilable
  shader (shared by `--loop` auto-advance and next/prev).
- **The mtime `GlslWatcher` stays** as a cheap fallback (direct-edit-on-Pi,
  mutagen-eventual). Push is the fast path.

## Protocol (v1)

`push` (name/passes/assets), `load` (path), `next`, `prev`, `play`, `pause`,
`loop` (seconds|off), `repeat` (on|off/toggle), `reload`, `status`. Reply is
`{"ok": bool, ...}`; switch/status replies carry a player snapshot.

## Verification

- Wire contract, no hardware: `uv run tools/control_check.py` (framing round-trip,
  oversized-frame rejection, snapshot fields, the client's bundler).
- Command dispatch + a real GL switch/clock-reset were confirmed on desktop EGL.
- On the panel: `rayglow-ctl push/next/pause/loop/status` against a live renderer.

## Known limits / future

- A `../` asset path that climbs out of the shader folder won't resolve in the
  flat live slot — use `load` for those (rare). A content-hash cache could avoid
  re-sending a heavy texture atlas on every save.
- Brightness (ROADMAP §1) and per-shader settings (§2) are the natural next
  commands on this channel; HA integration is any client speaking the protocol.

## Follow-on: runtime supersample scale (2026-07-16)

Extended the plane with a `scale` command and shipped the ROADMAP §2 settings
namespace as its vehicle. `textures.parse_settings` reads `// rayglow: key=val`
comments (parallel to `// iChannelN:`); `build_shader` resolves the effective
supersample factor as **override (CLI `--scale` / runtime `scale` command) >
`// rayglow: scale=N` directive > `config.DEFAULT_SCALE`**, reading the image
source up front so the FBOs are sized before the toy is constructed. Because a
scale change is an FBO reallocation, the `scale` command just sets
`player.scale_override` and rebuilds the current shader through `switch_to` — no
new rendering path, and the override is sticky across switches until `scale
auto`. `PlayerState` gained `scale`/`scale_override` (in `status`); the nvim menu
gained `<leader>mx{1..4,a}`. This is the template for the remaining §2 settings
(gamma/fps/brightness): a `parse_settings` key + a matching command.

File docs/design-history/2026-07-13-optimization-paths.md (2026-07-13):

# GPU Render Optimization Paths — RayGLow Pi 5 Renderer

> **ARCHIVED 2026-07-13** (was `optimization-paths.md` at the repo root). The
> analysis is complete: items 2/3/4/8 and the skip-unchanged-uniforms half of 5
> shipped (see Status below). Everything still actionable is carried forward in
> the root **`ROADMAP.md`** — edit that, not this.

## Status — 2026-07-13: items 2, 3, 4, 5 (uniform skip), and 8 SHIPPED

The DMA-BUF investigation (item 2) validated on the Pi 5 and landed together with
the GPU resolve pass (items 3+4+8) and uniform-value caching (item 5's "skip
unchanged" half). Measured by `tools/dmabuf_probe.py` at scale 2, 48-iteration
plasma, 300 frames/mode:

| Path | Frame total | vs old default |
|---|---|---|
| glReadPixels + CPU postprocess (now `--readback legacy`) | 6.60 ms | — |
| dmabuf readback alone (sync) | 6.35 ms | 1.04× |
| dmabuf + GPU resolve pass (sync) — **the new default** | **2.72 ms** | **2.43×** |
| dmabuf + GPU resolve, ping-pong (`--readback dmabuf-pipe`) | 2.44 ms | 2.70× |

Key findings, for the record:

- **Why PBOs lost but dma-heaps win**: Mesa maps PBOs *uncached* on V3D, so reading
  the frame out of the mapping was slower than glReadPixels' own copy. A
  `/dev/dma_heap/system` buffer imported as a LINEAR ABGR8888 EGLImage gives a
  **cached** CPU mmap with explicit invalidation (`DMA_BUF_IOCTL_SYNC`) — V3D's TLB
  stores raster format natively, so the GPU renders straight into numpy-readable
  memory. No root needed (video group).
- **The fence wait is irreducible** — you can't read pixels that aren't rendered.
  The dmabuf alone therefore only saved the copy (~4%). The win came from pairing it
  with the resolve pass: with downsample+gamma+orientation on the GPU, the CPU has
  nothing left to do per frame but pack, and the *synchronous* path (zero added
  latency) captures nearly all of the pipelined path's gain.
- GPU resolve output matches the CPU postprocess within 1 LSB (float average + single
  quantization vs uint16 box-sum + 8-bit LUT); `tools/verify.py` still ALL GREEN —
  the wire contract didn't move. Dark-end gradients are slightly *better* now
  (gamma is applied to float values, quantized once).
- Item 8's flips folded into the resolve pass sampling coords; item 5's UBO half is
  NOT done (uniform value-caching alone cut the per-frame `glUniform*` ctypes calls
  by roughly half).

Remaining from this doc: item 1 (`--scale 1` once the resolve pass is judged on the
wall), item 5's UBO variant, items 6/7 (skipped deliberately — hot reload stays, audio
stays 120 Hz), item 9, and the GPU pack pass (below) as the next-wall prep.

## Summary

Lowering `--scale` from 4 to 1 or 2 alone reduced frame latency dramatically. The supersampled FBO (scale=4 → 1024×256) forces V3D to shade 4× the pixels and read back ~1MB per frame, all for a display that resolves to 256×64 physical LEDs. (**Since actioned: the default is now `--scale 2`.**)

This document captures the full bottleneck analysis of the render pipeline, ordered by expected impact.

---

## The Critical Path (per frame)

```
Shader render → glReadPixels → postprocess → hub75 pack → SPI transfer
```

Your timing stats (`render`, `pack`, `send`, `wait`) already give good visibility into each stage. The `render` column dominates because it includes GPU shader execution, the implicit sync fence of `glReadPixels`, and numpy postprocessing.

---

## Bottlenecks (ordered by impact)

### 1. Supersampling — The Biggest Lever

At `--scale 4`, you render a 1024×256 FBO and read back ~1MB per frame, then downsample to 256×64 on CPU. This means:

- **4× GPU fragment shader invocations** (1.05M vs 262K pixels)
- **4× glReadPixels bandwidth** (~1MB vs ~256KB)
- **Heavier numpy postprocess** over a 4× larger buffer

For an LED wall, pixel-exact rendering (`scale=1`) is visually indistinguishable — there's no sub-pixel anti-aliasing benefit since each "pixel" is a physical LED cell. Even `scale=2` cuts readback to ~500KB and GPU work by 75%.

**Action**: Use `--scale 1` or `--scale 2`. Already validated — this was the single biggest latency reduction.

### 2. `glReadPixels` — The Dominant Sync Point

`render/output.py:81-83` — reading the FBO forces an implicit GPU-CPU pipeline fence. Even with V3D's unified memory, the CPU thread blocks until rendering is complete and data is coherent. This is the single biggest remaining cost after lowering scale.

PBOs were already tried (`output.py:86-110`) and measured slower — your diagnosis of uncached mapped buffers was correct. But other approaches exist:

- **DMA-BUF / EGL image zero-copy**: Mesa on Pi supports `EGL_EXT_image_dma_buf_import`. Export the FBO texture as a DMA-BUF and memory-map it with numpy, eliminating the readback sync entirely. This is how Wayland compositors avoid stalls on V3D.
- **Render at panel resolution** (i.e., scale=1): eliminates downsample, makes `glReadPixels` return exactly the bytes you need.

### 3. Postprocess as a Shader Pass

The box-sum downsample + gamma LUT + flip (`output.py:65-75`) costs ~3-5ms of numpy work per frame. Replace it with a **downsampling shader pass**: render the supersampled FBO into a second FBO at panel resolution using a fragment shader that averages each texel block and applies gamma correction. Benefits:

- Pushes all postprocessing to V3D
- Eliminates CPU-stage entirely
- `glReadPixels` returns a contiguous (H,W,3) buffer directly
- Combines with point 4 (gamma in shader) for free

### 4. Move Gamma Correction Into the Shader

Currently gamma is applied by the packer's LUT lookup (`hub75.py:113`). The readback runs at LINEAR because the RP2350 firmware applies its own CIE LUT downstream. But if you apply gamma in the final image shader, the numpy fancy-indexing `self._lut[boxed[::-1, :, :3]]` (`output.py:74`) becomes unnecessary — it creates an intermediate array via advanced indexing.

Moving gamma to the shader also lets you combine it with the downsample pass (point 3): one shader that reads supersampled pixels, averages them, applies gamma, and outputs panel-resolution uint8. The packer then does a simpler direct bit-extraction without LUT lookup.

### 5. Uniform Update Overhead

`passes.py:206-227` — each pass issues ~15 individual `glUniform*` ctypes calls per frame. At scale=4 with multipass, that's potentially 5× as many calls. Each ctypes call has Python-side argument packing overhead on the V3D driver path.

**UBO (Uniform Buffer Object)**: Pack all uniforms into a single `GLfloat[]` array and upload once with `glBufferSubData`. GLES3 supports UBOs (`GL_UNIFORM_BUFFER`). The Shadertoy preamble would need to use an `uniform block`, but it eliminates 15 ctypes calls per pass and replaces them with one buffer update.

**Skip unchanged uniforms**: Several don't change between frames:
- `iDate` — changes once per second at most
- `iResolution` — constant for the lifetime of a shader
- Sampler indices (`iChannelN`) — constant per shader
- Only `iTime`, `iTimeDelta`, `iFrame`, and channel textures actually update each frame

Caching which uniforms changed would cut uniform uploads by ~60% on steady-state frames.

### 6. Audio Channel FFT Per Frame

`textures.py:122-135` — every frame, `AudioChannel.update()` runs an rFFT(512) + windowing + log10 + two `np.interp` calls + texture upload. At 120fps that's 120 FFTs/sec.

**Update at lower rate**: Audio doesn't change fast enough visually to need 120Hz updates. Update the audio texture at 30Hz (every 4th frame) and hold the last values. This saves 75% of FFT + interp work with no visible difference on an LED wall.

**Pre-allocate interp outputs**: `np.interp` allocates intermediate arrays each call. Pre-allocating the output buffers would avoid allocation pressure, though at 120fps this is minor compared to the FFT itself.

### 7. Hot Reload File Stat Every Frame

`render/reload.py:9-28` / `__main__.py:366` — `maybe_reload()` calls `watcher.changed()` which does `os.stat()` on every shader file each frame. At 120fps that's 120 stat syscalls/sec per tracked file (usually 2-5 files for multipass).

**Throttle to once per second**: In production, hot reload is a development convenience. A simple counter or timestamp check can reduce this to ~1 syscall/sec/file with no functional difference.

### 8. Array Copies in the Main Loop

`__main__.py:374-378` — flip operations `buf[::-1]` and `buf[:, ::-1]` create views (cheap), but `np.ascontiguousarray(buf)` forces a full copy of the frame (~49KB for 256×64×3). If flips are enabled, that's an extra allocation + memcpy per frame.

**Make readback output correct orientation**: Flip in the shader (invert Y in the epilogue) or in the downsample pass so `glReadPixels` returns data already oriented correctly. Eliminates both the flip and contiguification step.

### 9. Single-Chain Fold Loop

`hub75.py:207-211` — if using single-chain mode, the serpentine fold iterates in a Python for-loop over panels. For a 6-panel rig this is negligible (~0.1ms), but worth noting if you scale up. A vectorized numpy approach (pre-computed index array with advanced indexing) would eliminate the loop.

---

## Quick Wins (Low Effort, Good Impact)

| Change | Effort | Expected Benefit |
|---|---|---|
| `--scale 1` or `2` | Trivial | Already validated — large latency reduction |
| Throttle audio texture to 30Hz | Low (~5 lines) | Saves FFT + interp on 75% of frames |
| Disable hot reload in production | Low (flag or counter) | Eliminates stat syscalls at 120fps |

## Medium Effort, Good Impact

| Change | Effort | Expected Benefit |
|---|---|---|
| Downsample shader pass | Medium (new GLSL + FBO) | Eliminates CPU postprocess stage entirely |
| Gamma in final shader | Low-Medium (preamble change) | Simplifies packer, combines with downsample |
| Skip unchanged uniforms | Medium (tracking logic) | Cuts uniform uploads ~60% per frame |

## High Effort, Potentially Transformative

| Change | Effort | Expected Benefit |
|---|---|---|
| DMA-BUF zero-copy readback | High (EGL extension + mmap) | Removes the `glReadPixels` sync fence entirely |
| UBO for all uniforms | Medium-High (preamble + ctypes) | Single buffer upload replaces 15+ ctypes calls per pass |

---

## Scaling to the next wall (512×128 or 384×96, p4) — 2026-07-13 audit

Where each stage lands at 4× / 2.25× today's pixel count:

| Stage | 256×64 today | 384×96 | 512×128 | Verdict |
|---|---|---|---|---|
| GPU shade (scale 2) | 512×128 px | 768×192 | 1024×256 | 512×128@scale2 = today's scale-4 area — heavy shaders will hurt; scale 1 may become the default there |
| Readback (RGBA, scale 2) | 256 KB | 576 KB | 1 MB | the sync fence grows linearly — this is what makes the GPU pack pass (below) matter |
| numpy pack | 64 KB out | 144 KB | 256 KB | ~linear in pixels; ~4× today's `pack` ms at 512×128 |
| Link (4-lane @ clkdiv 3, 33 MB/s) | 2.0 ms | 4.4 ms | 7.7 ms | fine (overlapped); clkdiv 2 = 50 MB/s halves it if the HAT's SI allows |
| RP2350 refresh (25 MHz px clk, 2 chains) | ~680 Hz | ~340 Hz | ~190 Hz | fine; 37.5 MHz buys ~1.5× |
| **RP2350 SRAM (520 KB total)** | 128 KB (2× 64 KB fb) | **288 KB — fits** | **512 KB — does NOT fit** | **the hard ceiling.** fb bytes = wall_px/2 × B, double-buffered |

So: **384×96 runs on the current RP2350 rig unchanged** (bigger consts, generalized
serpentine fold for 3 panel-rows on 2 chains). **512×128 does not fit** at 8-bit BCM
double-buffered — the outs are B=6 (384 KB, visible banding risk in the low end),
single-buffering (tear/race risk), or the FPGA translator (ULX3S/ECP5 with real RAM) —
which was the plan anyway. PSRAM on the RP2350B is not a real out: the scan-out DMA
needs jitter-free ~50 MB/s continuous reads that QSPI PSRAM can't guarantee.

### The one big Pi-side lever left: pack on the GPU

Combine items 3+4 above and go further — a final "pack pass" fragment shader (GLES 3.1
integer ops) that box-averages the supersampled texture, applies the CIE LUT via a
256-entry `usampler2D` texelFetch (bit-exact vs `lut.rs`), extracts the BCM planes, and
writes the u16 cells straight into an RGBA8 target whose bytes ARE the wire stream
(fold the PIO nibble-swap in for free). `glReadPixels` then returns the 64 KB payload
directly:

- readback shrinks 4× (scale 2) — 1 MB → 256 KB on the 512×128 wall
- the entire numpy postprocess + pack stage disappears (`pack` → ~0)
- verification story survives: extend `tools/verify.py` to diff the GPU pack against
  `hub75.pack` on random frames

This is the prep work that makes 512×128 viable on the Pi 5 side.

- **Box-sum integer downsample** (`output.py:70-71`): Replacing float `.mean()` (~13ms at scale=4) with uint16 box-sum + LUT was a great call — ~10× faster.
- **SendPipe overlap** (`__main__.py:228-285`): The depth-1 pipeline that overlaps SPI transfer with GPU rendering is well-designed. If `wait` hugs 0 in your stats, the link is fully hidden behind render.
- **PBO correctly disabled**: Your analysis of why PBOs are slower on V3D (unified memory = no bus stall to hide, uncached mapped buffer) was spot-on.
- **Thread pinning** (`__main__.py:60-67`): Pinning the render thread and letting the send worker float is the right approach for Pi 5's big.LITTLE cores.

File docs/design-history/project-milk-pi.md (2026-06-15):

> **⚠️ HISTORICAL DESIGN RECORD — superseded.** This is the original project
> handoff brief, from when RayGLow was a from-scratch MilkDrop port. It is kept for
> provenance: the MilkDrop reverse-engineering (§2) and the rationale for building from
> scratch (§3) are still the best reference for those. But the architecture has since
> moved on — the renderer is now GLSL (`rayglow.render`), not the feedback-buffer core
> described in §4; that core is retired in `rayglow/legacy/`. The §5 packet spec
> documents the **v0** ancestor (the live protocol is **v1**, 564 bytes — see
> `sender/README.md`). Where this disagrees with the top-level README / package docs,
> the README wins.

# Project Milk-Pi

MilkDrop-style audio-reactive visualizations, rebuilt from scratch, rendered on an RGB LED
matrix. Audio plays on the desktop; the Pi only renders.

This document started as a handoff brief from `desktop` (written after getting
MilkDrop3 running under Wine and studying its source — `code/` in this repo:
https://github.com/milkdrop2077/MilkDrop3) and is now the shared project record. Both
machines keep a copy: `~/Projects/MilkDrop3/project-milk-pi.md` (desktop) and
`~/rpi-rgb-led-matrix/MilkDrop3/project-milk-pi.md` (Pi). **STATUS: working end-to-end on
the panel with real music (June 2026).**

---

## 1. System architecture

```
desktop (192.168.0.10, CachyOS, PipeWire)          raspberry pi 4b (192.168.0.50)
┌─────────────────────────────────────────┐        ┌──────────────────────────────┐
│ music playback ──▶ sink monitor source  │        │  UDP listener (latest-wins)  │
│        │                                │  UDP   │        │                     │
│  feature daemon: capture → FFT →        │ ─────▶ │  renderer: feedback-buffer   │
│  bass/mid/treb (+_att) + waveform       │ :5005  │  core loop (NumPy/OpenCV)    │
│  → 556-byte packet, unicast, ~60 Hz     │        │        │                     │
└─────────────────────────────────────────┘        │  hzeller rpi-rgb-led-matrix  │
                                                   │  4x 64x32 P6 HUB75 = 256×32  │
                                                   └──────────────────────────────┘
```

Division of labor:
- **Desktop daemon** (`~/Projects/milk-pi/sender.py`, uv project): captures the PipeWire
  monitor source, extracts audio features, blasts UDP. Negligible CPU cost there (~1.7%).
- **Pi renderer** (`~/rpi-rgb-led-matrix/rpi-custom/milk/`): receives features, runs
  the visualization core loop, drives the matrix. The Pi is already heavily loaded
  bit-banging HUB75 via the hzeller library (with hardware mods), so it does **zero audio
  work** — no capture, no FFT.

Why features instead of streaming PCM: drift and jitter only matter when reconstructing a
continuous signal. Features are **stateless per frame** — no ring buffer, no clock-drift
resampling, no jitter buffer. Lost/late packet → render with the previous values; at 60 Hz
one held frame is invisible. UDP used the way UDP wants to be used.

Network notes: **unicast** to the Pi's IP (multicast across VLANs needs IGMP/mcast-routing
cooperation from the Cisco 3850 + OPNsense — not worth it for one receiver). Desktop→Pi
UDP 5005 crosses the User→IoT VLAN boundary with no extra firewall rule (verified).

---

## 2. How MilkDrop actually works (codebase findings)

Source layout (`code/`):
- `audio/` — WASAPI loopback capture (Windows-only, irrelevant to us, but the *interface*
  it feeds is the spec for our packet)
- `ns-eel2/` — Nullsoft Expression Evaluator: preset equations are JIT-compiled to native
  x86 at preset load (`nseel-compiler.c`). Preset "code" is control logic, not drawing.
- `vis_milk2/milkdropfs.cpp` — essentially the entire renderer. The one file to study.

### The mental model

MilkDrop is a **feedback loop on a framebuffer** (an IIR filter on the image):

```
prev_frame ─▶ warp (resample through displacement field) ─▶ decay ─▶ draw audio geometry ─▶ next_frame
                                                                            │
                                                              composite pass ─▶ display
```

Frame N's output is frame N+1's input texture. Trails, tunnels, fractal zooms, smears are
all emergent from this loop. Preset code never touches pixels — it steers ~10 scalars.

### Audio interface (the spec for our packet)

`vis_milk2/plugin.h:61`: 576-sample PCM windows, 2 channels. FFT'd, then collapsed to
**three band energies**. Set into preset variables at `vis_milk2/milkdropfs.cpp:483`:

- `bass`, `mid`, `treb` — instantaneous band energy **normalized by its own running
  average** (`imm_rel`): 1.0 = "typical for this song right now". This auto-gain is why
  presets work across genres/volumes. Ported exactly (plugin.cpp:8750) in both
  `fake_sender.py` and `sender.py`.
- `bass_att`, `mid_att`, `treb_att` — temporally smoothed versions (`avg_rel`).
- Plus `time`, `frame`, `fps`. That is the **entire** audio→preset interface: six scalars.

The raw waveform is used in exactly one other place: drawn directly as a polyline
(`DrawWave(mysound.fWave[0], mysound.fWave[1])`, `milkdropfs.cpp:1056`).

Exact analysis chain (ported in `sender.py`, validated with sine tones): 576 left-channel
samples → Hann envelope (`fft.cpp` InitEnvelopeTable, power=1) → zero-padded 1024-pt FFT →
512 magnitude bins × log equalize table (`-0.02*ln((512-i)/512)`) → three equal LINEAR
thirds of the bottom half (`plugin.cpp:8736`): bins [0:85], [85:170], [170:256] ≙
0–4 / 4–8 / 8–12 kHz at 48 kHz. (fft.cpp's comments recommend octave bands; the actual
code never uses them. We replicate the code, not the comment. Beware `myfft.Init(576,
512, -1)` — the `-1` lands on `bEqualize`, which is truthy, so equalize is ON.)

### Render pass order (`milkdropfs.cpp:751`, `RenderFrame`)

1. Run per-frame equations (`:873`) — audio vars in; `zoom, rot, dx, dy, cx, cy, sx, sy,
   warp, decay, wave_*` out. `q1..q32` carry values from per-frame code to per-vertex code.
2. Motion vectors overlay (`:965`) — optional.
3. **WarpedBlit** (`:1013`) — the heart. Previous frame rendered through a coarse mesh
   (up to 192×144, `md_defines.h:49`; typically ~48×36). The "per_pixel" equations are a
   historical lie — they run **per mesh vertex** (`:1750`), computing where each vertex
   *samples from* in the old frame: zoom = radial UV scale about (cx,cy), rot rotates UVs,
   dx/dy translate, warp adds drunken-sine displacement (`:1797-1812`; four incommensurate
   cosines with magic constants at `:1702` — `11.68, 8.77, 10.54, 11.49` — so the wobble
   never visibly repeats). GPU bilinear interpolation fills between vertices. The mesh
   exists only because 2001 GPUs couldn't afford per-pixel math.
4. Geometry injection (`:1054-1057`) — custom shapes, custom waves, the basic PCM
   waveform polyline, sprites. This is where audio energy enters the feedback loop.
5. **Composite pass** (`ShowToUser`, `:1081`) — gamma, video echo, hue shift. Outside the
   feedback loop: beautifies, doesn't accumulate.
6. Texture swap; next frame.

### Preset files

`.milk` files are INI format. Relevant blocks: scalar defaults, `per_frame_N=` lines,
`per_pixel_N=` lines (per-vertex), wave/shape sections. Presets with `warp_1=`/`comp_1=`
HLSL shader blocks are arbitrary GPU programs — the shader *cannot* be replicated by this
architecture, but (June 2026 finding, from running the dotmilk transpiler against a 311-
preset library): the *equations* of shader-era presets still drive the motion faithfully;
what's lost is shader-side *coloring*. Presets whose only light source is the shader
render dark and get triaged out — ~60% of the library survives at the user-approved bar.

---

## 3. Why from scratch (vs. frame capture or projectM)

Considered and rejected for the primary path:
- **Window/frame capture + PIL downscale**: works, but the Pi/desktop split gets ugly
  (capture on desktop → now you're streaming video, 100x the bandwidth and latency
  machinery), and it teaches nothing.
- **projectM** (open-source MilkDrop reimpl, GLES, runs on a Pi natively; people have piped
  it to hzeller matrices): pragmatic fallback if from-scratch stalls, and the only route to
  full shader-era preset fidelity. But the Pi is already CPU/timing-constrained from HUB75
  bit-banging, and GL-render-then-readback adds contention.

From scratch won because the core is **unusually tractable**: at matrix resolution
(256×32 = 8k px) true per-pixel displacement is affordable in vectorized NumPy /
`cv2.remap` — the mesh trick is skipped entirely (per_pixel runs truly per pixel). The
interesting motion is low-frequency by construction (it had to survive mesh interpolation),
so almost nothing is lost at LED resolution. What *does* die at P6 pitch: fine waveform
detail — fatter lines, fewer points than the original 576.

---

## 4. Pi-side renderer framework (as built — kept as design reference)

Core loop (Python + NumPy + OpenCV):

1. `buf`: float32 array, H×W×3. Geometry from `milk/config.py` (single source of truth;
   `CHAIN=4` is the one knob if panel 5 returns).
2. Each frame:
   a. Read newest feature packet (nonblocking, latest-wins, see §5). No packet for 0.5 s →
      synth fallback (gentle ~1.0-hovering LFOs) so the display never freezes.
   b. Update steering parameters (zoom/rot/dx/dy/warp/decay/wave color...) from features.
   c. `cv2.remap(buf, map_x, map_y, INTER_LINEAR)` — the warp, with params-hash caching
      of coordinate grids (`milk/warp.py` is a faithful per-pixel port of
      `milkdropfs.cpp:1698-1837` including the exact warp constants).
   d. `buf *= decay`; optional darken-center, borders.
   e. Draw waveform/shapes from packet's wave data.
   f. **`buf.clamp()` after the draw stage** — load-bearing: MilkDrop's 8-bit feedback
      texture implicitly clamped at 1.0 every frame; without it, waveform pixels
      equilibrate at brightness/(1−decay). The source never states this property.
   g. Tone-map to uint8 (`--gamma`, default 1.2), push via hzeller, keep float buf.
3. Performance: hzeller's GPIO thread owns core 3; render pinned to core 0
   (`config.RENDER_CORE`). Headless: ~440 fps tunnel / ~290 fps wobble at 256×32 — huge
   headroom over 60.

Structure mirrors MilkDrop's host/preset split: engine (buffer, warp, draw, matrix out) vs
presets. Two kinds of presets:
- Hand-written: `milk/presets/tunnel.py`, `wobble.py` — fn(FeatureState) → steering dict;
  tunables grouped at top (DECAY, ZOOM_BASS, HUE_SPEED…).
- **Real .milk: `milk/dotmilk/`** — .milk parser + full NS-EEL→NumPy transpiler
  (loop/while/megabuf/gmem/`x[i]` memory syntax; 311/311 of
  `milk/presets/dotmilk-presets/` transpile) + MilkPreset runtime (per_frame scalar,
  per_pixel truly per-pixel vectorized — no mesh), main-wave modes 0–7, custom waves
  (vectorized w/ auto-fallback to sequential for cross-point accumulators), custom shapes
  (vectorized instances, textured = affine feedback resample), borders, darken-center.
  8:1 aspect caveat: custom-wave canvas squashed-to-fit via `config.WAVE_FIT`
  (1.0 fit / 0.0 faithful-crop).

Run (on the Pi):
- Playlist: `sudo ~/venv/bin/python -m milk --milk <dir|keepers.txt> [--duration N]
  [--shuffle]` — keys n/p/space/r/q; presets preloaded pre-privilege-drop.
- Hand-written: `sudo ~/venv/bin/python -m milk --preset tunnel`
- Triage a preset library: `python -m milk.dotmilk.triage <dir> -o <out>` → grades every
  preset (sheets + report + keepers.txt).

---

## 5. Feature packet — DRAFT v0 (in production; bump to v1 only if layout changes)

Both ends of this contract exist and interoperate: `sender.py` (desktop, real audio) and
`milk/receiver.py` (Pi; 556-byte size asserted at import, seq-wrap handled).
`milk/fake_sender.py` remains the music-free test harness — same struct, synthesized
features, MilkDrop-exact AutoGain.

Unicast UDP, one packet per tick at ~60 Hz, little-endian, fixed layout:

```
offset  type        field
0       uint32      magic = 0x4D494C4B ("MILK")
4       uint16      version = 0
6       uint16      flags (reserved)
8       uint32      seq            (wraps; receiver drops stale/reordered)
12      float32     t              (sender monotonic seconds)
16      float32     bass           (imm_rel-style: normalized by running avg)
20      float32     mid
24      float32     treb
28      float32     bass_att       (smoothed)
32      float32     mid_att
36      float32     treb_att
40      float32     vol            (overall, normalized)
44      float32[128] wave          (mono waveform window, downsampled from 576, ±1.0)
556     = total bytes
```

~33 KB/s at 60 Hz. Receiver rules: bind, `recvfrom` nonblocking each frame, drain the
socket keeping only the highest `seq`, render with it; if nothing new, render with previous
values (do NOT block the render loop on the network).

Auto-gain semantics (defined by `AutoGain` in both senders, ported from plugin.cpp:8750):
per band, `imm_rel = imm/long_avg` (long_avg retention 0.992 @30fps-equivalent after a
50-frame fast-converge at 0.9), `avg_rel = avg/long_avg` (avg attack 0.2 rising / 0.5
falling). Values hover ~1.0, spike on hits.

---

## 6. Latency budget (audio-out → photon)

| Stage | Cost |
|---|---|
| PipeWire capture quantum (desktop) | 5–10 ms (tunable, `PIPEWIRE_LATENCY=256/48000`) |
| FFT window | ~12 ms — inherent measurement window (MilkDrop uses 576 @ 44.1k too) |
| UDP, LAN | <1 ms wired; WiFi OK in practice (see §7) |
| Pi render + hzeller refresh | 2–10 ms |
| **Total** | **~15–25 ms** — beat-sync stays tight under ~40–50 ms |

The network is the cheapest line item. The war is won in capture quantum and render rate.

---

## 7. Resolved facts & shelved plans

- Geometry: **4 panels chained = 256×32** (`CHAIN=4` in `milk/config.py` is the one knob
  if panel 5 returns). Pi headless perf: ~440 fps tunnel / ~290 wobble.
- Pi: **192.168.0.50** (IoT VLAN, WiFi, DHCP — consider a dnsmasq reservation since
  sender.py defaults to this IP), UDP port **5005**. Desktop→Pi UDP 5005 crosses VLANs
  with no OPNsense rule needed (verified via ICMP-unreachable probe).
- Pi code: `/rpi-rgb-led-matrix/rpi-custom/milk/` (mounted on desktop at
  `~/pi-mount/`).
- Preset library: `milk/presets/dotmilk-presets/` (311 presets; the MilkDrop3 repo clone
  ships none — the desktop Wine install has the full set at
  `~/.wine-milkdrop3/drive_c/users/will/Desktop/MilkDrop 3.31/Milkdrop3/presets/`).

**Latency hardening — SHELVED (June 2026).** End-to-end feels tight in practice; the
4–250 ms idle ping variance is WiFi power-save doze (packets buffer at the AP between DTIM
beacons), and the 60 Hz stream keeps the radio awake during actual use. Evaluated and
rejected: **BLE** (267 kbps stream vs BLE's practical BlueZ throughput; 7.5–50 ms
connection-interval latency floor; 556 B > ATT MTU → fragmentation; Pi 4's CYW43455 shares
one antenna between WiFi and BT — coexistence makes both worse). If/when revisited, in
order:
1. **Free:** disable WiFi power-save on the Pi — `sudo iw dev wlan0 set power_save off`;
   persist via `nmcli con mod <wifi-con> 802-11-wireless.powersave 2` (Bookworm/NM).
2. **Clean:** point-to-point Ethernet. desktop has an idle dual-port Intel X540
   10GBASE-T (`enp132s0f0/f1`); 10GBASE-T autonegotiates down to the Pi's 1GbE. One 5-ft
   cable, private /30, **no switch port, no VLAN, no OPNsense changes** — the subnet
   exists only on the wire: desktop `nmcli con add type ethernet ifname enp132s0f0
   con-name milk-ptp ipv4.method manual ipv4.addresses 10.10.0.1/30`; Pi eth0 static
   10.10.0.2/30 (no gateway → no routing ambiguity, WiFi stays for management); then
   `sender.py --host 10.10.0.2`.

## 8. Status

- [x] MilkDrop3 running on desktop (Wine, dedicated prefix `~/.wine-milkdrop3`,
      `milkdrop3` launcher) — reference visuals live
- [x] Pipeline reverse-engineered (this doc)
- [x] Pi: renderer framework + fake-sender harness — built & verified headless
- [x] Desktop: feature daemon — `~/Projects/milk-pi/sender.py` (uv project). Faithful FFT
      front-end + AutoGain (see §2); band split validated with 110 Hz/6 kHz/10 kHz tones;
      auto-targets monitor of default sink (`--source` to override). Run:
      `cd ~/Projects/milk-pi && uv run sender.py` (defaults to 192.168.0.50:5005).
- [x] **End-to-end on the panel with real music — working (June 2026), first try**
- [x] Real .milk presets — dotmilk parser/transpiler/runtime + triage (see §4)
- [ ] Packet v1 — only if the v0 layout ever needs changing (wave stereo/length)
- [ ] (shelved) Latency hardening — worked plan in §7

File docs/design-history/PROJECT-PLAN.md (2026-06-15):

# RP2350 HUB75 RGB-Matrix Driver — Project Plan

> Staging-area plan for a ground-up firmware + custom-PCB build that drives **8× 64×32 HUB75 panels (256×64 total)** from a **Raspberry Pi RP2350**, fed frames by a Raspberry Pi 5. This document is the entry point for an implementation agent. Read it top to bottom, then read the reference material called out in §12 before writing code.

---

## 1. Context & goal

The author currently drives an RGB LED display from a Raspberry Pi using the `hzeller/rpi-rgb-led-matrix` library (a copy is in `reference-repositories/rpi-rgb-led-matrix/` for reference) with a custom GLSL shader generating frames. The pain point is timing jitter: a Linux SoC bit-banging GPIO fights the scheduler, needs a dedicated RT core, and the Pi 5's RP1 southbridge made it worse.

**The new architecture splits render from scan-out:**

```
  Raspberry Pi 5                         RP2350 (this project)
 ┌────────────────┐   frames (SPI)     ┌──────────────────────────┐
 │ GLSL shader →  │ ─────────────────► │ ingest → bit-plane pack → │ ──► HUB75 ──► 8 panels
 │ RGB framebuffer│   ~1.5–3 MB/s      │ PIO + DMA scan-out (0 CPU)│      (256×64)
 └────────────────┘                    └──────────────────────────┘
```

The RP2350 runs a deterministic PIO state-machine + DMA engine that pushes pixels to the panels with cycle-exact timing and **zero CPU involvement in the refresh loop**, leaving both cores free to ingest frames from the Pi 5. This is the whole point of the redesign — do not adopt any approach that puts the CPU back in the per-plane refresh loop.

**Primary goals**
- Drive **256×64** (two rows of four 64×32 panels) at **≥30 fps content, flicker-free (≥150 Hz refresh)**.
- Match or exceed current color quality: **CIE1931-corrected, target 8-bit now → 11-bit later** per channel.
- Custom PCB to interface the dev board to the panels, with **four HUB75 connectors** for headroom/upgradability.
- Clean, transparent, well-understood design (the author values learning the *why*, not black boxes).

**Out of scope for the first milestones (but reserve the design):** the Pi 5 → RP2350 link. Build the scan-out engine first against a locally generated test pattern, then add the link (§10).

---

## 2. Confirmed decisions (do not re-litigate)

| Decision | Choice | Rationale |
|---|---|---|
| Architecture base | **kjagiello `hub75-pio-rs`** (Rust, rp2040-hal) | 3-SM split with a dedicated PIO-timed OE/BCM engine + self-chaining DMA = genuinely zero-CPU refresh; cleanest BCM; scales to high bit depth. The hard, easy-to-get-wrong part is done right. |
| Multi-channel reference | **pitschu `RP2040matrix-v2`** | Its V2/`8080` layout already drives **two HUB75 channels in parallel** packed into one PIO word — the exact mechanism we extend. Also a good template for full-frame→bit-plane repack. |
| Language / stack | **Rust** (`rp235x-hal`) | Continuation of kjagiello; author is growing in Rust and values the type safety. Accept the nightly toolchain cost (§7, §11). |
| MCU | **RP2350B** via **Waveshare RP2350-PiZero** dev board | Pi-Zero form factor suits the 2-row panel layout; 48 GPIO leaves ~25 spare for future chains C/D (→ 16 panels). |
| Display topology | **2 parallel chains × 4 panels** (256×64) | Confirmed comfortable on RP2350 (see §4). Two rows = two chains, one chain per row. |
| Custom PCB role | **HAT/carrier on top of the dev board** | Dev board provides power/crystal/flash/USB; the PCB only does level-shifting + connectors + panel power (§9). Greatly reduces board complexity. |
| Bit depth | Start **8-bit**, design buffers/PIO to scale to **11-bit** | Matches current pipeline; RP2350 SRAM has the room. |
| Pi 5 link transport | **SPI** (deferred) | RP2350 USB is Full-Speed only (~1.5 MB/s) — insufficient for 256×64×3×30 fps. SPI at 25–50 MHz is ample (§10). |

---

## 3. Hardware target — RP2350 / RP2350-PiZero

From the datasheets in `reference-documents/`:

- **RP2350B**, QFN-80, **48 GPIO** (GPIO0–47). Dual Cortex-M33 + dual Hazard3 RISC-V @ **150 MHz** (overclockable). IO fixed/typical **3.3 V**.
- **520 KB SRAM** in 10 banks; **3 PIO blocks / 12 state machines** (32 instructions per SM); **16 DMA channels** *(verify exact count in `rp235x-pac`)*.
- **RP2350-PiZero** (schematic: `reference-documents/RP2350-PiZero.pdf`): onboard DVI/HDMI consumes **GPIO32–39**, SD card uses **GPIO30–31, 40–46**, USB-C, QSPI flash. The 40-pin header breaks out **GPIO0–21+**. We will not use the onboard HDMI/SD, so those GPIO are irrelevant; **GPIO0–18 (our 19 signals) are available and contiguous** — confirm exact header pin↔GPIO mapping against the schematic before routing the PCB (§9, §11).

**RP2350-specific gotchas the agent must handle:**
1. **Boot image block.** RP2350 binaries require an embedded `IMAGE_DEF` block (not the RP2040 `boot2`). `rp235x-hal` provides this via a `#[link_section = ".start_block"]` `hal::block::ImageDef` (or embassy's equivalent). Get a blink working first to prove the boot/flash path.
2. **GPIO erratum (RP2350 E9):** input-mode pads can latch high via the internal pull. Irrelevant for our outputs (we drive '245 inputs), but relevant later for the **SPI link's input pins** — use external pulls / follow the erratum workaround there.
3. PIO on RP2350 is a superset of RP2040's; kjagiello's PIO programs port largely unchanged.

---

## 4. Display topology & feasibility (the "why", so it isn't hand-waved)

**Layout:** two rows × four 64×32 panels = **256 W × 64 H**. Wired as **two parallel chains**, each chain = four panels daisy-chained = **256 W × 32 H, 1/16 scan** *(confirm panel scan rate — 64×32 is usually 1/16 → 4 address lines A–D; some are 1/8. See §11)*.

- **Chain A** = top row, **Chain B** = bottom row.
- **Shared** across both chains: CLK, LATCH, OE, address lines A–D.
- **Per-chain:** R1,G1,B1,R2,G2,B2 — **confirmed:** each panel is a single HUB75 connector whose two RGB triplets independently feed the panel's top half (R1G1B1, rows 0–15) and bottom half (R2G2B2, rows 16–31), clocked together. This is exactly what kjagiello's `XXBGRBGR` framebuffer tuple packs, so no change is needed.
- Both chains are clocked **simultaneously** by one data SM; the framebuffer word carries both chains' RGB bits. Parallel chains cost nothing in refresh time — that's the key lever.

**Pin budget:** 12 RGB (2×6) + CLK + LATCH + OE + 4 address = **19 GPIO**.

**Memory** (RP2350 = 520 KB): one packed word per (column × address-row × bit-plane), holding both chains' 12 RGB bits.
- words = 256 cols × 16 addr × `B` planes = `4096·B`.
- 8-bit, double-buffered: ≈ **128 KB** (32-bit words) / 64 KB (16-bit words).
- 11-bit, double-buffered: ≈ **176 KB**. Comfortable; 16-bit would still fit.

**Refresh:** kjagiello measures ~**2100 Hz @ 24-bit on a 64-wide** panel. Per-chain width here is 256 (4×) → shift time 4× → ~**525 Hz @ 24-bit**, far higher at 8–11 bit. Need >~150 Hz for flicker-free + 30–60 Hz content. **Large margin.** Conclusion: 2 chains × 4 panels is the comfortable design point, not a compromise.

**Pixel clock:** kjagiello runs the data SM at `clkdiv (2,0)` (sys/2 = 75 MHz instr, 2 instr/pixel → 37.5 MHz pixel). Over four daisy-chained panels through '245 buffers and a backplane, that is likely too fast. **Plan to tune `clkdiv` for a ~20–25 MHz pixel clock and validate signal integrity on hardware** (the refresh budget above easily absorbs the slower clock).

---

## 5. Firmware architecture

Adopt kjagiello's three-state-machine model **unchanged in structure**; widen only the data path.

### 5.1 PIO state-machine allocation (use PIO0; PIO1/PIO2 reserved for the SPI link later)
- **Data SM** — clocks RGB out + drives CLK (sideset). *Modification:* `out pins, 12` (two chains' RGB) instead of `out pins, 8`. (Reference `hub75-pio-rs/src/lib.rs:230-265`.)
- **Row SM** — sets the 4 address lines, pulses LATCH, and choreographs timing via IRQ handshakes with the data and OE SMs. Largely unchanged. (`lib.rs:267-309`.)
- **OE SM** — generates binary-weighted display intervals by consuming a tiny `delays[]` array (`(1<<i)-1` ticks per plane) streamed by its own DMA channel. **This is the BCM engine — keep it as-is.** It is agnostic to data-path width. (`lib.rs:50-58`, `:311-333`.)

### 5.2 DMA
Keep kjagiello's **four-channel design with two self-retriggering loop channels** (`chain_to` ping-pong) so refresh runs forever with zero CPU: framebuffer-feed + framebuffer-loop, OE-feed + OE-loop. (`lib.rs:335-492`.) Port the direct register pokes in `hub75-pio-rs/src/dma.rs` to the **`rp235x-pac`** register layout; verify DMA channel/register differences vs RP2040.

### 5.3 Framebuffer memory layout (the main change from kjagiello)
kjagiello packs **1 byte per (column, plane, addr)** holding one chain's 6 bits (`XXBGRBGR`). We need **two chains = 12 bits**, so widen the cell:
- Use a **16-bit (or 32-bit) packed word** per (column, plane, addr): `[chainB: B2 G2 R2 B1 G1 R1][chainA: B2 G2 R2 B1 G1 R1]`, with the bit order matching the data SM's `out pins, 12` GPIO mapping (chain A on GP0–5, chain B on GP6–11).
- Borrow the packing pattern from pitschu's two-channel `8080` repack: `RP2040matrix-v2/hub75_BCM.c:461-505` shows exactly how to fold two channels' per-bit values into one word. Adapt it to kjagiello's plane-major buffer layout (`lib.rs:60-121` documents that layout).
- Keep kjagiello **double-buffering** + `commit()` on buffer flip (`lib.rs:516-529`).

### 5.4 Frame ingest — replace the per-pixel API
kjagiello exposes a per-pixel `embedded-graphics` `DrawTarget`/`set_pixel` (`lib.rs:534-561`). At 16384 px × ≥30 fps that is far too slow and the wrong shape for streaming. **Replace it with a bulk repack**: take a whole RGB frame (RGB888 or RGB565) and expand it to all bit-planes in one pass — pitschu's `hub75_update()` (`hub75_BCM.c:419-515`) is the template. Pin this repack to **core 1** so core 0 can service the SPI/USB link; or use DMA/interpolator assist. Keep the **CIE1931 gamma LUT** (kjagiello `src/lut.rs`) to preserve current color quality.

### 5.5 Coordinate mapping
Author intends a fixed **2 rows × 4 cols** arrangement, but keep the logical-pixel `(x,y)` → (chain, panel, column, half) mapping **table/param-driven** so panel order, chain assignment, and serpentine vs. progressive wiring can change without touching the PIO. This mirrors the "pixel mapper" concept in `rpi-rgb-led-matrix` (`lib/pixel-mapper.cc`) — a good reference for the mapping math.

---

## 6. GPIO / pin map (verified against RP2350-PiZero header)

kjagiello requires the RGB group and the address group each be **electrically consecutive** GPIO (PIO `out pins` drives consecutive GPIO from a base). The RP2350-PiZero 40-pin header is **confirmed to use standard Raspberry Pi BCM numbering** (verified: physical pin 12 = GPIO18). All of RP2350 GP0–27 are broken out; onboard HDMI/SD use GP30+ and don't conflict.

| Signal | RP2350 GPIO | Header pin (Pi BCM) | Notes |
|---|---|---|---|
| Chain A: R1 G1 B1 R2 G2 B2 | GP0–GP5 | 27, 28, 3, 5, 7, 29 | data SM `out pins` base = GP0 |
| Chain B: R1 G1 B1 R2 G2 B2 | GP6–GP11 | 31, 26, 24, 21, 19, 23 | `out pins, 12` spans GP0–11 |
| Address A B C D | GP12–GP15 | 32, 33, 8, 10 | row SM `out pins, 4` (1/16 scan, 4 lines) |
| CLK | GP16 | 36 | data SM sideset |
| LATCH | GP17 | 11 | row SM sideset |
| OE | GP18 | 12 | OE SM sideset |

19 pins, GP0–GP18, all present on the header. **Routing reality:** BCM numbering makes these electrically contiguous (ideal for PIO) but **physically scattered** across the header — the HAT fan-out to the '245s is a 2-layer routing job, not a tidy row. Reserve GP19–GP21 (header pins 35, 38, 40) for chains C/D RGB if a 16-panel future is wanted; reserve a separate contiguous group for the SPI link (§10). If a different electrically-contiguous base eases routing, it can be reassigned freely — only the *consecutiveness* matters to the PIO, not the specific base.

---

## 7. Toolchain & build

- **Rust nightly** (kjagiello uses `#![feature(generic_const_exprs)]`, `const_for]`). Pin a known-good nightly in `rust-toolchain.toml`. Target **`thumbv8m.main-none-eabihf`** (Cortex-M33), **not** the RP2040's `thumbv6m`.
- HAL: **`rp235x-hal`** (replaces `rp2040-hal`). Consider `embassy-rp` (RP2350 supported) if its DMA/PIO ergonomics are preferable — but kjagiello's low-level DMA approach maps most directly onto `rp235x-hal` + `rp235x-pac`. PIO assembly via the `pio`/`pio-proc` crates is HAL-agnostic and ports as-is.
- Flash/debug: **`probe-rs`** with a debug probe (a second Pico as a `debugprobe` works), or UF2 over USB BOOTSEL for quick flashing. `defmt` + RTT for logging.
- Set up the **RP2350 boot `ImageDef` block** early; prove the flash/boot path with a blink before any PIO work.
- Use **uv** for any host-side Python tooling (test-pattern generators, frame senders) per author preference. No pip/venv/conda.

---

## 8. Implementation phases (each milestone is verifiable on real hardware)

> No simulator — validation is against the actual dev board + panels, exactly as in the reference projects.

**Phase 0 — Bring-up.** Blink on RP2350-PiZero via `rp235x-hal`; confirm toolchain, boot block, flashing, RTT logging. *Done when:* LED blinks, `defmt` logs appear.

**Phase 1 — Port kjagiello as-is to RP2350, ONE chain, ONE panel.** Move from `rp2040-hal`→`rp235x-hal`, port `dma.rs` registers, get the unmodified 3-SM/4-DMA single-chain driver lighting a single 64×32 panel with a static test pattern. *Done when:* one panel shows correct gamma-corrected color, zero CPU in refresh (verify cores idle). **This de-risks the hardest port before adding width.**

**Phase 2 — Widen the data path to TWO parallel chains.** `out pins, 12`; widen the framebuffer cell to a packed 12-bit word; update the bulk packer (pitschu pattern). Drive two single panels (the two chains) in parallel. *Done when:* both chains show independent correct images, refresh unchanged.

**Phase 3 — Extend each chain to 4 daisy-chained panels (256×64 full wall).** Implement the param-driven coordinate mapper; tune `clkdiv` for clean 256-wide clocking; verify refresh ≥150 Hz and no smearing/ghosting at chain end. *Done when:* full 256×64 test patterns render correctly and flicker-free.

**Phase 4 — Bulk frame ingest + double-buffer.** Full-frame repack on core 1, `commit()` on vsync, local animated test source (e.g., port a plasma/flame). Measure max fps. *Done when:* smooth ≥30 fps animation from a CPU-generated source.

**Phase 5 — Pi 5 → RP2350 SPI link.** §10. *Done when:* frames generated on the Pi 5 render on the wall at ≥30 fps.

**Phase 6 — Custom PCB.** §9. Can begin in parallel after Phase 3 fixes the pin map.

---

## 9. Custom PCB — HAT/carrier for the dev board

**Scope:** the PCB is a **HAT that mounts on the RP2350-PiZero's 40-pin header**. The dev board supplies 3.3 V logic, crystal, flash, USB, and core power — so the PCB does **not** need the RP2350 power/crystal/decoupling design from `RP-008280` (that doc is only relevant if a future rev integrates a bare RP2350B). The HAT handles three things:

1. **Level shifting (3.3 V → 5 V) via `SN74AHCT245`** (author has 10 on hand — correct part: TTL-threshold inputs accept 3.3 V, push-pull 5 V CMOS outputs for HUB75's 5 V logic; tpd ~10 ns is fine at ≤25 MHz).
   - Fix each '245 direction (`DIR` tied), `OE`→GND (always enabled).
   - **Buffer per connector**, and fan out a **separately buffered copy of CLK/LATCH/OE/ADDR to each HUB75 connector** rather than driving four panels' worth of input capacitance from one buffer pin — clock integrity over the backplane is the thing that bites people. Budget: ~2 '245s per chain (6 RGB + shared control split across connectors); 10 chips comfortably covers 2 active chains + the 2 spare connectors.
   - Keep CLK traces short and roughly length-matched; series termination resistors (~22–33 Ω) on CLK and data near the '245 outputs are cheap insurance.
2. **Four HUB75 connectors** (2×8 IDC, standard HUB75/HUB75E pinout). Wire all four for upgradability even though only two are driven initially; route the spare two to GP19–21 + shared control so a firmware change lights them later.
3. **Panel power distribution.** Panels are the big load — **5 V at high current**. Measured: one 150 W / 30 A supply runs **four** panels fine (~37 W/panel peak), so **all eight need ~300 W / 60 A** — plan for two 150 W supplies (or one 60 A unit). Key rules:
   - Do **not** power panels from the dev board.
   - **Panel 5 V goes to each panel's own power lugs, never through the HUB75 ribbon** — the ribbon carries logic only. Inject power per row/chain with fat wire; add bulk capacitance (e.g. 1000 µF) near each panel-power injection point.
   - **Common all grounds:** panel-supply GND ↔ '245 5 V-rail GND ↔ dev board GND. The HAT itself only needs the 5 V rail to feed the '245s (a few mA) and that shared ground reference.
   - Per-'245 100 nF decoupling.

**Connector/pinout note:** confirm the HUB75 variant (HUB75 vs HUB75E — E adds the 5th address line E on what is otherwise GND/unused). 64×32 1/16-scan panels need only A–D.

---

## 10. Pi 5 → RP2350 link (deferred to Phase 5, reserve the design)

- **Transport: SPI**, Pi 5 as controller, RP2350 as peripheral. RP2350 USB is Full-Speed (~1.5 MB/s) — insufficient for 256×64×3 B×30 fps ≈ 1.47 MB/s with no margin. SPI at 25–50 MHz gives 3–6 MB/s, ample for 60 fps RGB888; RGB565 halves it.
- On the RP2350, receive via a **dedicated PIO block (PIO1/PIO2) + DMA** straight into the inactive framebuffer-source, or the hardware SPI peripheral + DMA. Use a spare contiguous GPIO group; mind the RP2350 input erratum (§3.2).
- Define a tiny framing protocol (magic/seq/length + payload, double-buffer flip on full frame). Consider a "dirty rectangle" or RGB565 mode later if bandwidth or Pi-side cost matters.
- The Pi 5 side can reuse the existing GLSL→framebuffer pipeline; replace the `rpi-rgb-led-matrix` output stage with an SPI writer (`spidev`).

---

## 11. Open questions / confirm before/while building

1. ~~Panel scan rate~~ — **RESOLVED: 1/16 scan, 4 address lines A–D.** Single HUB75 connector per panel; R1G1B1 feeds top half (rows 0–15), R2G2B2 the bottom half (rows 16–31).
2. ~~Header mapping~~ — **RESOLVED: standard Pi BCM numbering** (pin 12 = GPIO18). GP0–GP18 all broken out; see verified map in §6.
3. ~~HUB75 variant~~ — **RESOLVED: plain HUB75** (not HUB75E); 4 address lines suffice.
4. ~~Panel power~~ — **RESOLVED (sizing): ~300 W / 60 A for 8 panels** (two 150 W supplies). See §9.3 wiring rules.
5. **`generic_const_exprs` friction** — if the nightly const-generics path proves painful, fall back to a fixed compile-time config (concrete W/H/B consts) rather than fully generic types. Acceptable; the dimensions are fixed for this build.
6. **embassy vs bare rp235x-hal** — decide in Phase 1 based on DMA/PIO ergonomics; either is fine.
7. **Pixel-clock signal integrity** — the open empirical risk: validate clean 256-wide clocking through the '245s + backplane at the chosen `clkdiv` (target ~20–25 MHz); add series termination on CLK/data if there's ghosting. Determined on hardware in Phase 3.

---

## 12. Reference index

> The three prior-art repositories and the vendor datasheets below were studied
> during the build but are **not vendored** into RayGLow (license hygiene + repo
> weight). Clone/download them yourself if you want to follow the references; the
> upstreams are credited in [`ATTRIBUTION.md`](../../ATTRIBUTION.md).

**Repositories** (clone separately):
- **`kjagiello/hub75-pio-rs`** (MIT) — *the architecture base.* `src/lib.rs` (3-SM + 4-DMA design, framebuffer layout, the three PIO programs, DMA setup, double-buffer, set_pixel), `src/dma.rs` (register pokes ported to `rp235x-pac`), `src/lut.rs` (CIE/gamma LUT). RayGLow's `firmware/src/{lib,dma,lut}.rs` are a port of these.
- **`pitschu/RP2040matrix-v2`** — *parallel-channel + bulk-repack reference.* `hub75_BCM.c` (the two-channel repack), the `*_BCM.pio` programs, `include/hub75.h` (two-data-group pin layout). **Non-commercial license — used as a learning reference only; no code copied.**
- **`hzeller/rpi-rgb-led-matrix`** (GPL-2.0) — *background + coordinate-mapping math.* `lib/pixel-mapper.cc`, `lib/framebuffer.cc` for how BCM/bit-planes and panel mapping are done in the mature C++ library.

**Datasheets** (download from Raspberry Pi / Waveshare):
- RP2350 datasheet (1380 pp — PIO, DMA, GPIO, clocks; consult by section).
- Pico 2 datasheet + RP2350 product brief (package/GPIO/SRAM/PIO summary).
- "Hardware design with RP2350" (only needed for a bare-RP2350B PCB rev).
- RP2350-PiZero dev board schematic (header pin↔GPIO mapping).

---

## 13. One-paragraph summary for the implementing agent

Port kjagiello's `hub75-pio-rs` from `rp2040-hal` to `rp235x-hal` on an RP2350-PiZero (RP2350B), keep its zero-CPU 3-state-machine + 4-DMA refresh engine and PIO-timed BCM **exactly**, and make one structural change: widen the data path from one HUB75 chain to **two parallel chains** (`out pins, 12`, a 12-bit packed framebuffer word) so it drives **256×64 = two rows of four 64×32 panels**. Replace the per-pixel draw API with a **bulk frame→bit-plane repack** (pitschu pattern) pinned to core 1, preserving the CIE1931 gamma LUT. Validate in phases on real hardware (single panel → two chains → 4-deep chains → animation → SPI link from the Pi 5). The custom PCB is a **HAT** over the dev board doing only `SN74AHCT245` level-shifting, four HUB75 connectors, and dedicated 5 V panel power — no MCU support circuitry. GPIO: RGB GP0–11, address GP12–15, CLK/LAT/OE GP16–18.

---

## 14. Instrumentation & validation coverage (bench-gear reality check)

> The full bench inventory (source of truth) lives outside this repo in a private lab manifest. This section records only the **project-specific verdict**: can each §8 phase actually be *measured* with gear on hand?

**Bring-up target note (good news):** the firmware can be developed through Phase 4 on a **Pico 2 (RP2350A)** already on hand. The pin map needs only GP0–GP18 (19 pins; daisy-chaining adds *panels*, not pins), which fits the Pico 2's exposed GPIO, and RP2350A has **identical SRAM (520 KB) and PIO (3 blocks/12 SM)** to the RP2350B — it is not memory- or PIO-limited. The Waveshare RP2350B board is only needed for spare GPIO (future chains C/D + the SPI link). Prototype early phases on the Pico 2 to de-risk before the HAT exists.

**Phase → measurement coverage:**

| Phase | Needs | On hand? |
|---|---|---|
| 0 Bring-up | flash / boot / log | ✅ Waveshare USB-JTAG bridge or a spare Pico as `debugprobe`, USB |
| 1–2 one panel → two chains | rail check, slow-signal capture | ✅ FNIRSI DMM; PicoScope 2204A adequate for the ≤~5 MHz control/latch/address lines |
| 3 256-wide @ ~20–25 MHz | **CLK signal integrity** (§11.7) | 🔴 **GAP** — both scopes (10 MHz / ~200 kHz BW) are far below the ≥100–200 MHz needed (rule of thumb: scope BW ≥ 5× clock). Blocks the SI validation. |
| 4 Animation / sustained load | panel + '245 thermals, current under load | 🟡 partial — DC current via DMM/DC-clamp; no thermal camera yet |
| 5 Pi 5 → RP2350 SPI link | multi-channel bus timing | 🟡 no dedicated logic analyzer; interim stopgap = flash a spare Pico as a sigrok LA |

**Gaps & cheap fixes (priority order):**
1. 🔴 **≥100 MHz oscilloscope** — the one hard blocker (Phase 3 only). A 12-bit MSO (Rigol DHO900 / Siglent SDS800X HD) with the logic-probe option *also* closes the analyzer gap below. Until then, Phases 0–2 proceed; defer the §11.7 SI question to when the scope lands.
2. 🟡 **Logic analyzer** — DSLogic U3Pro16, or repurpose a spare Pico (sigrok) for free in the interim.
3. 🟡 **Constant-current bench supply** — no current-limit safety net on first HAT power-on (wall-wart workflow). Mitigate with an inline fuse (fuse kit on hand) until a programmable CC/CV supply is added.

**Power: covered.** 5 V @ 150 W (30 A) + 300 W (60 A) = **90 A**, comfortably over the ~60 A the 8-panel wall needs (§9.3).

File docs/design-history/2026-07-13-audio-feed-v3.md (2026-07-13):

# Audio feed v3 — the packet overhaul (shipped 2026-07-13)

The design record for feed v3: Will's brief (verbatim, from the ROADMAP fill-in
block), the v2 layout it replaced, and the decisions taken. Current truth lives in
`sender/README.md` (packet + features), `rayglow/render/textures.py` (texel maps),
and `rayglow/feed/receiver.py` (all accepted versions).

## Will's brief (verbatim)

> Will: HI! The original Milkdrop port included a handful of FFT bins that
> only targeted mid-range frequencies, mid-bass to mid-treble. We increased
> that range by adding a dedicated "sub" frequency which by and large is the
> the most useful visual-audio variable to generate movement/effects with.
> Eventually while trying to animate difference visualizers
> I became stuck on an issue of trying to change the "rate" of iTime in
> a single pass parallel shader pipe-line. Either I add a buffer so I
> can calculate d/dt or I have the backend do it for me. Considering that
> backend is my over-powered will-desktop, I had no issues doing the FFT
> and calculations over here to allow the usually gpu/cpu bound rpi5
> to have the processed information fed to it, ready to go.
> This worked *very* well. The specific data I have found absolutely
> key to fluid, punchy, visually appealing audio-visualizer shaders
> are the `.w env   imm through a ~125ms lag (ready-made amplitude control)`
> envelope variables calculated from ~125ms for all the chosen bands, (even vol)
> Moreso, the theta/meta.x
> variables that mimic iTime but instead step forward when their bin is high
> amplitutde, which I can turn into a looping phase and give moving objects acceleration
> instead of instant, spiky changes. These are all reference in:
> `rayglow/render/presets/milk-verbose.glsl`
>
>    vec4 theta = texelFetch(iChannel0, ivec2(5, 0), 0);
>    vec4 meta  = texelFetch(iChannel0, ivec2(6, 0), 0);
>
> The v2 approach I went into with the idea of just getting more interesting information
> over to the rpi, without thinking of how worthwhile that information was. I want to consider
> splitting the existing sub - bass - mid - treb into more bins, but not nearly as many as
> the updated v2 created. I would also like to expand the "flywheel" envelope values,
> creating up to three envelope readings, each with more "momentum" than the previous,
> with the current 125ms being the minimum. I would like a stronger "flywheel" that I
> can use without having to resort to buffers. If a bass punches hard, I would like that variables to
> to have different decay rates. If I use this for something like a spinning object, it quite literally
> visually functions represetns a flywheel. That "momentum" is what I'm struggling to create.
> also - the d/dt value isn't really needed. It is fine to computer on the client side for use calcs,
> but I find a signal that changes pos-neg so quickly is mostly useless. It's just jarring and
> and not pleasant to look at unless I surpress it to the point its effect doesn't appear.
>
> I would like to keep the instantaneous values for all, as I do make use of those. So
> essentially ~8 FFT bands, very low sub to very high treb, each with three flywheel envelopes, and
> each with three associated theta/meta type values that increase (and loop eventually) to use as iTime
> replacements. I would like to keep the new, similar items added in the v2 rollout, seen in
> ... presets/milk-features.glsl. The flux, the pan, swell, all interest me. However, the beat
> detection drove me nuts. Please look into refining that. I could not make sense of it and it rarely
> appeared to correlate with the beat of any music I had playing. If there is a better way
> to implement that, I would love to have that feature.
>
> As for the spectrum data. I vote we go to 1x128 or 1x256. Regardless, the screen is just
> not a high enough resolution to make much use out of such a dense band of information.
> (I may be wrong here, just I have no personally found much use). If I want a per pixel
> value across the x-axis, I can just mirror the think or fudge it.
>
> A few other ideas: I would potentially like to to be able to pass some form of
> smooth wave function, akin to fitting a polynomial on the the 8 (or however many) main
> FFT bins. The v2 had so many bands, isolating them was worthless, the band was so narrow
> that the audio they tracked didn't really sync in a noticeable way with the music. while
> we gained more "information" it was really just a lot of really accurate noise.
>
> And finally - when moving the v2 an effort was made to preserve the original Milk bands and
> and texel locations. This time around they can be discarded. As long as some of the new values
> are rough approximations (even if I have to do a (deepsub.w * 1.5 + lowsub * 0.5) = the class sub.w
> that is fine. I can quickly comb through my shaders and replace the values to get the original
> functionality back.
>
> As always - I am 100% open to suggestions. If there is a cool tool, method, approach, that I have
> not considered, that would be worthwhile to add, I would like to try it. Please take some time to
> consider this. What is out there, what is used, what would fit in with what we're doing.
> Thanks for coming to my ~TED Talk~ ramble.

## Decisions (with Will, 2026-07-13)

- **8 log-spaced bands** 20 Hz–16 kHz (20|60|120|250|500|1k|2.5k|6k|16k), multi-
  resolution: b0–b3 from the existing 4096-pt FFT, b4–b7 from the snappy 576-window
  FFT; no equalize — per-band AutoGain is the leveling.
- **Flywheel ballistics: punchy asymmetric** (Will's pick over symmetric inertia or a
  hybrid): tier0 = classic symmetric ~125 ms; tier1 ~60 ms attack / ~500 ms decay;
  tier2 ~150 ms / ~2 s. `ENV_TIERS` in sender.py is the tuning table.
- **Thetas integrate (imm, env1, env2)** — theta0 keeps today's beloved feel exactly;
  theta1/theta2 give rotation *momentum*. All wrap at 200π. Integration moved
  **sender-side** onto its steady clock (was Pi-side in `MilkChannel`, against jittery
  packet arrival — the v2 `dt` came from packet `t` deltas).
- **d/dt dropped** (jarring); its useful half survives as per-band one-sided **onset**
  (half-wave-rectified flux, own AutoGains) — Will opted in.
- **Beat tracker rebuilt** as a clean-room DAFx-09 implementation (`sender/beat.py`):
  comb-filterbank tempo induction (Rayleigh + continuity priors), cumulative-score
  alignment, slew-limited PLL beat grid, **predictive** beat_phase (ramps into the
  beat) + bar_phase. v2's flag-on-loud-onset + phase-halving heuristic is what "drove
  him nuts" — it reacted late and re-synced randomly. (BTrack is GPL: algorithm from
  the papers, no code ported.)
- **Spectrum 512 → 128** (Will's pick over 256): the wall is 256 px wide; v2's
  512 narrow bins were "really accurate noise". Axis constants recomputed
  (NLIN=23, FC=299.53125 Hz, R≈1.0386138; the sender prints them at startup).
- **Smooth wave function**: shipped as `.y`/`.z` rows of the (LINEAR-filtered)
  spectrum texture — Catmull-Rom-style curves through the 8 band values, computed
  Pi-side by one fixed (128×8) basis-matrix multiply. Kept off the wire so curve
  resolution isn't a protocol field.
- **Key detection** (Krumhansl-Schmuckler on a chroma EMA) — Will opted in.
- **Legacy bands kept on the wire** (header prefix unchanged, still computed by the
  untouched MilkDrop path) and surfaced in a legacy texel block (9–11, 2) — better
  than Will's offered "rough approximations": exact values, mechanical shader ports,
  and old senders (esp32-mic, raytop telemetry) stay visible.
- **milk texture 13×1 → 16×3** (levels / motion / globals rows, spares for the
  future); packet 4236 B → 2996 B.

## What v2 looked like (superseded)

Packet v2, 4236 B, `"<IHHIf7f2f512f512f12f5f3f2f"`: header (magic/ver/flags/seq/t),
7 legacy bands, sub/sub_att, wave[512], spec[512] (hybrid axis NLIN≈162,
FC≈1.9 kHz), chroma[12], centroid/flux/flatness/rolloff/crest,
bpm/beat_phase/beat_conf, width/pan. The receiver still accepts it (and v0/v1)
forever — see `rayglow/feed/receiver.py`.

milk texture 13×1 (superseded texel map):
texels 0–4 = bass/mid/treb/vol/sub with `.x` imm `.y` att `.z` ddt `.w` env
(ddt/env/theta were derived **on the Pi**, `MilkChannel` DDT_LAG=25/ENV_LAG=8);
texel 5 = thetas b/m/t/v; texel 6 = sub theta + pkt_age/live/source_domain;
texel 7 = descriptors; texel 8 = crest + bpm/240 + beat_phase + beat_conf;
texel 9 = beat/downbeat/width/pan; texels 10–12 = chroma. The old→new porting
table is in `sender/README.md`.

v2's beat detector (superseded): 6 s autocorrelation of AGC'd flux, argmax over
70–180 BPM integer frame lags (±2% BPM quantization at 60 Hz), phase advanced
open-loop with a "halve the phase on any onset > 1.8" re-sync heuristic.

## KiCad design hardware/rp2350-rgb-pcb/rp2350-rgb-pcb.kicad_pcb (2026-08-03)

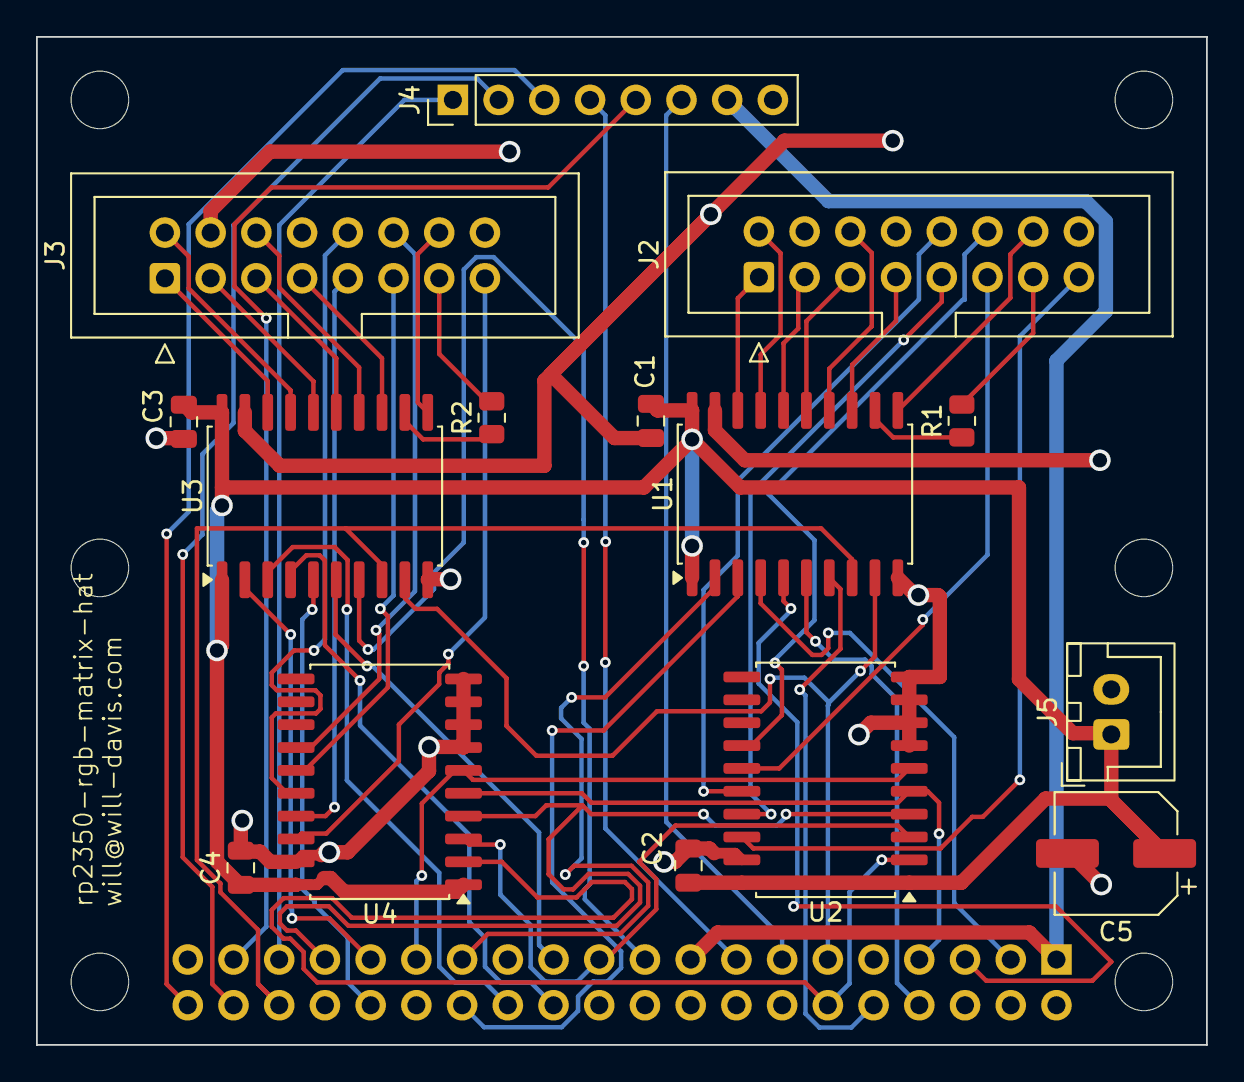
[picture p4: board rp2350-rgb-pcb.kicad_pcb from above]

Board: 2 copper layers, 65.0 x 56.0 mm, 16 parts (1 on the bottom side), 56 nets.

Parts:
C1, C2, C3, C4: 100nF; C_0805_2012Metric
C5: 100uF; CP_Elec_6.3x7.7
J1: RP2350-PiZero; PinSocket_2x20_P2.54mm_Vertical
J2: HUB75_A; IDC-Header_2x08_P2.54mm_Vertical
J3: HUB75_B; IDC-Header_2x08_P2.54mm_Vertical
J4: SPI_SYNC; PinHeader_1x08_P2.54mm_Vertical
J5: +5V_IN; JST_XH_B2B-XH-A_1x02_P2.50mm_Vertical
R1, R2: 22; R_0805_2012Metric
U1, U2, U3, U4: SN74AHCT245DWR; SOIC-20W_7.5x12.8mm_P1.27mm

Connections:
+3V3: J1.1, J1.17, J4.7
+5V: C1.1, C2.1, C3.1, C4.1, C5.1, J5.1, U1.1, U1.20, U2.1, U2.20, U3.1, U3.20, U4.1, U4.20
GND: C1.2, C2.2, C3.2, C4.2, C5.2, J1.6, J1.9, J1.14, J1.20, J1.25, J1.30, J1.34, J1.39, J2.4, J2.8, J2.16, J3.4, J3.8, J3.16, J4.8, J5.2, U1.10, U1.19, U2.7, U2.8, U2.9, U2.10, U2.19, U3.10, U3.19, U4.7, U4.8, U4.9, U4.10, U4.19
GP0: J1.27, U1.2
GP1: J1.28, U1.3
GP2: J1.3, U1.4
GP3: J1.5, U1.5
GP4: J1.8, U1.6
GP5: J1.10, U1.7
GP6: J1.31, U3.2
GP7: J1.26, U3.3
GP8: J1.24, U3.4
GP9: J1.32, U3.5
GP10: J1.23, U3.6
GP11: J1.19, U3.7
GP12: J1.21, U2.3, U4.3
GP13: J1.33, U2.4, U4.4
GP14: J1.7, U2.5, U4.5
GP15: J1.29, U2.6, U4.6
GP16: J1.36, U1.8, U3.8
GP17: J1.11, U1.9, U3.9
GP18: J1.12, U2.2, U4.2
GP19: J1.35, J4.1
GP20: J1.38, J4.2
GP21: J1.40, J4.3
GP22: J1.15, J4.4
GP26: J1.37, J4.5
GP27: J1.13, J4.6
unnamed: J2.1, U1.18
unnamed: J2.2, U1.17
unnamed: J2.3, U1.16
unnamed: J2.5, U1.15
unnamed: J2.6, U1.14
unnamed: J2.7, U1.13
unnamed: R1.1, U1.12
unnamed: J2.13, R1.2
unnamed: J2.14, U1.11
unnamed: J2.15, U2.18
unnamed: J2.9, U2.17
unnamed: J2.10, U2.16
unnamed: J2.11, U2.15
unnamed: J2.12, U2.14
unnamed: J3.1, U3.18
unnamed: J3.2, U3.17
unnamed: J3.3, U3.16
unnamed: J3.5, U3.15
unnamed: J3.6, U3.14
unnamed: J3.7, U3.13
unnamed: R2.1, U3.12
unnamed: J3.13, R2.2
unnamed: J3.14, U3.11
unnamed: J3.15, U4.18
unnamed: J3.9, U4.17
unnamed: J3.10, U4.16
unnamed: J3.11, U4.15
unnamed: J3.12, U4.14

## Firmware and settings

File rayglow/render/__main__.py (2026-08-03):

"""Shadertoy renderer entry point.

Headless dry-run (no root, no hardware; writes an animated GIF):
    ~/venv/bin/python -m rayglow.render ../example.glsl --dry-run 120

Hardware (user runs this; root needed for GPIO):
    sudo ~/venv/bin/python -m rayglow.render ../example.glsl

Texture/audio channels — bind iChannel0..3 with --channelN flags or, better,
`// iChannelN: spec` comment directives inside the shader file:
    sudo ~/venv/bin/python -m rayglow.render presets/foo.glsl \\
        --channel0 audio --channel1 noise --channel2 pic.png

'audio' is the Shadertoy 512x2 spectrum/waveform texture, fed live from the
milk UDP feed (port 5005) with the usual synth fallback when no packets
arrive; --no-listen skips the socket entirely (synth only).  Dry-run never
listens.  'milk' is a 16x3 float texture of the v3 feed: 8 log-spaced bands
(1.0 = typical, hits spike 2-3) with three flywheel envelopes and three
"music time" theta phases each, per-band onsets, beat/key/descriptor/stereo
globals, packet liveness, and the legacy MilkDrop scalars — see MilkChannel
in textures.py for the texel map.  'spectrum' is a 128x1 float texture: the
feed's real spectrum (.x) + smooth band curves (.y/.z).  Use milk when the
audio texture's clamped spectrum feels binary, spectrum for a real shape.

Multipass (Shadertoy Buffer A-D): sibling files next to foo.glsl named
foo.bufA.glsl .. foo.bufD.glsl are auto-discovered and rendered in Shadertoy
order (A,B,C,D, then image) into float ping-pong buffers.  Wire inputs with
directives in each pass file, e.g. in foo.bufA.glsl:
    // iChannel0: self          <- bufA's own previous frame
and in foo.glsl:
    // iChannel0: bufA

While running on hardware, edit any of the .glsl files in another window and
save — the panel recompiles live (compile errors print here; last good
shader keeps showing, and buffer state survives the reload).

--loop SECONDS cycles every standalone .glsl in the launched shader's folder,
switching on that interval and wrapping at the end (buffer siblings
foo.bufA.glsl..bufD.glsl are skipped; a shader that fails to compile is
skipped too). Each switch rebuilds the shader fresh, so iTime/iFrame restart
at 0 and multipass buffers start cleared:
    sudo ~/venv/bin/python -m rayglow.render presets/first.glsl --loop 30

While running on hardware the renderer also opens a TCP control plane
(render/control.py, port config.CONTROL_PORT=5006; --no-control to skip) — an
mpd-style command channel.  Drive it with tools/rayglow_ctl.py from the Pi or
the desktop:
    rayglow-ctl push foo.glsl    # ship a local edit NOW (skips the file sync)
    rayglow-ctl load ~/presets/bar.glsl   # switch to a shader already on the Pi
    rayglow-ctl next / prev / play / pause / reload
    rayglow-ctl loop 30 | loop off | repeat | status
    rayglow-ctl scale 3 | scale auto      # live supersample change (rebuilds)
`push` is the low-latency dev loop: it hands the source (plus buffer siblings
and referenced image assets) straight to the running renderer, so the wall
updates in <100ms instead of waiting on mutagen, and GLSL compile errors come
back in the reply.  play/pause freeze the shader clock (the audio feed keeps
running); loop/repeat/next/prev are the playlist controls over the launched
shader's folder.  See tools/nvim-rayglow.lua for the save-hook.

Supersample scale is per-shader and live: precedence is --scale > a shader's
`// rayglow: scale=N` directive > config.DEFAULT_SCALE.  `scale N` sets a
runtime override (sticky across switches until `scale auto` clears it back to
the directive/default); each change reallocates FBOs, so it rebuilds the shader
(iTime restarts).
"""
import argparse
import base64
import os
import queue
import re
import sys
import threading
import time

import numpy as np

from ..feed import config  # geometry/gamma source of truth (shared feed pkg)
from .. import userconf

from . import textures
from .control import ControlServer, PlayerState
from .egl import GLContext, GLError
from .pipeline import ShaderToy
from .reload import GlslWatcher


def pin_to_core(core):
    """Pin the render thread to a dedicated core so frame pacing doesn't fight
    scheduler migration.  Per-thread on Linux (affects only this thread)."""
    try:
        os.sched_setaffinity(0, {core})
    except OSError as e:
        print(f"warning: could not pin to core {core}: {e}", file=sys.stderr)


class AudioFeed:
    """Owns the milk feature state (+ lazily bound UDP receiver) and pushes
    the waveform into every audio channel each frame.  `channels` is the
    ShaderToy's live audio_channels list — a hot reload that introduces an
    audio directive starts feeding (and listening) without a restart.
    Synth fallback keeps the texture animating when nothing is playing."""

    def __init__(self, channels, allow_listen):
        from ..feed.features import FeatureState
        self.features = FeatureState()
        self.channels = channels
        self.allow_listen = allow_listen
        self.receiver = None
        self._announced = False

    def update(self, t, dt):
        if not self.channels:
            return
        if not self._announced:
            self._announced = True
            if self.allow_listen:
                from ..feed.receiver import Receiver
                self.receiver = Receiver()
                print("audio: listening on UDP")
            else:
                print("audio: synth fallback only")
        pkt = self.receiver.poll() if self.receiver else None
        self.features.update(pkt, t, dt)
        for ch in self.channels:
            ch.update(self.features)


def compile_or_die(toy, name, src):
    ok, msg = toy.set_source(name, src)
    if not ok:
        print(f"GLSL compile error ({name}):\n{msg}", file=sys.stderr)
        sys.exit(1)
    if msg:
        print(f"warning ({name}): {msg}", file=sys.stderr)


def maybe_reload(toy, watchers):
    for name, watcher in watchers.items():
        if not watcher.changed():
            continue
        try:
            src = watcher.read()
        except OSError as e:
            print(f"reload: cannot read {watcher.path}: {e}", file=sys.stderr)
            continue
        ok, msg = toy.set_source(name, src)
        if ok:
            print(f"reloaded {watcher.path}"
                  + (f"  (warning: {msg})" if msg else ""))
        else:
            print(f"reload failed ({name}) — keeping last good shader:\n{msg}",
                  file=sys.stderr)


def _directive_scale(image_src):
    """The `// rayglow: scale=N` directive from a shader source, validated to a
    1..8 int, or None if absent/malformed."""
    val = textures.parse_settings(image_src).get("scale")
    if val is None:
        return None
    try:
        n = int(val)
    except ValueError:
        print(f"shader setting: ignoring non-integer scale={val!r}",
              file=sys.stderr)
        return None
    if not 1 <= n <= 8:
        print(f"shader setting: clamping scale={n} to [1,8]", file=sys.stderr)
        n = max(1, min(8, n))
    return n


def resolve_scale(scale_override, directive_scale):
    """Effective supersample factor + where it came from.  Precedence: an
    explicit override (CLI --scale, seeded into PlayerState, or a runtime
    `scale` command) wins; else the shader's `// rayglow: scale=` directive;
    else config.DEFAULT_SCALE.  Returns (scale, source)."""
    if scale_override is not None:
        return scale_override, "override"
    if directive_scale is not None:
        return directive_scale, "directive"
    return config.DEFAULT_SCALE, "default"


def build_shader(args, use_pbo, shader_path, fatal=True, scale_override=None):
    """Build a fresh ShaderToy + GlslWatchers for one shader file and its
    sibling buffer passes (foo.bufA.glsl .. foo.bufD.glsl).

    All passes are created before any compile so buffer cross-references
    resolve regardless of order; buffers compile first, image last.  CLI
    --channelN overrides apply to the image pass.

    Scale (supersample factor) is resolved per build: `scale_override` (the CLI
    --scale seed or a runtime `scale` command) wins, else the image shader's
    `// rayglow: scale=N` directive, else config.DEFAULT_SCALE.  A scale change
    reallocates FBOs, which is exactly what this fresh build does — so runtime
    scale rides the same rebuild path as a shader switch (there is no in-place
    scale change).

    args.render_gamma / args.resolve_flip are derived in main(): the resolve
    pass bakes them in on the GPU (wall runs get PACK_GAMMA + config flips;
    dry-runs get --gamma and no flips, as before); legacy mode instead feeds
    --gamma to the CPU readback LUT.

    fatal=True (initial launch): a compile error exits the process.
    fatal=False (--loop switch / control switch): a compile error prints, tears
    the half-built toy back down, and returns (None, None, msg) so the caller
    keeps the last good shader and can relay `msg` to a control client.

    Returns (toy, watchers, err): err is None on success, else the compile
    message (fatal=False only).
    """
    # Read the image source up front so the `// rayglow: scale=` directive can
    # size the FBOs (ShaderToy allocates at scale on construction).
    image_watcher = GlslWatcher(shader_path)
    try:
        image_src = image_watcher.read()
    except OSError:
        image_src = ""
    scale, scale_src = resolve_scale(scale_override, _directive_scale(image_src))
    if scale_src != "default":
        print(f"scale: {scale}x ({scale_src})")

    toy = ShaderToy(args.width, args.height, scale=scale,
                    gamma=args.render_gamma, use_pbo=use_pbo,
                    readback=args.readback, resolve_flip=args.resolve_flip,
                    quiet=not fatal,
                    base_dir=os.path.dirname(os.path.abspath(shader_path)))
    for i in range(4):
        spec = getattr(args, f"channel{i}")
        if spec:
            toy.set_cli_channel(i, spec)

    watchers = {}
    base = re.sub(r"\.glsl$", "", shader_path)
    for x in "ABCD":
        path = f"{base}.buf{x}.glsl"
        if os.path.exists(path):
            toy.add_buffer(f"buf{x}")
            watchers[f"buf{x}"] = GlslWatcher(path)
    watchers["image"] = image_watcher   # reuse the early read; keeps image last
    if len(watchers) > 1:
        print(f"multipass: {', '.join(watchers)} "
              f"(buffers: {toy.buffer_format[3]})")
    for name, watcher in watchers.items():
        if fatal:
            compile_or_die(toy, name, watcher.read())
        else:
            ok, msg = toy.set_source(name, watcher.read())
            if not ok:
                print(f"build: {shader_path} compile error "
                      f"({name}):\n{msg}", file=sys.stderr)
                toy.destroy()
                return None, None, f"compile error ({name}): {msg}"
            if msg:
                print(f"warning ({name}): {msg}", file=sys.stderr)
    return toy, watchers, None


def build_playlist(shader_path):
    """Sorted absolute paths of the standalone .glsl files in shader_path's
    directory.  Buffer siblings (foo.bufA.glsl .. foo.bufD.glsl) are excluded
    — they're multipass inputs, not shaders to display on their own."""
    d = os.path.dirname(os.path.abspath(shader_path))
    buf_re = re.compile(r"\.buf[A-D]\.glsl$")
    names = sorted(f for f in os.listdir(d)
                   if f.endswith(".glsl") and not buf_re.search(f))
    return [os.path.join(d, n) for n in names]


def switch_to(old_toy, feed, player, args, use_pbo, path, display_name=None):
    """Full rebuild -> hot-swap: build a fresh toy for `path`, and on success
    destroy the outgoing one, repoint the live audio feed at the new channels,
    and reset the (pausable) shader clock to 0.  Playlist/index are the caller's
    to manage.  Returns (new_toy, new_watchers, None) on success, or
    (None, None, err) on failure with `old_toy` left untouched (last good
    shader stays on the wall)."""
    path = os.path.abspath(os.path.expanduser(path))
    if not os.path.isfile(path):
        return None, None, f"no such shader: {path}"
    new_toy, new_watchers, err = build_shader(args, use_pbo, path, fatal=False,
                                              scale_override=player.scale_override)
    if new_toy is None:
        return None, None, err
    old_toy.destroy()                       # free the outgoing toy's GL objects
    feed.channels = new_toy.audio_channels  # repoint the live feed
    player.current_path = path
    player.display_name = display_name or os.path.basename(path)
    player.scale = new_toy.scale             # effective scale after precedence
    player.shader_time = 0.0                 # full rebuild => iTime/iFrame = 0
    player.shader_frame = 0
    return new_toy, new_watchers, None


def _advance(toy, feed, player, args, use_pbo, step):
    """Walk the folder playlist by `step` (+1 next / -1 prev, wrapping) to the
    next shader that compiles and switch to it, updating player.index.  Shared
    by --loop auto-advance and the next/prev commands.  Returns
    (new_toy, new_watchers, None) or (None, None, err) (keep current)."""
    pl = player.playlist
    n = len(pl)
    if n == 0:
        return None, None, "playlist empty"
    start = player.index if player.index >= 0 else 0
    for k in range(1, n + 1):
        j = (start + step * k) % n
        nt, nw, _err = switch_to(toy, feed, player, args, use_pbo, pl[j])
        if nt is not None:
            player.index = j
            return nt, nw, None
    return None, None, "no compilable shader in folder"


def run_dry(toy, feed, args):
    """Render N frames headlessly with a fixed synthetic clock, sanity-check
    the numerics, save a GIF."""
    from .output import save_gif
    frames = []
    dt = 1.0 / args.fps
    t0 = time.perf_counter()
    for i in range(args.dry_run):
        if feed:
            feed.update(i * dt, dt)
        frames.append(toy.render(i * dt, dt, i))
    elapsed = time.perf_counter() - t0
    fps = args.dry_run / elapsed

    stack = np.stack(frames)
    fmin, fmean, fmax = int(stack.min()), float(stack.mean()), int(stack.max())
    print(f"{args.dry_run} frames at {toy.width}x{toy.height} "
          f"(scale {toy.scale}) in {elapsed:.2f}s = {fps:.0f} fps")
    print(f"pixels: min={fmin} mean={fmean:.1f} max={fmax}")
    ok = True
    if fmax == 0:
        print("FAIL: output is all black")
        ok = False
    if fmean > 250:
        print("WARN: output near-saturated (mean > 250)")
    save_gif(frames, args.out, args.fps)
    print(f"wrote {args.out}")
    sys.exit(0 if ok else 1)


class _SendPipe:
    """Background link sender that overlaps frame N's transfer with frame N+1's
    render. `out.send()` blocks for the transfer floor + READY wait; running
    it on a worker thread lets the main thread render+pack the next frame
    meanwhile, so the loop cadence becomes max(render+pack, send) instead of
    their sum. Depth-1 (one frame in flight) keeps the added latency to a single
    frame. Only the worker touches `out`, so the link/GPIO objects stay
    single-threaded. The GIL is released during the transfer (pioshim DMA burst
    or spidev write) and READY wait, so the overlap is real.
    """

    def __init__(self, out):
        self._out = out
        self._payload = None
        self._work = threading.Event()    # main -> worker: a payload is ready
        self._idle = threading.Event()    # worker -> main: previous send done
        self._idle.set()                  # start idle
        self._stop = False
        self._exc = None
        self.acc_send = 0.0               # worker: cumulative transfer seconds
        self._thread = threading.Thread(target=self._run, daemon=True)
        self._thread.start()

    def _run(self):
        while True:
            self._work.wait()
            self._work.clear()
            if self._stop:
                return
            try:
                t = time.perf_counter()
                self._out.send(self._payload)
                self.acc_send += time.perf_counter() - t
            except BaseException as e:    # surface to main on next submit()
                self._exc = e
            self._idle.set()

    def submit(self, payload):
        """Block until the previous send finishes (the residual send-bound
        stall), hand off `payload`, and return that wait time in seconds. The
        worker transfers it while the caller renders the next frame."""
        t = time.perf_counter()
        self._idle.wait()
        wait = time.perf_counter() - t
        if self._exc is not None:
            raise self._exc
        self._idle.clear()
        self._payload = payload
        self._work.set()
        return wait

    def close(self):
        self._idle.wait()
        self._stop = True
        self._work.set()
        self._thread.join(timeout=2.0)
        self._out.close()


_BUF_KEY = re.compile(r"buf[A-D]")


def _safe_rel(rel):
    """Sanitize a client-supplied asset path: drop absolute/`..` components so a
    push can't write outside LIVE_DIR."""
    parts = [p for p in rel.replace("\\", "/").split("/")
             if p and p not in (".", "..")]
    return os.path.join(*parts) if parts else ""


def _write_live_slot(msg):
    """Write a pushed bundle into LIVE_DIR (the tmp file that holds what's
    running) and return the image .glsl path.  Clears this shader's stale buffer
    siblings first, so a bufX removed in the editor doesn't linger and get
    auto-discovered on the rebuild.  `msg`: {name, passes{image,bufA..D},
    assets?{relpath: base64}}."""
    passes = msg.get("passes") or {}
    if "image" not in passes:
        raise ValueError("push: bundle has no image pass")
    live = os.path.expanduser(config.LIVE_DIR)
    os.makedirs(live, exist_ok=True)
    name = os.path.basename(msg.get("name") or "now-playing.glsl")  # no traversal
    if not name.endswith(".glsl"):
        name += ".glsl"
    base = re.sub(r"\.glsl$", "", name)
    for x in "ABCD":
        stale = os.path.join(live, f"{base}.buf{x}.glsl")
        if os.path.exists(stale):
            os.remove(stale)
    image_path = os.path.join(live, name)
    with open(image_path, "w") as f:
        f.write(passes["image"])
    for key, src in passes.items():
        if key == "image":
            continue
        if not _BUF_KEY.fullmatch(key):
            raise ValueError(f"push: bad pass name {key!r}")
        with open(os.path.join(live, f"{base}.{key}.glsl"), "w") as f:
            f.write(src)
    for rel, b64 in (msg.get("assets") or {}).items():
        safe = _safe_rel(rel)
        if not safe:
            continue
        dst = os.path.join(live, safe)
        os.makedirs(os.path.dirname(dst) or live, exist_ok=True)
        with open(dst, "wb") as f:
            f.write(base64.b64decode(b64))
    return image_path


def _reseat_playlist(player, path):
    """Rebuild the folder playlist around `path` and point index at it."""
    player.playlist = build_playlist(path)
    ap = os.path.abspath(path)
    player.index = player.playlist.index(ap) if ap in player.playlist else -1
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

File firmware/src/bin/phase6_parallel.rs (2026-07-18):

//! Phase 6 — Pi 5 → RP2350 **4-lane parallel** link (Workstream 3).
//!
//! A widened sibling of `phase_experimental`: identical single-chain scan-out
//! engine, identical READY handshake, identical RX DMA + framebuffer drop — the
//! ONLY change is the ingest data path. Phase 5 / experimental clock one MOSI bit
//! per SCLK edge (8 edges/byte); this clocks **4 data lanes per edge = a nibble per
//! edge, 2 edges/byte**, fed by the Pi 5's RP1 PIO block.
//!
//! ## Why 4 lanes, and why no CS (custom-HAT J4 pin budget)
//! The link runs over the HAT's J4 breakout, the only Pi↔RP2350 connector on the
//! PCB. J4 carries exactly 6 GPIO — GP19,20,21,22,26,27 (the dead-on-HAT GP23,24,25
//! are NOT routed there). 4 data + DCLK + CS + READY = 7 won't fit, so CS is
//! dropped by default (`USE_CS=false`): the frame is delimited by READY + the fixed
//! FRAME_BYTES contract, and `sm.restart()` + the RX_STALL watchdog re-sync any
//! corrupt frame — CS was largely redundant with the watchdog. CS is kept as a
//! jumper-able reserve on GP25 (see USE_CS). 4 lanes still divides a byte cleanly
//! (2 nibbles) and lifts the link off the critical path: at the Pi's clkdiv 3,
//! 4×~33 MHz ≈ 133 Mbit/s → a 32 KB frame in ~2 ms (vs ~6.6 ms over 40 MHz SPI),
//! and the host render∥send overlap hides it entirely (`wait`≈0).
//!
//! ## Byte order (why the stream stays byte-identical)
//! `in pins, 4` samples lanes DATA0..3 = one nibble; autopush at 8 = two samples
//! per byte. RX shifts **left** (like the proven single-lane path) so the byte
//! lands in ISR[7:0] where the byte-size DMA reads it — first nibble sampled →
//! HIGH nibble. So the Pi must send the HIGH nibble of each byte first: it does a
//! cheap per-byte nibble-swap then `out pins, 4` shift-right (autopull 32, byte
//! order preserved). Net: the framebuffer ends byte-identical to
//! `hub75.py::pack_single`. **Validate on a logic analyzer first** with a
//! 0x00,0x01,0x02… ramp: if every byte's nibbles are swapped, toggle the Pi's
//! `nibble_swap` (PioOut); if bits within a nibble mirror, reverse the lane
//! wiring. (This ordering can't be proven from the desk.)
//!
//! ## Pin map  (RP2350b GP ↔ J4 pin ↔ rpi5 BCM ↔ signal)
//!     DATA0  GP19  J4.1  ← rpi5 GPIO12        (4 lanes, IN base = GP19)
//!     DATA1  GP20  J4.2  ← rpi5 GPIO13
//!     DATA2  GP21  J4.3  ← rpi5 GPIO14
//!     DATA3  GP22  J4.4  ← rpi5 GPIO15
//!     DCLK   GP26  J4.5  ← rpi5 GPIO20        (Pi-driven data clock)
//!     READY  GP27  J4.6  → rpi5 GPIO25 (input)(RP2350 → Pi: armed)
//!     3V3    J4.7   |   GND  J4.8 (a return beside the lane bundle; keep short).
//!     CS (reserve) GP25 ← rpi5 GPIO21, via a jumper to the protruding J1 header
//!       pin 22 (GP25 is unrouted on the HAT). Only used when USE_CS=true.
//! Scan-out engine pins are unchanged (GP0–18). DATA0..3 must stay CONTIGUOUS (the
//! `in pins, 4` group); DCLK/CS are read by absolute `wait gpio` so they are
//! hardcoded in the PIO program below — keep the consts in sync with the literals.
//!
//! ## Single vs two-chain (the `two-chain` cargo feature)
//! The parallel RX is chain-agnostic — the link byte stream is identical; only the
//! framebuffer cell type + size differ. A cargo feature picks the geometry so ONE
//! bin builds both:
//!   * default          → single-chain: `hub75::single` (u8 cells), chain A only,
//!                         W×H wall. Match the Pi: `SINGLE_CHAIN=True`.
//!   * `--features two-chain` → full wall: `hub75::Display` (u16 cells), both
//!                         chains, W×2H. Match the Pi: `SINGLE_CHAIN=False`,
//!                         `PARALLEL_CHAINS=2`, and pack via `pack()` (auto in run_wall).
//! Physical: two-chain drives the second 4 panels off the HAT's J3 (chain B,
//! GP6–11); single-chain leaves J3/GP6–11 black.
//!
//! Run:
//!     cargo run --bin phase6-parallel                    # single-chain
//!     cargo run --bin phase6-parallel --features two-chain  # full 256x64 wall

#![no_std]
#![no_main]
#![feature(generic_const_exprs)]
#![allow(incomplete_features, static_mut_refs)]

use defmt::info;
use defmt_rtt as _;
use panic_probe as _;

use rp235x_hal as hal;

use embedded_graphics::pixelcolor::Rgb888;
use embedded_hal::digital::OutputPin;

use hal::gpio::{FunctionPio1, PullDown, PullUp};
use hal::pio::{Buffers, PIOBuilder, PIOExt, PinDir, ShiftDirection};

use rp2350_rgb_driver as hub75;
use hub75::dma::{Channel, ChannelIndex, ChannelRegs, DMAExt, CH4};
use hub75::lut::GammaLut;

#[link_section = ".start_block"]
#[used]
pub static IMAGE_DEF: hal::block::ImageDef = hal::block::ImageDef::secure_exe();

#[link_section = ".bi_entries"]
#[used]
pub static PICOTOOL_ENTRIES: [hal::binary_info::EntryAddr; 3] = [
    hal::binary_info::rp_cargo_bin_name!(),
    hal::binary_info::rp_cargo_version!(),
    hal::binary_info::rp_program_description!(c"RP2350 RGB driver - Phase 6 parallel 4-lane link"),
];

const XTAL_FREQ_HZ: u32 = 12_000_000;
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

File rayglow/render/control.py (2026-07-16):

"""Renderer control plane — the live-dev push channel + media controls.

A long-running renderer (``run_wall``) is an mpd/mpv-style daemon; this module is
its IPC socket. A tiny CLI (``tools/rayglow_ctl.py``), an nvim save-hook, or a
future web/HA UI are all just clients speaking one protocol.

Why this exists: the mtime hot-reload (`reload.GlslWatcher`) already re-stats the
shader every frame, so render-side detection is ~one frame. The 5-20s save->wall
latency is entirely mutagen propagating the file desktop->Pi. A ``push`` hands the
source straight to the running renderer, bypassing mutagen for the dev loop
(mutagen stays the durable background library sync).

Transport: **TCP**, not the feed's UDP. Control is low-rate and reliability-
sensitive — a dropped "next" or a truncated shader push is a bug, the opposite of
the feed's lossy latest-wins stream. Framing is a 4-byte big-endian length prefix
+ UTF-8 JSON (`send_msg`/`recv_msg`): length-prefixed so partial TCP reads
reassemble, JSON because this is the control plane (not the frame plane) — it's
`socat`-debuggable and extends cleanly (a future brightness cmd, per-shader
settings). GLSL is text, so a shader rides in a JSON string field.

Threading & GL affinity: the GL context is thread-affine, so socket threads must
NEVER touch GL. Every request becomes a `Command` on a `queue.Queue`; the render
thread drains and executes it (the sole reader/writer of `PlayerState`, so no
locks), fills the reply, and signals the waiting handler thread — which returns the
reply (incl. compile errors) to the client. Latency is <= one frame (~8ms).

Protocol (v1) — request ``{"cmd": ..., ...}`` -> reply ``{"ok": bool, ...}``:

    push    name, passes{image,bufA..D}, assets?  write live slot, full rebuild
    load    path                                  full rebuild from a Pi path
    next / prev                                   step the folder playlist
    play / pause                                  resume / freeze the shader clock
    loop    seconds | off                         set/clear auto-advance interval
    repeat  on | off (toggles if absent)          hold current (suppress advance)
    reload                                         re-read current from disk
    status                                         player snapshot
"""
import json
import socket
import struct
import threading

from ..feed import config

_LEN = struct.Struct(">I")      # 4-byte big-endian length prefix
MAX_MSG = 8 * 1024 * 1024       # 8 MiB ceiling — a shader bundle is tiny; a big
                                # texture asset is the only thing near this


def send_msg(sock, obj):
    """Frame `obj` as length-prefixed UTF-8 JSON and write it to `sock`."""
    body = json.dumps(obj).encode("utf-8")
    sock.sendall(_LEN.pack(len(body)) + body)


def _recv_exact(sock, n):
    """Read exactly n bytes or return None on clean EOF (peer closed)."""
    buf = bytearray()
    while len(buf) < n:
        chunk = sock.recv(n - len(buf))
        if not chunk:
            return None
        buf += chunk
    return bytes(buf)


def recv_msg(sock):
    """Read one framed message -> dict, or None on clean EOF.

    Raises ValueError on a length that exceeds MAX_MSG (a malformed or hostile
    prefix) so the handler can drop the connection instead of trying to allocate
    it."""
    head = _recv_exact(sock, _LEN.size)
    if head is None:
        return None
    (length,) = _LEN.unpack(head)
    if length > MAX_MSG:
        raise ValueError(f"message length {length} exceeds {MAX_MSG}")
    body = _recv_exact(sock, length)
    if body is None:
        return None
    return json.loads(body.decode("utf-8"))


class Command:
    """One request in flight: the socket thread enqueues it and blocks on `done`;
    the render thread fills `reply` and sets `done`."""

    __slots__ = ("msg", "reply", "done")

    def __init__(self, msg):
        self.msg = msg
        self.reply = None
        self.done = threading.Event()


class PlayerState:
    """Playback state for the live loop. Mutated ONLY by the render thread (the
    command drain), so it needs no lock. The socket threads never read it — a
    `status` request is a `Command` the render thread answers via `snapshot()`."""

    def __init__(self, playlist, index, loop_interval, display_name, current_path,
                 scale_override=None, scale=None):
        self.playlist = playlist        # sorted abs paths in `folder` (may be [])
        self.index = index              # position in playlist (or -1 if off-list)
        self.loop_interval = loop_interval   # seconds, or None = auto-advance off
        self.repeat = False             # hold current: suppress auto-advance
        self.paused = False             # freeze the shader clock (not the feed)
        self.display_name = display_name     # what status/prints show
        self.current_path = current_path     # the .glsl actually being rendered
        # Scale (supersample factor). scale_override is the explicit request (CLI
        # --scale seed or a runtime `scale` command); None = auto (defer to a
        # `// rayglow: scale=` directive, else config.DEFAULT_SCALE). Sticky
        # across switches until set back to auto. `scale` is the effective value
        # the current toy is actually rendering at (set by switch_to).
        self.scale_override = scale_override
        self.scale = scale
        # Pausable shader clock — accumulates real dt only while not paused, so
        # iTime/iFrame freeze on pause and resume without a jump. Reset to 0 on
        # every switch/push/reload (full rebuild => t=0, per the design).
        self.shader_time = 0.0
        self.shader_frame = 0
        self.fps = 0.0                  # render loop stamps this for status

    @property
    def folder(self):
        import os
        return os.path.dirname(self.current_path)

    def snapshot(self):
        return {
            "shader": self.display_name,
            "path": self.current_path,
            "index": self.index,
            "playlist_len": len(self.playlist),
            "paused": self.paused,
            "loop": self.loop_interval,
            "repeat": self.repeat,
            "scale": self.scale,
            "scale_override": self.scale_override,   # null => auto (directive/default)
            "fps": round(self.fps, 1),
        }
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

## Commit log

2026-06-07 Import desktop sender half as-is
    From ~/Projects/milk-pi/ verbatim: the audio feature daemon, its uv
    project, and its docs. Renamed package/docs come in a later commit; this
    import is byte-identical so git --follow traces the history.
    Dropped sender.py.bak (the pre-sub-band v0 sender) — git history now
    serves that role.
2026-06-07 Import Pi custom code as-is (flat layout)
    From ~/rpi-rgb-led-matrix/will-rpi-custom/ (mounted), verbatim except
    __pycache__ and the mount's .Trash. Kept at the repo root with original
    package names (milk/, shadertoy/, hzeller-direct/) so imports still resolve
    and this commit is byte-identical to the source — the rename into the
    rayglow/ namespace is the next commit, traced via git mv.
    Did NOT import will-rpi-custom/sender.py: it was a manually-synced copy of
    the desktop sender, now superseded by the single tracked sender/sender.py.
    [__main__.py, draw.py, egl.py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]
2026-06-07 Restructure into the rayglow namespace
    The project is no longer a MilkDrop port or a Shadertoy fork; it's its own
    thing. Give it an owned package layout:
    milk/{config,features,receiver}.py -> rayglow/feed/ (shared protocol)
    shadertoy/ -> rayglow/render/ (the live renderer)
    milk/fake_sender.py -> rayglow/fake_sender.py
    milk/ (engine, warp, dotmilk, ...) -> rayglow/legacy/ (retired renderer)
    milk/presets/ -> rayglow/legacy/milkpresets/
    Rationale:
    - 'feed' is a neutral package both renderers import, so the live path never
    depends on a 'legacy' namespace. It's also the future yaml-config target.
    - 'render' is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
    [__main__.py, draw.py, egl.py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]
2026-06-07 Archive BUILD-HISTORY.md; correct Pi deploy command
    - Import the Pi-agent knowledge export into docs/design-history/ (decision
    log, dead ends, the panel-1 artifact root-cause, V3D/EGL quirks, calibration
    table, load-bearing oddities, timeline). Verbatim, with a header banner
    noting it predates the restructure and its paths refer to the old layout.
    - Reconciled its section 5 against the rename: every load-bearing oddity lives
    in files moved byte-identically, so the restructure breaks none of them.
    Gate cleared.
    - Deploy fix surfaced by the export (section 3): rgbvenv is uv-managed and has
    no pip binary, so the editable install must go through
    'uv pip install --python ~/rgbvenv/b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
2026-06-15 Major overhaul. Folding in rp2350 firmware and trimming legacy files.
    [rp2350-rgb-pcb-B_Cu.gbl, rp2350-rgb-pcb-B_Mask.gbs, rp2350-rgb-pcb-B_Paste.gbp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]
2026-07-13 checkpoint: multi-session WIP before repo-wide audit/cleanup
    Accumulated working state from several sessions, committed as-is so the
    audit cleanup that follows is reviewable as its own diff:
    - firmware: phase6_parallel two-chain feature + tuning, new qc_test bin
    - sender: v2 packet work, new esp32-mic + espnow-dongle subprojects
    - render: pio_out/piobridge iteration, textures v2 channels, presets
    (incl. fonts/, raytop, radio-waterfall), egl/passes/pipeline touch-ups
    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
    [rayclose-cover-v2.stl, rayglow-base-v2.stl.stl, rp2350-rgb-pcb.kicad_pcb]
2026-07-13 audit: scale=2 default, transport-neutral config names, 4-lane fixes
    The rig has run the 4-lane parallel PIO bus as its production transport
    for weeks, but the code still carried SPI-era names and defaults:
    - --scale default 4 -> 2: supersampling beyond 2x adds nothing visible
    on physical LEDs and ~4x the GPU + readback cost (optimization-paths.md)
    - config.py constants renamed transport-neutral (they describe the wall
    and packer, not SPI): SPI_WIDTH/HEIGHT -> WALL_WIDTH/HEIGHT,
    SPI_GAMMA -> PACK_GAMMA, SPI_BITDEPTH -> BITDEPTH, SPI_FLIP_* -> FLIP_*,
    SPI_SINGLE_CHAIN -> SINGLE_CHAIN, SPI_PARALLEL -> PARALLEL_CHAINS,
    SPI_CHAIN_ORDER -> CHAIN_ORDER, SPI_ROW_ROTATE_180 -> ROW_ROTATE_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
    [__main__.py, egl.py, hub75.py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]
2026-07-13 audit: sync all docs to the PIO-default, mutagen-synced, post-HAT reality
    Multi-session drift left the docs describing three retired eras (SPI as
    production, git-pull/sshfs deploy, pre-HAT breadboard). Brought every
    tracked doc to current state:
    - README: v2 packet numbers (4236 B, ~0.25 MB/s), 64 KB frame timings,
    PIO listed as the default link, packer-owns-gamma corrected, Status
    reflects phase6 as hardware-verified production, deploy text made
    sync-method-agnostic
    - CLAUDE.md: pio_out default / spi_out fallback, phase 6 = production,
    "link frame" contract wording, mutagen sync model (replaces the
    retired ~/pi-mount note), esp32-mic/espnow-dongle in the repo map
    - TUNING.md: rew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
2026-07-13 optimization-paths: add next-wall scaling analysis + GPU pack-pass plan
    Quantifies every pipeline stage at 384x96 and 512x128: the RP2350's
    520 KB SRAM is the hard ceiling (384x96 fits at 288 KB double-buffered;
    512x128 needs 512 KB and does not), the link and refresh scale fine, and
    the one big Pi-side lever left is moving downsample+gamma+bitplane
    packing onto the GPU as a final pass.
    Claude-Session: https://claude.ai/code/session_0146hm4r7N6d5Xvqws4U1hiv
2026-07-13 tools: add DMA-BUF zero-copy readback feasibility probe
    Investigates optimization-paths.md item 2 empirically on the Pi 5:
    allocates from /dev/dma_heap/system, imports as a LINEAR ABGR8888
    EGLImage (V3D TLB stores raster natively), renders into it, and reads
    through a cached mmap bracketed by DMA_BUF_IOCTL_SYNC — the cached
    mapping is exactly what the failed PBO experiment couldn't get.
    Measured at scale 2 (300 frames/mode): dmabuf alone 1.04x (the fence
    wait is irreducible), dmabuf + a GPU resolve prototype 2.43x with zero
    added latency, 2.70x pipelined. Output byte-identical to glReadPixels;
    resolve pass within 1 LSB of the CPU postprocess.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
2026-07-13 render: GPU resolve pass + zero-copy dma-heap readback (2.4x, no latency)
    Lands optimization-paths.md items 2 (DMA-BUF), 3+4 (downsample + gamma
    as a shader pass), 8 (orientation in the shader), and the skip-unchanged
    half of 5 (uniform value caching in Pass._set).
    The image pass now feeds a panel-resolution resolve pass that
    box-averages, applies PACK_GAMMA, and flips (GL origin + config
    FLIP_V/H) on the GPU — the numpy postprocess stage is gone. Readback
    defaults to a dma-heap buffer read through a cached mmap
    (render/dmabuf.py); PBOs lost here because their mapping was uncached.
    --readback picks the path: auto (default, falls back to glReadPixels on
    non-Mesa stacks like the desktop), d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
    [__main__.py, dmabuf.py, egl.py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]
2026-07-13 docs: add ROADMAP.md handoff doc; archive optimization-paths to design-history
    ROADMAP.md queues the next four workstreams with enough grounding to
    start each session cold: the audio-v3 packet overhaul (open-ended —
    Will's brief section is his to fill), the runtime brightness side-band
    (spare top nibbles of the packed cells + set_oe_gain's live RAM table,
    no bit-depth cost), the now-playing/playlist playback architecture
    (file-copy through the existing mutagen sync; flags the multipass
    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
2026-07-13 sender: clean-room DAFx-09 predictive beat tracker (beat.py)
    Replaces the v2 autocorrelation heuristic that never correlated with the
    music: comb-filterbank tempo induction with Rayleigh + continuity priors,
    cumulative-score beat alignment (alpha=0.9, eta=5), and a slew-limited
    PLL beat grid whose beat_phase RAMPS INTO the predicted beat. Includes a
    phase-fold alternation test so off-beat hats don't lock the subdivision,
    and an offline click-track harness (uv run beat.py): 20/20 cases lock
    within 0.4% BPM / 20 ms phase across 4 seeds.
    Algorithm from Stark/Davies/Plumbley (DAFx-09) + Davies/Plumbley (TASLP
    2007); no GPL code ported.
    Cla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
2026-07-13 feed: packet v3 — 8 log bands, flywheel envelopes, thetas, onsets, key (wire)
    The cross-machine contract, changed in lockstep (sender / receiver /
    fake_sender) per the CLAUDE.md rule; v0/v1/v2 all stay accepted. 2996 B
    (was 4236): legacy header prefix unchanged (MilkDrop path still computes
    it), then band_imm[8] (20Hz-16kHz, per-band AutoGain, no equalize),
    band_env[8][3] (ENV_TIERS ballistics, sender-clock integrated),
    band_theta[8][3] (mod 200pi; integrates imm/env1/env2), band_onset[8],
    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
2026-07-13 feed+render: consume packet v3 — FeatureState fields, 16x3 milk, 128-bin spectrum
    FeatureState grows the v3 fields (bands, band_env/theta[8][3], band_onset,
    vol block, bar_phase, key) with neutral defaults so v0/v1/v2 senders render
    a calm flat state; _synthesize animates every new field with closed-form
    LFOs + theta integrals (stateless, drives all dry-run GIFs).
    MilkChannel 13x1 -> 16x3 and loses ALL Pi-side integration (DDT/ENV/THETA
    state deleted — the sender integrates on its steady clock now; d/dt is gone
    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
2026-07-13 docs: sync all docs to feed v3; archive the v3 design record; ROADMAP §1 shipped
    sender/README gets the v3 feature + packet tables and the old->new texel
    porting table; sender/CLAUDE.md gains the v3 invariants (no equalize on v3
    bands, beat.py is clean-room DAFx-09 not MilkDrop, feed_check after packet
    changes); root CLAUDE.md/README byte counts and verify recipes updated.
    Will's brief + decisions + the superseded v2 spec are archived as
    docs/design-history/2026-07-13-audio-feed-v3.md; ROADMAP drops the shipped
    section (remaining items renumbered, cross-refs fixed) and gains a small
    v3 tuning watch-list.
    Claude-Session: https://claude.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
    [__main__.py]
2026-07-13 presets: port all shaders to the v3 16x3 milk texel map
    Reference cards rewritten: milk-verbose = the 9-group band card (imm +
    three flywheel tiers + three theta saws + onset per band), milk-features =
    the row-2 globals card (predictive beat/bar ramps, key cells, stereo),
    milk-spectrum = 128-bin axis constants + the .y/.z smooth band-curve
    traces, REFERENCE.glsl = the new canonical fetch block. will-helix is the
    documented porting exemplar (old->new mapping in comments; drivers
    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
2026-07-16 render: control plane (push/media/scale) + per-shader scale directive
    A TCP control plane on the renderer (render/control.py, port 5006): the
    mutagen-free push dev loop + media controls, driven by tools/rayglow_ctl.py
    (+ the tools/nvim-rayglow.lua save-hook). push ships a local .glsl to the
    running renderer in <100ms and returns compile errors; load/next/prev/play/
    pause/loop/repeat/reload/status are the playback controls. Commands run on the
    render thread via a queue (GL is thread-affine); PlayerState holds all state.
    Runtime supersample scale rides the same full-rebuild switch path: precedence
    is --scale / runtime `scale` command > `// rayglow: scale=N` directive (new
    textures.parse_setti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
    [__main__.py, control.py, textures.py]
2026-07-16 hardware: wall v2 (384x128, 6x4 P4) power + frame docs
    Document the in-progress v2 wall: 6 wide x 4 tall P4-2121-64x32 tiles =
    384x128 (1536x512 mm), 2x 5V/300W/60A supplies, 2020 T-slot frame. Adds a
    two-supply star-ground section to POWER-AND-GROUNDING (incl. the note that
    2x300W covers audio-reactive content but not a sustained all-white 24-panel
    frame) and a Wall v2 status block to the hardware README. Transport (two
    RP2350s vs the FPGA translator) stays an open bring-up decision; the P4 frame
    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
2026-07-18 render+firmware: drive the full 6x4 wall (384x128) from one RP2350b
    Serpentine fold (hub75.to_chains) + PANEL_COLS/PANEL_ROWS geometry;
    firmware PANELS_IN_CHAIN 4->12, OE_GAIN 64->192.
    Measured SRAM ceiling is 15 panels/chain (30 total), so all 24 tiles fit
    on ONE RP2350b at 75% of the 512 KB pool -- the two-RP2350/FPGA split the
    ROADMAP assumed is unnecessary. The u16 cell packs both chains, so RAM
    scales with chain width alone; ceiling found by linking phase6-parallel
    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
2026-07-21 Add --output kms: render straight to the DPI framebuffer for the FPGA translator
    New KmsOut sink (kms_out.py) mmaps /dev/fb0 and blits the resolved (H,W,3)
    RGB frame to its top-left; the ECP5 FPGA does the HUB75 fold + gamma (CIE
    LUT) + BCM scan-out. run_kms mirrors run_wall's live loop (control plane,
    --loop, feed, pausable clock) minus fold/pack/transport. --output kms forces
    resolve gamma=1.0 (FPGA owns gamma). Proven on hardware: renderer -> fb0 ->
    FPGA -> panel at 64x32.
    Claude-Session: https://claude.ai/code/session_01P4VMMc4Avuzwtk9YUeZL4U
    [__main__.py, kms_out.py]
2026-07-30 kms: vsync-paced blits (DRM WAIT_VBLANK) - tear-free, locks to display refresh
    _VBlank finds the DRM card backing the fbdev via sysfs parent-device match
    (robust to card renumbering) and waits for vertical blank before each blit,
    so the scanout never reads a half-written frame. Falls back to unpaced with
    a note if the driver refuses. Also: FLIP_H/V=True for the rotated FPGA-rig
    mount (baked into the GPU resolve pass, zero latency).
    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
    [__main__.py, kms_out.py]
2026-07-30 kms: direct DRM page-flip backend; fbdev shadow-buffer tearing root-caused
    /dev/fb0 on the DPI is fbdev EMULATION - a cached shadow buffer (writes
    measured 0.02ms = ~10GB/s, not scanout memory) whose kernel worker copies
    page-sized chunks (4KB = ~2.7 rows) to the real buffer unsynced to vblank:
    the fine-banded tearing that survived vblank-paced blits. New drm_out.py
    (pure ctypes, no libdrm): DRM master, 2 dumb buffers, SETCRTC once, then
    PAGE_FLIP per frame with event-paced loop - hardware tear-free. kms_out
    gains prepare-before-wait split + wait/write/missed instrumentation (via
    WAIT_VBLANK reply sequence). --kms-backend auto|drm|fbdev, auto prefers drm.
    Live on the wall: 384x480 XR24, writ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
    [__main__.py, drm_out.py, kms_out.py]
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2026-08-03 link: remote-render frame transport — --output net ⇄ rayglow.framesink (Phase 2)
    The fourth cross-machine contract: resolved RGB frames, render host -> Pi.
    - rayglow/link.py — the wire protocol both ends import: 24 B fragment
    header (explicit byte offsets, so MTU 1500 and 9000 senders interop),
    32 B credit, RFC1982 seq compare, latest-wins Reassembler (a lost
    fragment costs its frame, never a stall; a STALE_RESET run of stale
    fragments resyncs a warm sink to a restarted sender), and the
    CreditLedger: flip-sourced tokens capped at the window + an inflight
    belt. Skips deliberately don't replenish — that trim is what stops a
    fast GPU from settling into render-2x-show-half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
    [__main__.py, net_out.py]
2026-08-03 docs: remote render in the repo map + CLAUDE.md; plan §11 as-built runbook
    README/CLAUDE.md: rayglow/link.py + rayglow/framesink.py + link_check in
    the maps and the verify list. REMOTE-RENDER-PLAN.md: status -> built,
    plus §11 — what shipped, the three findings that amend the plan (NVIDIA
    now implements the surfaceless platform; §5.5 credits refined to
    flip-sourced tokens so a fast GPU can't settle into render-2x-show-half;
    jumbo opt-in until pinged through), and the bring-up runbook
    (ubuntu-server setup, framesink, acceptance, mutagen fan-out).
    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
2026-08-03 hardware: nudge vias clear of pad clearances on the RGB HAT (~2 mm shifts)
    Findings from debugging the bad HAT (the fried-'245 chain): reviewing the
    layout for via-to-pad spacings that could short under fault, a few vias sat
    close enough to live pads to be worth moving. No net or footprint changes —
    revised board files for any future reorder.
    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
    [rp2350-rgb-pcb.kicad_pcb]
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
